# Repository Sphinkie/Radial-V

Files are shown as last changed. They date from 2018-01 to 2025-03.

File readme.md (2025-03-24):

# Radial-V

## Présentation

Remise en fonctionnement d'un poste de TSF, avec radio FM, player MP3, et afficheur LCD.

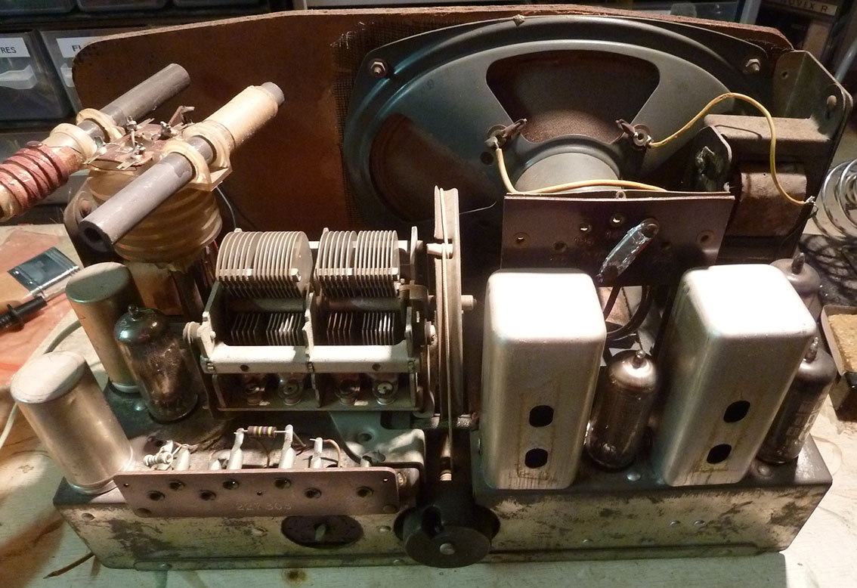
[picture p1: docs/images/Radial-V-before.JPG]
Radial-V-before


## Fabrication

Plusieurs éléments ont été réalisés: logiciel, circuits électroniques et supports en PLA.

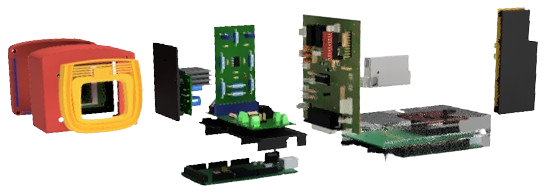
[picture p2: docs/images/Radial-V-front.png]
Radial-V-front


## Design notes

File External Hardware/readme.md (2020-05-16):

# RADIAL-V

## External Hardware

Ce dossier contient les cartes électroniques (shields) achetés pour construire le Radial-V:

* Amplificateur Audio
* Cartes Arduino Mega
* Radio FM
* Player MP3
* Ecran TFT

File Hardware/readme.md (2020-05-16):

# RADIAL-V
## Schematics

Ce repository contient l'ingénérie des différents circuits imprimés réalisés.

##Fabrication des PCB

Pour générer avec [kiCad](https://kicad-pcb.org/ "open source CAO software" ) les fichiers à envoyer à [JLB PCB](https://jlcpcb.com/	"PCB assembly from 2$"):

**kiCad → Pcbnew → File → Plot...**

* Plot format: Gerber
* Output directory: Gerber\
* Included layers: F.Cu B.Cu F.SilkS B.SilkS F.Mask B.Mask Edge.Cuts
* Plot footprint values
* Plot footprint references
* Exclude PDB edge layer from other layers
* Exclude pads from silkscreen

**Plot**
* Generate Drill Files...
* Generate Drill Files

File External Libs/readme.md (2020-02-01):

# Radial-V

## Utilisation des librairies:

### Possibilité 1:

Ajouter la librairie à l'environnement IDE Arduino.

Menu -> Include Library -> Add .zip library ...

`#include <NewLib.h>`

### Possibilité 2:

Ajouter manuellement la librairie à l'environnement IDE Arduino.

Dezipper la librarie dans `Documents\Arduino\libraries` et relancer l'IDE Arduino.

`#include <NewLib.h>`

### Possibilité 3:

Donner le chemin de la librairie (*à vérifier*):

`#include "..\lib\NewLib.h"`

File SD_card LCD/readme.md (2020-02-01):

# RADIAL-V

## SD Card LCD

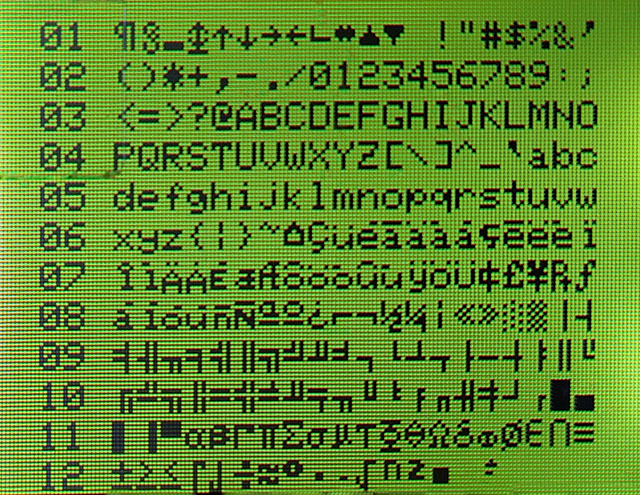
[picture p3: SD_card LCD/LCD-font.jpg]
Background sample


Ce dossier contient les éléments nécessaires pour la carte SD du shield "Ecran LCD":

* **/Preparation** - Différents elements utiles à la préparation de la carte SD (pictos, images de fond...)
* **/SD-card** - Contenu typique de la carte SD.

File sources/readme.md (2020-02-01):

# RADIAL-V

## Code source

* **/Radial-V** - Ce repository contient les sources du programme pour l'Arduino 1 (*master*). Il s'agit du programme principal.

* **/Radial-Screen** - Ce repository contient les sources du programme de l'Arduino 2 (*slave*). Ce programme est chargé de l'affichage des informations sur l'écran LCD.

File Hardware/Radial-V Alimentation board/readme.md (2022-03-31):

# RADIAL-V

## Alimentation Board

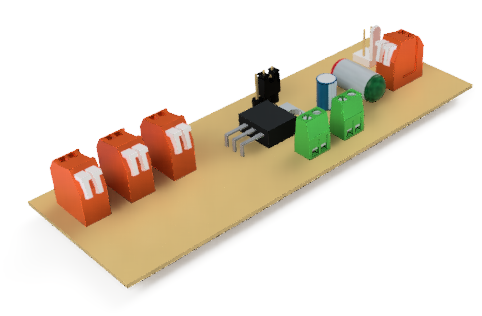
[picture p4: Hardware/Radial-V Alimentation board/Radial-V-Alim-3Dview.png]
Radial-V-Alim-3Dview


Cette carte distribue l'alimentation **5v** vers les autres cartes du système et le **12v** vers les amplicateurs audios.

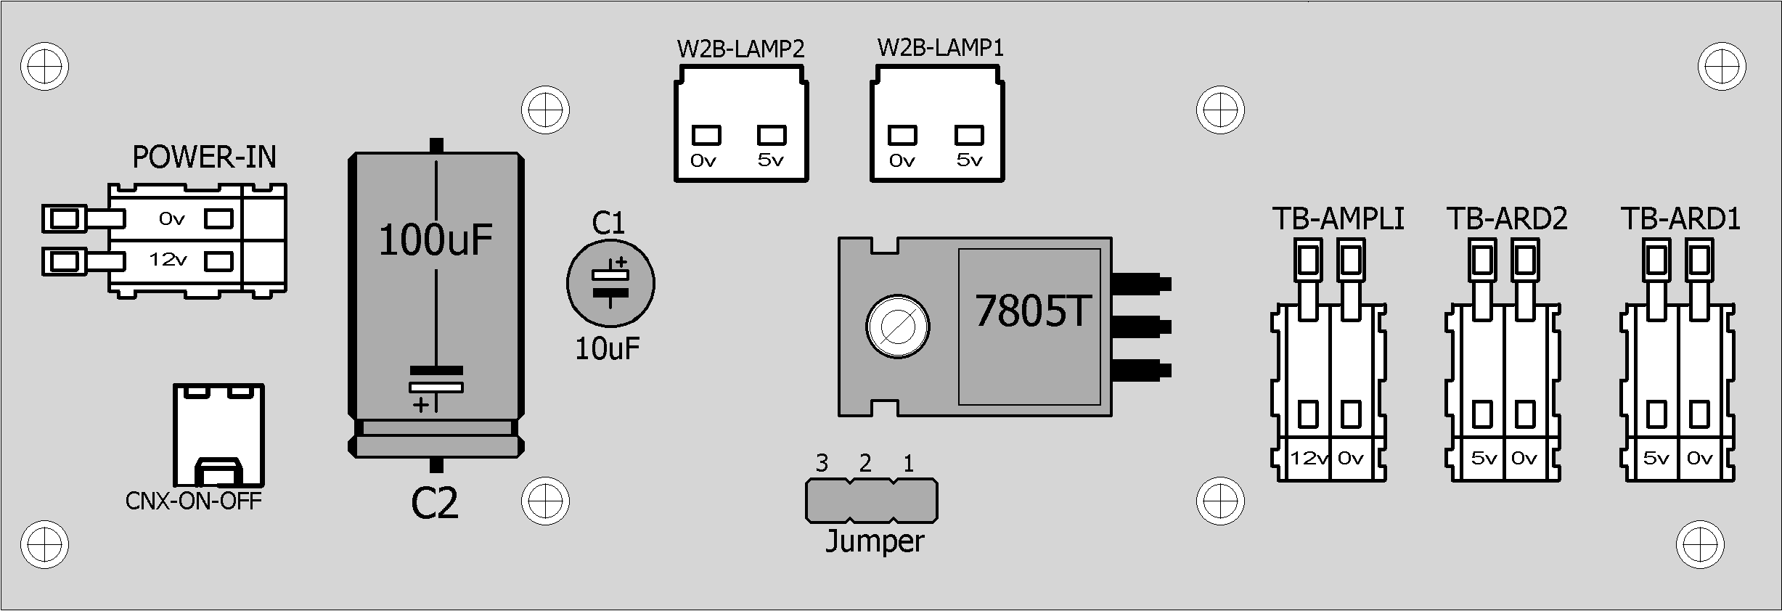
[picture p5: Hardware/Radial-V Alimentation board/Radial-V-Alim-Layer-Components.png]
Radial-V-Alim-Layer-Components


### Les Entrées:
* POWER-IN : Alimentation externe 12v (VCC)
* CNX_ON_OFF : Bouton ON/OFF externe
* Jumper: Permet d’alimenter les Arduino en VCC (12v) ou en +5v

## Schematic & PCB

Compatibles avec le logiciel **Eagle**.

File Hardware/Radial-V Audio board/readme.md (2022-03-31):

# Radial-V

## Carte "Audio-Board"

Cette carte fait passer la sortie audio (en provenance de la carte "Extension Bus") par un préamplificateur (optionnel), un potentiomètre de volume, et un Amplificateur mono. Le haut-parleur (4 ou 8 ohms) peut être branché directement sur "Audio OUT".

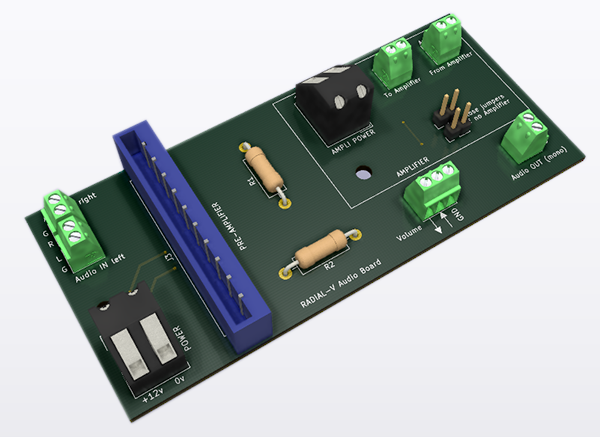
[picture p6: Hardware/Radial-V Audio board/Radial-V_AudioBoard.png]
Radial-V Audio Board


### Schéma d'implémentation

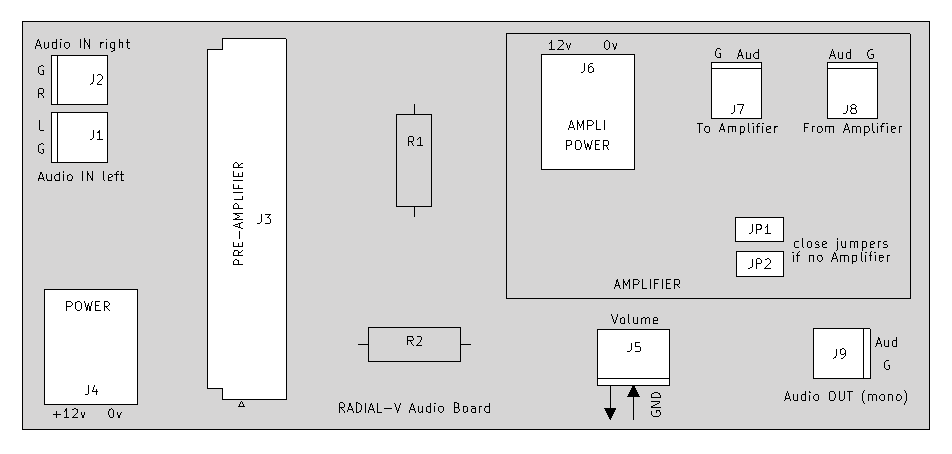
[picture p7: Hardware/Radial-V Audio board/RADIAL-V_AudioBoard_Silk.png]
RADIAL-V Audio Board Silk


Note: Le PréAmplificateur a été remplacé par une carte *Shunt*.

Schémas et PCB compatibles avec le logiciel **KiCad** (freeware).

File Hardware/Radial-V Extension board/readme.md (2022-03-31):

# RADIAL-V

## Extension Board

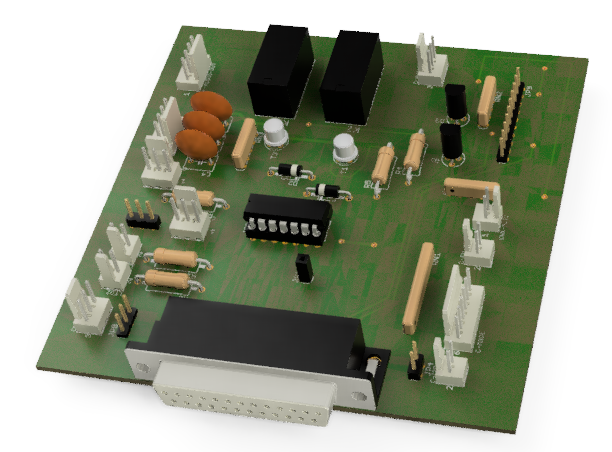
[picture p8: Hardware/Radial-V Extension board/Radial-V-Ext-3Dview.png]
Radial-V-Ext-3Dview


Cette carte regroupe tous les capteurs et actuateurs (boutons, LEDs, etc) du système et les envoie sur une nappe 25 fils vers l'Arduino.

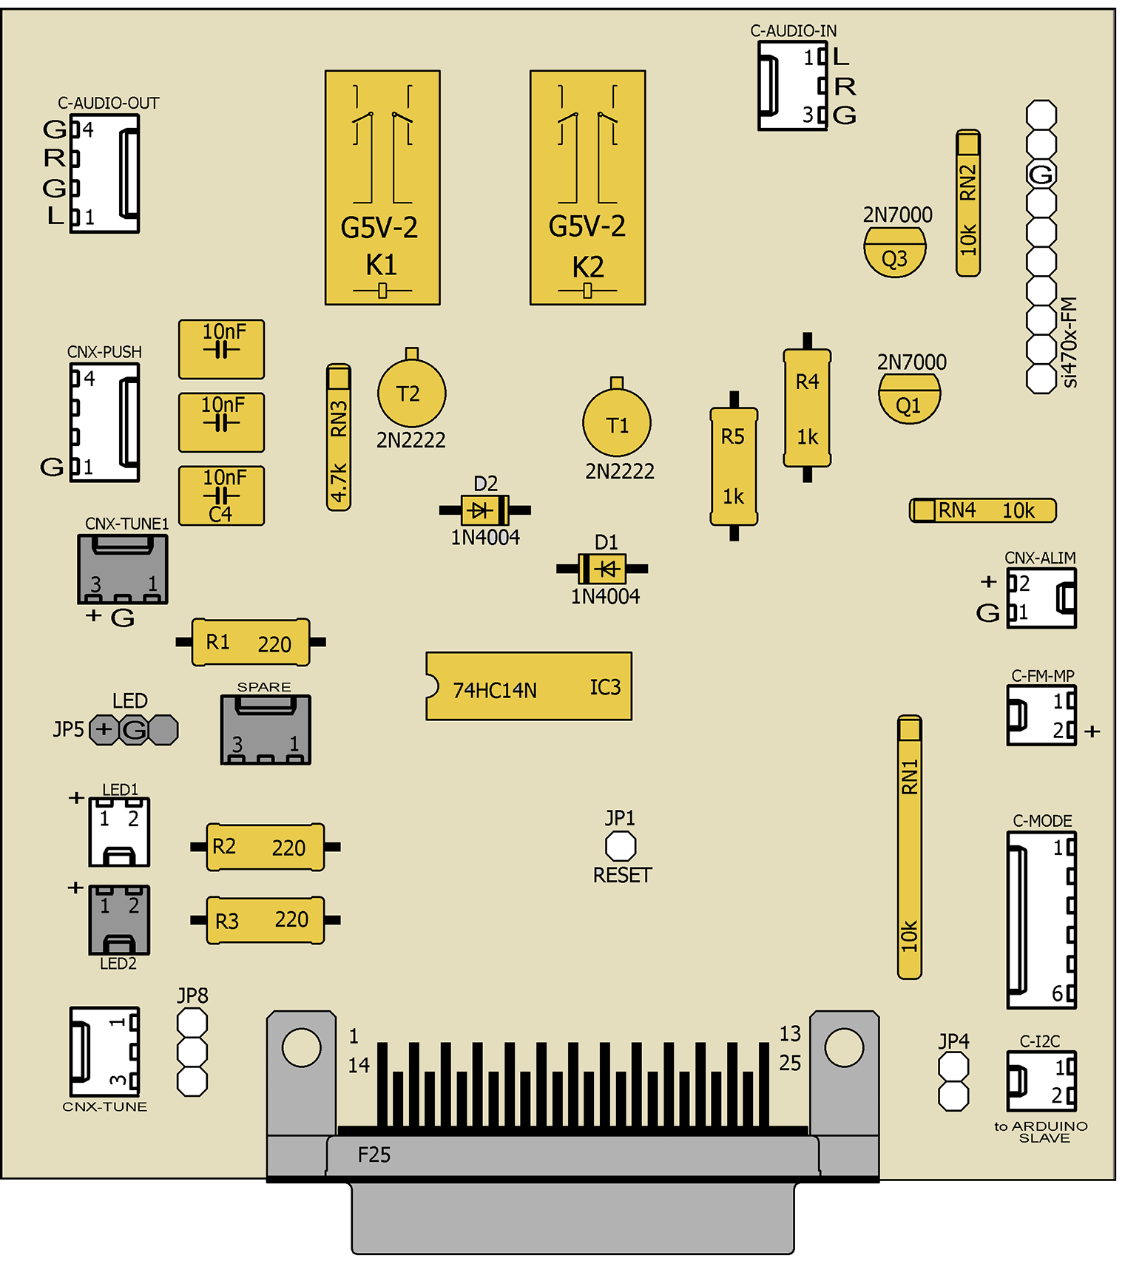
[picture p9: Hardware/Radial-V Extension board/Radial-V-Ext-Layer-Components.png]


Le circuit intégré 74HC14 est un *trigger de Schmitt inversé* qui, associé aux capacités, supprime les rebonds des boutons poussoirs, et transforme les impulsions en signaux carrés propres inversés (*active high*).  
Les *relais* servent à commuter le signal audio de sortie soit de la source "Carte MP3", soit de la source "Carte radio FM".  
Les composants *grisés* sont des spares non utilisés.

Schémas et PCB compatibles avec le logiciel **Eagle**.

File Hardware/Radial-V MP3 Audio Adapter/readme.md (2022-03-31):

# Radial-V

## Mini-Carte "Audio-Adapteur"

Cette minicarte réalise une adaptation du signal audio entre la carte MP3 et la carte audio d'amplification, telle que recommandée dans la documentation de la carte MP3.

*En particulier, le GNDbuf sortant de la carte MP3 ne doit pas être relié à la masse, ni utilisé.*

La carte a été fabriquée sur un Veroboard (pas de PCB).

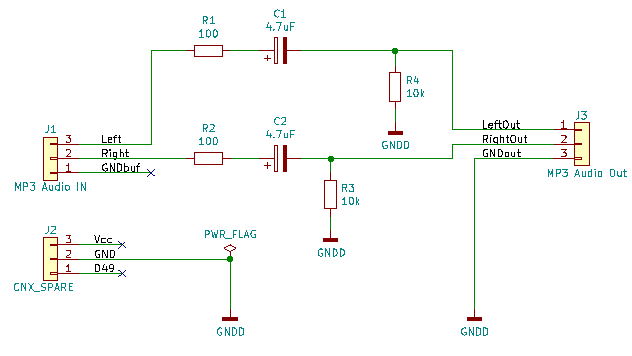
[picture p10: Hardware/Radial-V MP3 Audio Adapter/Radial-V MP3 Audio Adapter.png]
Radial-V MP3 Audio Adapter


Le branchement sur le connecteur *CNX_SPARE* permet de récupérer un signal GND.

Schémas et PCB compatibles avec le logiciel **KiCad** (freeware).

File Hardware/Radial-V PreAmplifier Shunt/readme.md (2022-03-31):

# Radial-V

## Mini-Carte "PreAmplifier Shunt"

Le préamplificateur initialement prévu s'est avéré inutile: le signal en sortie de l'ampli étant alors trop puissant. Le préamplificateur a donc été remplacé par cette mini-carte de *shunt*.

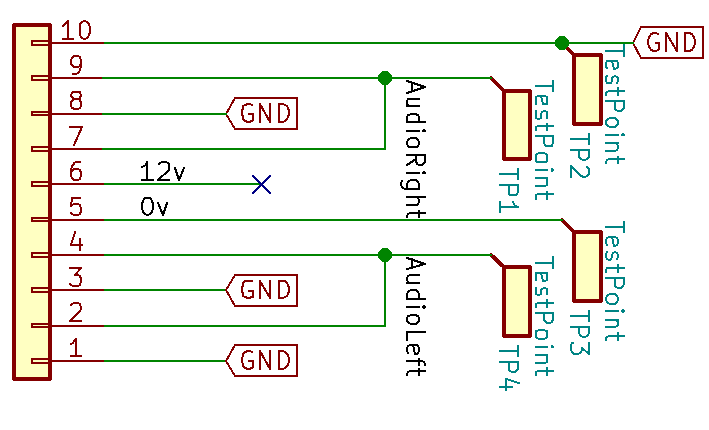
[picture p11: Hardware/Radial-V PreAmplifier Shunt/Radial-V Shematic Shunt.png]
Radial-V Shematic Shunt

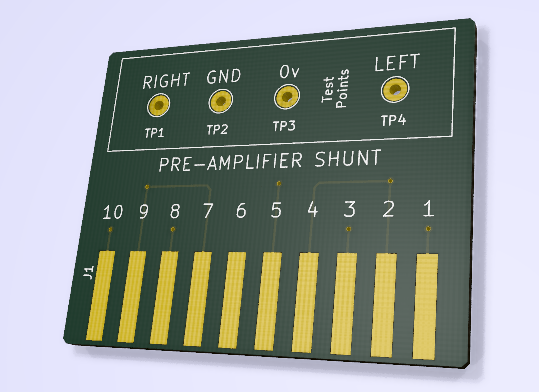
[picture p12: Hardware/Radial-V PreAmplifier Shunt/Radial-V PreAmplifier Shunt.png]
Radial-V PreAmplifier Shunt


Schémas et PCB compatibles avec le logiciel **KiCad** (freeware).

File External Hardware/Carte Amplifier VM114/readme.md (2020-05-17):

# RADIAL-V

## Amplifier Board

Module Amplificateur Audio MONO (7W avec HP 4ohms / 4W avec HP 8ohms).

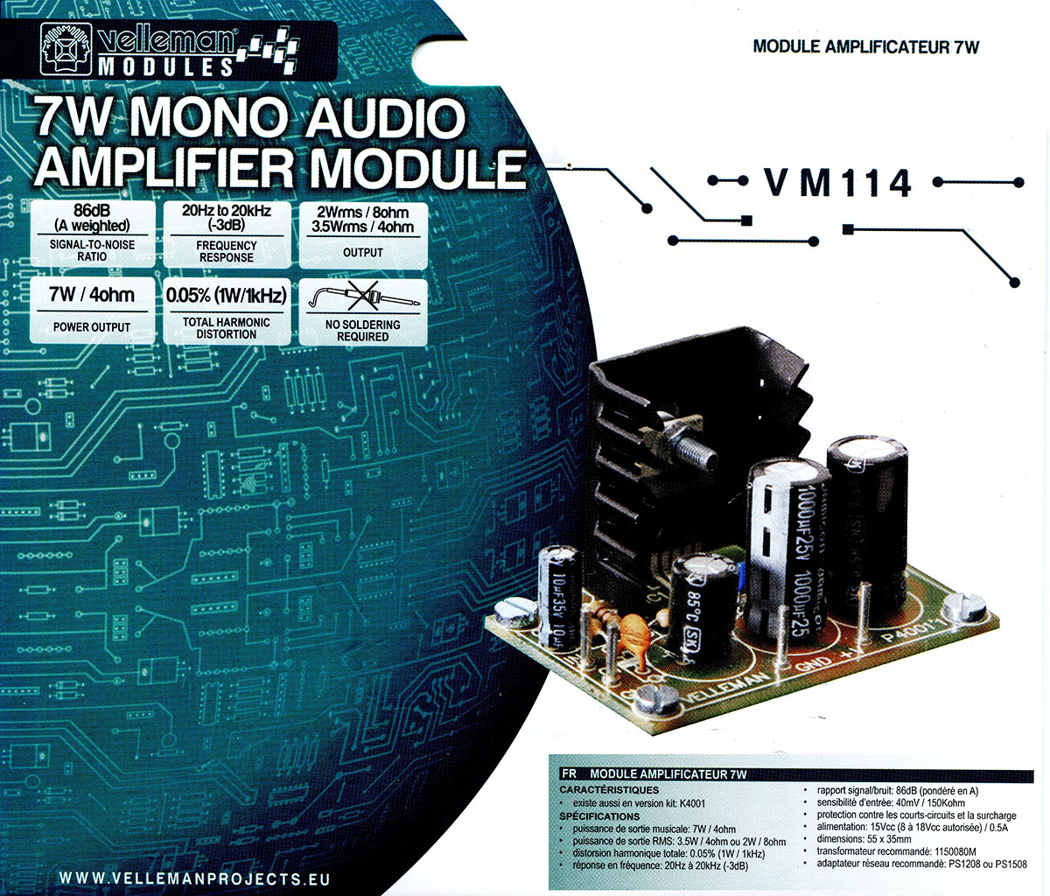
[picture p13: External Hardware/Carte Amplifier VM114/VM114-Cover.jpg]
Kit Velleman


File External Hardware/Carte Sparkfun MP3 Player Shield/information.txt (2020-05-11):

-- Introduction
-----------------
The Arduino SFEMP3Shield Library is a driver for VSLI's VS10xx, implemented as a Slave co-processor to audio decode streams of Ogg Vorbis/MP3/AAC/WMA/FLAC/WAVMIDI formats, across the SPI bus of the Arduino, along with mixing input signals. Principally this library is developed for the VS1053, where it may be compatible with other VS10xx's

Initial development was implemented on an Arduino 328 UNO/Duemilanove with a SparkFun MP3 Player Shield. Where additional support has been provided for Arduino base systems and Shields. Hardware and documentation is provided as to how to implement these. Where this driver is modular in concept to allow ready porting to other Arduino or Wiring platforms.

-- Contributors
-----------------
Nathan Seidle, www.sparkfun.com
Bill Porter, www.billporter.info
Michael Flaga, www.flaga.net
Wade Brainerd

-- Software Requirements
------------------------
- Arduino IDE
- The most current SFEMP3Shield Driver
- SdFat Driver, while included a newer version may retrieved from SdFatLib' repository.
Optionally, used if Hardware Interrupts are not supported:
- SimpleTimer.h . library can be downloaded from for library.
- TimerOne.h . library can be downloaded from for library.

-- Hardware Requirements
------------------------
- 5V Arduino 328 UNO/Duemilanove or better.
- Shield or breakout with appropiate pins wired up.
- Shield or breakout for SdCard
- SdCard FAT formatted with valid Audio files and filenames
See Hardware for alternative solutions.

Note
This library was originally developed on IDE 0.2x, later ported to 1.x and best support on IDE 1.5.0+ going forward. Compatibility was lost with use of the Serial.print(F("...")) and can be restored by replacing it with SdFat's PgmPrint function

-- Installation
------------------
Unzip and place './SFEMP3Shield' and './SdFat' folder into your 'C:/Users/{user name}/Documents/Arduino/libraries' folder or '{Arduino IDE path}/hardware/libraries" or {Arduino IDE path}/libraries" directory.
Along with SimpleTimer and or TimerOne if needed. 
Restart the Arduino IDE, and open up the example sketch.
Copy the contents of this projects the './plugins' folder onto the root of the SdCard to be used. Along with desired audio files named appropriately; track001.mp3 through track009.mp3.
The plugins and audio files are not needed to be placed into the Arduino directories as they are not directly a part of the compiled project.
Start IDE, load Example MP3Shield_Library_Demo.ino, select appropriate Board, Serial Port, Compile, load, run Serial Monitor at 115200 baud rate.
May need to Reset target Arduino and wait for Menu.
An example is provided in the SFEMP3Shield/examples folder. Which is developed to test SFEMP3Shield and illustrate its various common uses.

-- Hardware
---------------
As mentioned the initial and principal support of this library is with Arduino 328 UNO/Duemilanove with a SparkFun MP3 Player Shield. Although various other boards and shields may be implemented by customing the SFEMP3ShieldConfig.h file.

-- Arduino Bare Touch
----------------------
Support for Bare Conductive's Touch Board is provided and documented in SFEMP3ShieldConfig.h.

Note
Reference Arduino Leonardo Board's note about example files.

--Arduino Mega Board
-----------------------
Support for Arduino and Seeeduino Mega's are documented in SFEMP3ShieldConfig.h, which simply REQUIRES additional jumpers. As the SPI are not on the same pins as the UNO/Duemilanove.

-- Arduino Leonardo Board
-------------------------
Support for Arduino Leonardo's are afflicted by having the SPI and INT0 pins not routed to the same pins as the UNO/Duemilanove. This is similar to the Arduino Mega. Which simply REQUIRES additional jumpers, as documented in SFEMP3ShieldConfig.h to correct the SPI. The swapping of INT0/INT1 is automatically corrected based on the Leonardo's processor type of AVR_ATmega32U4 being detected.

Note
While the Leonardo has the same amount of physical program space as the UNO, it actually has less space available for use. As it uses approximately 4K, for core library USB features. Where there is adaquate space available for typical applications, the provided example files MP3Shield_Library_Demo.ino and FilePlayer.ino will compile a reduced set of examples based on the processor type of AVR_ATmega32U4 being detected. This is only for the demonstration, and other sketchs may call any of these functions, given its environment.
Arduino Pro 5V vs 3V

SFE Arduino Pro's while similar to UNO/Duemilanove's pin outs, they are available in either 5V or 3.3V. Where the SFE MP3 Player Shield requires 5V and locally generating the needed 3.3V and 1.8V for the VS10xx chip. Noting that 3.3V Pro's do not supply 5V, this causes a problem. It is possible to modify the shield as to use base Arduino supplied 3V's.

-- SparkFun MP3 Player Shield
-----------------------------
SparkFun MP3 Player Shield should just work out of the box (bag) with a Arduino 328 UNO/Duemilanove, with Interrupts.

-- Seeduino MP3 Player Shield
-----------------------------
Support for Seeduino MP3 Player Shield please see SEEEDUINO and may require additional libraries, as per Requirements

-- MP3-4NANO Shield
-------------------
Support for Gravitech MP3-4NANO shield please see GRAVITECH

-- Limitations.
---------------
The SPI Bus: The configuration of the VS10xx chip as a Slave on the SPI bus, along with the SdCard on that same bus master hosted by the Arduino. See Performance
Non-Blocking: The controlling sketch needs to enquire via SFEMP3Shield::isPlaying as to determine if the current audio stream is finished or still playing. This is actually good and a result of the library being non-blocking, allowing the calling sketch to simply initiate the play of a desired audio stream from SdCard by simply calling playTrack or playMP3, of the desired file, and move on with other RealTime issues.
Multi-Chip VS10xx support: Not at this time. There are too many issues with member functions of the SFEMP3Shield class requiring to be static.
Audio Input Most commericially available shields at this time do not support either Line Level or Microphone Input. With the exception of the Seeeduino MP3 Shield and other home made shields. Where as the below admx____.053 and SFEMP3Shield::ADMixerLoad and SFEMP3Shield::ADMixerVol are provided for such devices. Otherwise the example MP3Shield_Library_Demo.ino has these lines commented out in setup(). As to reduce complications. To re-enable simply uncomment.
Recording As most commericially available shields do not support audio input this feature has not been implemented.

-- Todo:
--------
- Support Audio Recording.

-- Performance
--------------
Understanding that every byte streamed to the VS10xx needs also to be read from the SdCard over the same shared SPI bus, resulting in the SPI bus being less than half as efficient. Along with overhead. Depending upon the Bitrate of the file being streamed to the VSdsp, there is only so much Real Time available. This may impact the performance of high bit-rate audio files being streamed. Additionally the Play Speed Multiplier feature can be exhausted quickly. Where on a typical UNO there is plenty of real-time to transfer good quality files, with CPU to spare for other tasks, assuming they do not consume too much time either.

The available CPU can be increased by either or both increasing the speed of the SPI and or the Arduino F_CPU. Where the Speed of the SPI is individually maintained by both this driver and SdFatLib. As not to or be interfered with each other and or other libraries using the same SPI bus. The SdCard can be increased from SPI_HALF_SPEED to SPI_FULL_SPEED argument in the SD.begin. Where this library will set the Read and Write speeds to the VSdsp correspondingly, based on F_CPU of the Arduino.

The actual consumed CPU utilization can be measured by defining the PERF_MON_PIN to a valid pin, which generates a low signal on configured pin while servicing the VSdsp. This is inclusive of the SdCard reads.

The below table show's typical average CPU utilizations of the same MP3 file that has been resampled to various bit rates and using different configurations. Where a significant difference is observed in performance.

BitRate	SdCard	Refilling	IDLE
128K	Half	12%	88%
128K	Full	10%	90%
96K	Full	7%	93%
56K	Full	4%	96%
Note
Only F_CPU of 8MgHz and 16Hz are supported. Others will default to SPI_CLOCK_DIV2, assuming 4MgHz.

-- Plug-Ins and Patches
------------------------
The VS10xx chips are DSP's that run firmware out of ROM, that is internal to the VS10xx chip itself. Where the VSdsp's RAM can additionally be loaded with externally provided firmware and executed, also known as patches or plug-ins, over the SPI port and executed. This allows the VSdsp to have a method for both fixing problems that may exist in the factory ROM's firmware and or add new features provided by VLSI's website. It is even possible to write your own custom VSdsp code, using there Integrated Development Tools (VSIDE).

vs_plg_to_bin.pl is a perl script, that is provided in this library to run on your PC, to read and digest the .plg files converting them to raw binary as to be read by SFEMP3Shield::VSLoadUserCode() from the SdCard. Allowing updates to the VSDsp into its volatile memory after each reset. These updates may be custom features or accumulated patches.

By storing them on the SdCard these plug-ins do not consume the Arduino's limited Flash spaces

Below are pre-compiled binary's of corresponding provided VSLI patches/plugins. The filenames are kept short as SdCard only support 8.3.

.\pcm.053       .\vs1053-pcm110\vs1053pcm.plg
.\admxleft.053  .\vs1053b-admix130\admix-left.plg
.\admxmono.053  .\vs1053b-admix130\admix-mono.plg
.\admxrght.053  .\vs1053b-admix130\admix-right.plg
.\admxster.053  .\vs1053b-admix130\admix-stereo.plg
.\admxswap.053  .\vs1053b-admix130\admix-swap.plg
.\patchesf.053  .\vs1053b-patches195\vs1053b-patches-flac.plg
.\patches.053   .\vs1053b-patches195\vs1053b-patches.plg
.\rtmidi.053    .\vs1053b-rtmidistart\rtmidistart.plg
.\eq5.053       .\vs1053b-eq5-090\vs1053b-eq5.plg

-- Note
-------
All plugins should be placed in the root of the SdCard.
patches.053 is a cumulative update correcting many known troublesome issues. Hence patches.053 is attempted in SFEMP3Shield::vs_init.
VSLI may post periodic updates on there software website
Perl is natively provided on Linux systems, and may be downloaded from Active Perl for windows systems.
See Also
about Analog to Digital Mixer (e.g. admx____.053) please note Limitations.

-- Troubleshooting
------------------
The below is a list of basic questions to ask when attempting to determine the problem.

- Did it initially PRINT the available RAM and Full Help Menu?
The MP3Shield_Library_Demo.ino example should initially provide a opening print indicating the amount of available SRAM and full menu help. If you don't see this the problem is between your Target and IDE. And likely not this library
Is Serial Monitor set to the correct tty or com port and 115200 baud rate? Did you change the baud rate?
Reset the Arduino after Serial Monitor is open or send any key. It may have printed these prior to the Serial Monitor being started.

- WHAT is the Error reported?
  Is the Error Code is indicating a file problem.

- Are the filenames 8.3 format? 
  See below warning. See also Error Codes.

- Did the SdCard LOAD?
  Try reseating your SdCard.

- Is MP3player.begin() locking up, in setup()?
  Are you trying to update from a version prior to 1.01.00?

- Why does my Serial Monitor display: "...do not have a sd.begin in the main sketch, See Trouble Shooting Guide."
- Why do I have a Compiler Error: "...undefined reference to `sd'"
- Why is the last thing printed to the Serial Monitor: "Free RAM = 1097 Should be a base line of 1095, on ATmega328 when using INTx" then nothing...
  Versions after 1.01.00 require the SdFat::begin() to be initialized in the main sketch.ino, as shown in the below example. This provides more immediate access to the SdCard's files by the main sketch. However, if not done there is no immediate compiler error and the sketch will lock up after as it attempts SFEMP3Shield::begin.
  ...
  SdFat sd; // newly required in 1.01.00 and higher
  void setup() 
  {
     if(!sd.begin(SD_SEL, SPI_HALF_SPEED)) sd.initErrorHalt(); // newly required in 1.01.00 and higher
     if(MP3player.begin() != 0) {Serial.print(F("ERROR"));
     ...
	 
- Is it FAT (FAT16 or FAT32)?
  If the Error Code is indicating problems with the INIT, VOLUME or Track not being successful. It is recommend to use SdFat Example Library's QuickStart.ino as to see if it can access the card. Additionaly, SdInfo.ino may indicate if it can mount the card. Which may then need to formatted in FAT16 or FAT32. Where SdFormatter.ino can do this for you.
  
- Are the needed files on the root?
  Remember to put patch and audio track files on the SdCard after formatting.

- "Error code: 1 when \b trying to play track"
  See the above Limitations. about Non-Blocking.
  Remember to check your audio cables and volume.
  
- "Warning: patch file not found, skipping."
  See the Plug Ins and Patches
  
- Why do I only hear 1 second of music, or less?
  This symptom is typical of the interrupt not triggering the SFEMP3Shield::refill(). 
  I bet repeatidly sending a track number will advance the play about one second at a time, then stop.
  
- What board is it? 
  Check Hardware Limitations. about Interrupts.
  
- Are you trying the SFE provided test files ? Or some homemade mp3 files? 
  The SFE test files are nice as they are Immediately LOUD.
  Interrupt problems may cause mp3 files that have a quiet lead in (or ramp up of volume) to be falsely diagnosed as not playing at all. Where the first 1 second may not be loud enough to be heard.

- Free RAM = 1090 Should be a base line of 1094
  As a courtesy and good practice the provided example MP3Shield_Library_Demo.ino prints out the available remaining RAM, not statically allocated. And the actual available amount may depend on specific processor, IDE version, libraries and or other factors. A Uno built with IDE version 1.0.2 should have approximately 1094 bytes available from the example as is. And a Mega using a 2560 may show 6713, as it has more RAM.

-- Note
--------
This library makes extensive use of SdFat Library as to retrieve the stream of audio data from the SdCard. Notably this is where most failures occur. Where some SdCard types and manufacturers are not supported by SdFat. Though SdFat Lib is at this time, supporting most known cards.

-- Warning
-----------
SdFatLib only supports 8.3 filenames. Long file names will not work. Use the 'd' menu command to display directory contents of the SdCard. "longfilename.mp3" will be converted to "longfi~1\.mp3" . Where one can not predict the value of the 1. The DOS command of "dir \c /x" will list a cross reference, so that you know exactly, what is what.

-- Error Codes
--------------
Error Codes typically are returned from this Library's object's in place of Serial.print messages. As to both save Flash space and Serial devices may not always be present. Where it becomes the responsibility of the calling sketch of the library's object to appropiately react or display corresponding messages.

- begin function:

The following error codes return from the SFEMP3Shield::begin() member function.

0 OK
1 *Failure of SdFat to initialize physical contact with the SdCard
2 *Failure of SdFat to start the SdCard's volume
3 *Failure of SdFat to mount the root directory on the volume of the SdCard
4 Other than default values were found in the SCI_MODE register.
5 SCI_CLOCKF did not read back and verify the configured value.
6 Patch was not loaded successfully. This may result in playTrack errors

- Deprecated:
Error codes 1,2,3 due to use of sd.begin() as global, starting version 1.1.0

- Playing functions:

The following error codes return from the SFEMP3Shield::playTrack() or SFEMP3Shield::playMP3() member functions.

0 OK
1 Already playing track
2 File not found
3 indicates that the VSdsp is in reset.
Skip function:

The following error codes return from the SFEMP3Shield::skipTo()member function.

0 OK
1 Not Playing track
2 Failed to skip to new file location

-- Support:
-----------
The code has been written with plenty of appropiate comments, describing key components, features and reasonings in Doxygen markdown style as to autogenerate this html suppoting document. Which is loaded into the repositories' gh-page branch to be displayed on the projects's GitHub Page.

Additional support may be reached from any of the following: Please read through this document and refering linked resources.

Bills WordPress forum
Flaga's github Issues forum
Bill's github Issues forum

-- Note
--------
Problems with SdCard initializing is outside the scope of this library. 
SdFatLib' repository was selected being the best choice.

-- References
--------------
See Also:

- VS1053 Datasheet.
- VLSI's DSP support Forum.
- VLSI's software download of Apps, Patches, Plugins and tools.
- VS10XX AppNote: Connecting analog outputs.
Sparkfun Electonics:
- MP3 Player Shield DEV-10628.
- MP3 Player Shield Landing Page / Tutorials.
- SFE's Schematic.
Adafruit Industries:
- The Arduino site.
- The ATmega328 datasheet.

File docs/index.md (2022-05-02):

# Vintage MP3 player

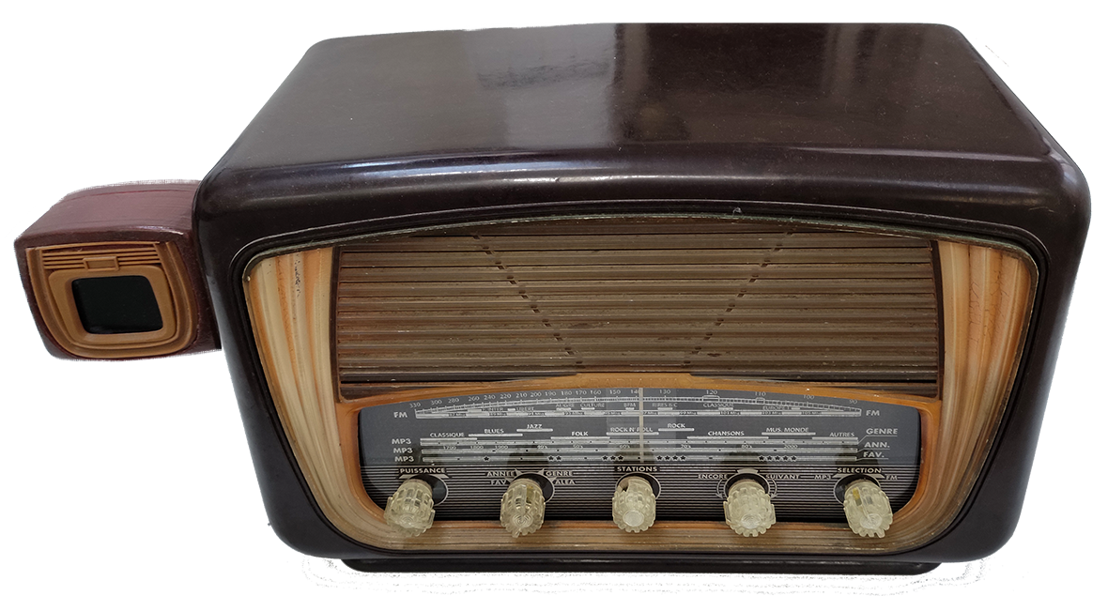
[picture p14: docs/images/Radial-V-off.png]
Radial-V-off


The Radial-V MP3 player is a vintage broken radio found on a flea market, and restored as a MP3 player and FM Tuner.
I also add a color LCD screen , to display info on the playing clips.

[Find more pictures here](webpages/pictures)...

## Technical data

[Radial-V 3D Model](webpages\Radial-V.html) 

[List of Materials](webpages/bill_of_material)

## Installation

Upload the sketch into an Arduino Mega board.   

## Credits

Many thanks to the authors of the external libraries used for this project:  
* **Arduino** at [arduino.cc](https://www.arduino.cc)

# About me

Find my other softwares at [GitHub](https://sphinkie.github.io).

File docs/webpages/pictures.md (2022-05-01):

# Radial-V

Modelisation of all elements built for this project, positioned at their final place.

Some are 3D-models for the PLA printed supports, electronic boards  and homemade PCBs.

Front view:Radial-V-front

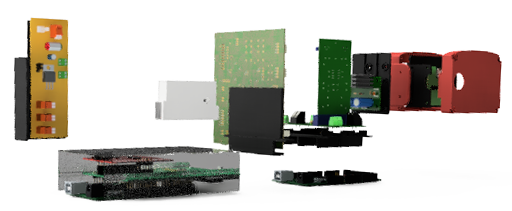
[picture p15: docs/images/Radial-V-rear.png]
Radial-V-rear
Rear view:

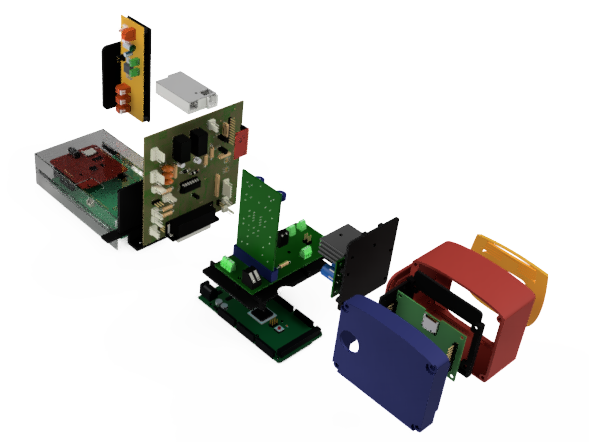
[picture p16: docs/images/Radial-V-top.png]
Radial-V-top
Perspective:

**[Back to home page](../index)**

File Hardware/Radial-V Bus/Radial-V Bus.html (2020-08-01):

# Bill Of Material

Generated by: Kicad Eeschema (5.1.5)-3

Shematic: D:\Mes Machines\Radial-V\Hardware\Radial-V Bus\Radial-V Bus.sch

Date: 08/06/2020 11:39:21

Component Count:13

Ref | Qty | Value | Library:Component name | Description | Library:Footprint name | Datasheet
ARD-C1 | 1 | POWER | Connector_Generic:Conn_01x08 | Generic connector, single row, 01x08 | Connector_PinHeader_2.54mm:PinHeader_1x08_P2.54mm_Vertical | ~
ARD-C2 | 1 | A7-A0 | Connector_Generic:Conn_01x08 | Generic connector, single row, 01x08 | Connector_PinHeader_2.54mm:PinHeader_1x08_P2.54mm_Vertical | ~
ARD-C3 | 1 | A15-A8 | Connector_Generic:Conn_01x08 | Generic connector, single row, 01x08 | Connector_PinHeader_2.54mm:PinHeader_1x08_P2.54mm_Vertical | ~
ARD-C4 | 1 | D22-D53 | Connector_Generic:Conn_02x18_Odd_Even | Generic connector, double row, 02x18, odd/even pin numbering scheme (row 1 odd numbers, row 2 even numbers) | Connector_PinHeader_2.54mm:PinHeader_2x18_P2.54mm_Vertical | ~
ARD-C5 | 1 | D21-D14 | Connector_Generic:Conn_01x08 | Generic connector, single row, 01x08 | Connector_PinHeader_2.54mm:PinHeader_1x08_P2.54mm_Vertical | ~
ARD-C6 | 1 | D0-D7 | Connector_Generic:Conn_01x08 | Generic connector, single row, 01x08 | Connector_PinHeader_2.54mm:PinHeader_1x08_P2.54mm_Vertical | ~
ARD-C7 | 1 | D8-D13 | Connector_Generic:Conn_01x08 | Generic connector, single row, 01x08 | Connector_PinHeader_2.54mm:PinHeader_1x08_P2.54mm_Vertical | ~
J1 | 1 | Conn_Alim | Connector_Generic:Conn_01x02 | Generic connector, single row, 01x02 | MesModules:Molex_KK-254_AE-6410-02A_1x02_P2.54mm_Horizontal | ~
J2 | 1 | Conn_Reset | Connector_Generic:Conn_01x02 | Generic connector, single row, 01x02 | Connector_JST:JST_EH_B2B-EH-A_1x02_P2.50mm_Vertical | ~
MP3-C1 | 1 | POWER | Connector_Generic:Conn_01x08 | Generic connector, single row, 01x08 | Connector_PinSocket_2.54mm:PinSocket_1x08_P2.54mm_Vertical | ~
MP3-C3 | 1 | I/O | Connector_Generic:Conn_01x08 | Generic connector, single row, 01x08 | Connector_PinSocket_2.54mm:PinSocket_1x08_P2.54mm_Vertical | ~
MP3-C4 | 1 | COMMS | Connector_Generic:Conn_01x08 | Generic connector, single row, 01x08 | Connector_PinSocket_2.54mm:PinSocket_1x08_P2.54mm_Vertical | ~
PL1 | 1 | Nappe | Radial-V_Bus-eagle-import:26H | Custom connector, double row, 02x13, David | MesModules:HE10-26P

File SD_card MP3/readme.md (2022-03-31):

# RADIAL-V

## SD Card MP3

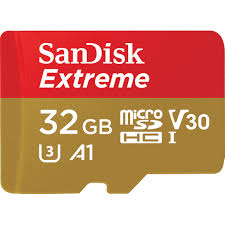
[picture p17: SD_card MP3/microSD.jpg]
carte microSD


La carte doit avoir un *file system* FAT16 ou FAT32, et des noms de fichier au format 8.3.

* **/Preparation** - Ce repository contient les éléments nécessaires pour la carte SD du shield **MP3 Player**:
  
  * Fichier audio utilisé par le programme (`NOISE.MP3`)
* Scripts et utilitaires pour générer le fichier `Catalog.ndx` utilisé par le programme.
  
* **/SD_Card** - Contenu typique de la carte SD: le fichier `Catalog.ndx` , un répertoire `Music`contenant tous les fichiers MP3 au format 8.3 et les patches VLSI pour le chipset audio.

## PlugIns pour la carte MP3 Player Shield

Les fichiers `*.053` sont des patchs correctifs du chipset audio, fournis par Sparkfun.

**Pour que les plugIns soient pris en compte à chaque reset du chipset, il faut les placer dans la racine de la carte SD**, sinon un message d'erreur `code 6: Patch was not loaded successfully` apparait au démarrage.

Dans la classe du player MP3 **SFEMP3Shield**, les plugins (surtout `patches.053`) sont chargés automatiquement par la méthode `VSLoadUserCode()` appelée par `begin()`.

Voir aussi la [documentation de référence de la carte MP3 player shield](http://mpflaga.github.io/Sparkfun-MP3-Player-Shield-Arduino-Library/index.html#Plug_Ins).

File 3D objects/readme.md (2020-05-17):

# RADIAL-V

## 3D models

Ce dossier contient les modèles imprimés en 3D pour la réalisation de la radio Radial-V (généralement: les supports).

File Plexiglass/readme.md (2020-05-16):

# RADIAL-V

## Façade Plexiglass

La face-avant de la radio est refaite, en gardant le design de la face-avant originale, mais en affichant des graduations adaptées aux nouvelles fonctionnalités du Radial-V.

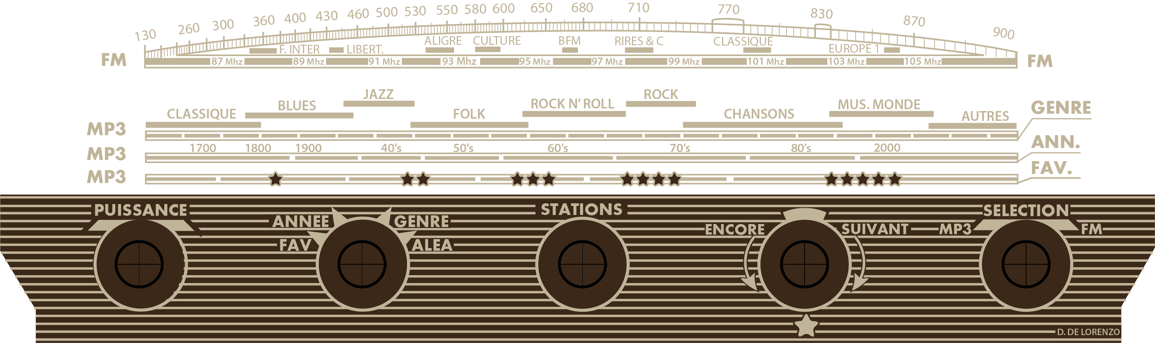
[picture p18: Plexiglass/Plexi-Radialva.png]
Model_Photo_1
 

## Fabrication

### Génération du .psd à partir du .ai

- Dans Illutratrator, exporter un fichier **.psd** avec les layers et sans lissage.
  (Dessin sans les hachures, et sans tracé du contour de découpe). 
- Ouvrir le fichier dans Photoshop: Dans le calque "fond brun", effacer le hachurage vert.
- Exporter en PNG avec couche Alpha.
  (**blanc = transparent**)
- Enregistrer

Dimensions : 303 x 93 mm

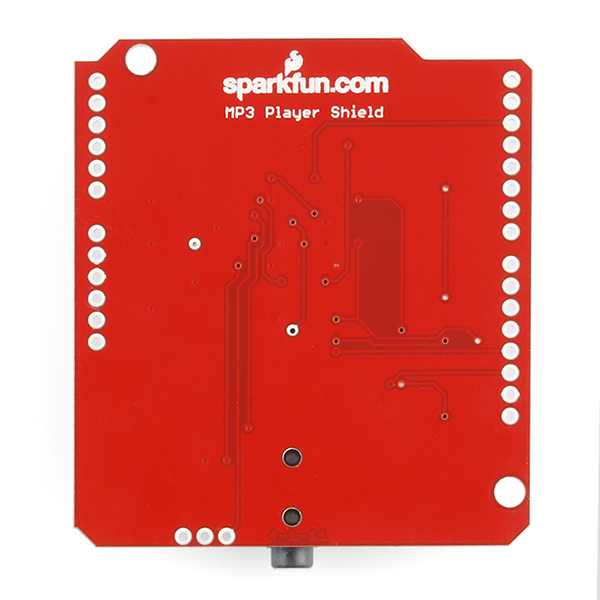
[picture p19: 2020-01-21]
External Hardware/Carte Sparkfun MP3 Player Shield/Pictures/10628-03-Workinga.jpg

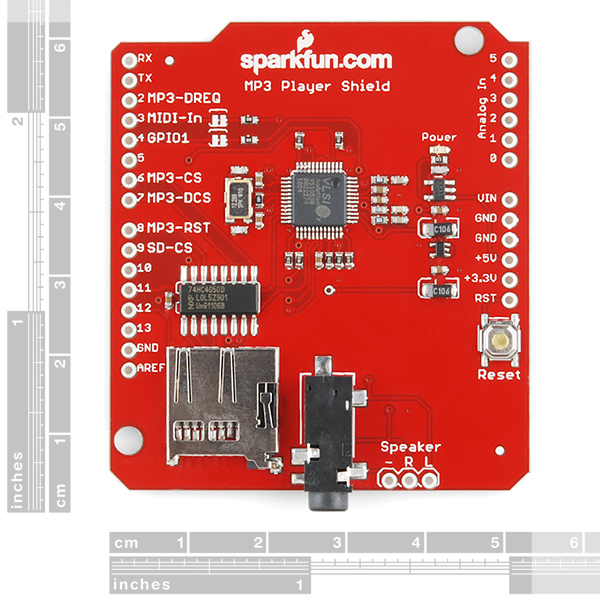
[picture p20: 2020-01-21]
External Hardware/Carte Sparkfun MP3 Player Shield/Pictures/10628-02-Workinga.jpg

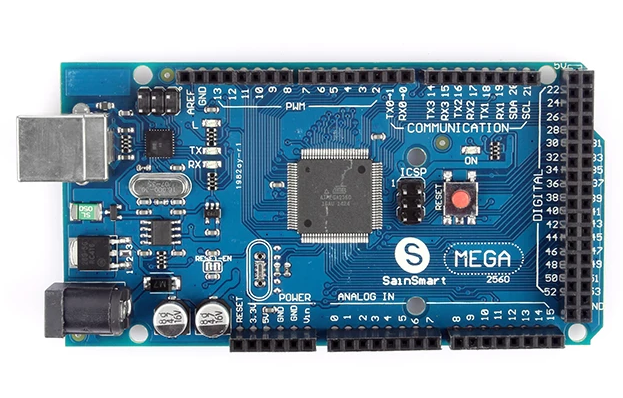
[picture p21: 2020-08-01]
External Hardware/Carte Arduino Mega/SainSmart_Arduino_Mega2560.png

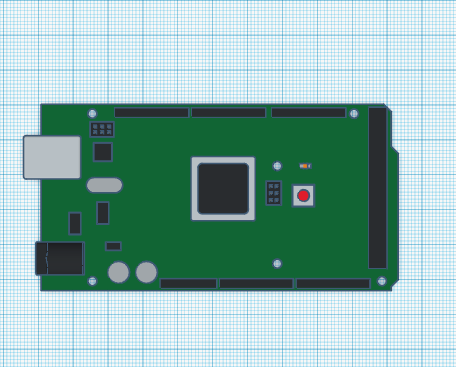
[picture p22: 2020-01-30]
External Hardware/Carte Arduino Mega/3D Model/ArduinoMega_2560.png

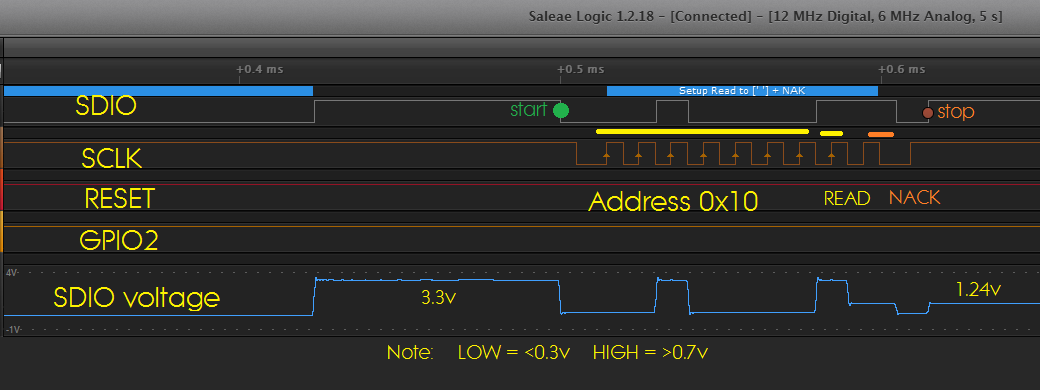
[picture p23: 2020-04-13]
External Hardware/Carte Sparkfun FM/Analyse I2C/Mesure RadialV-1.png

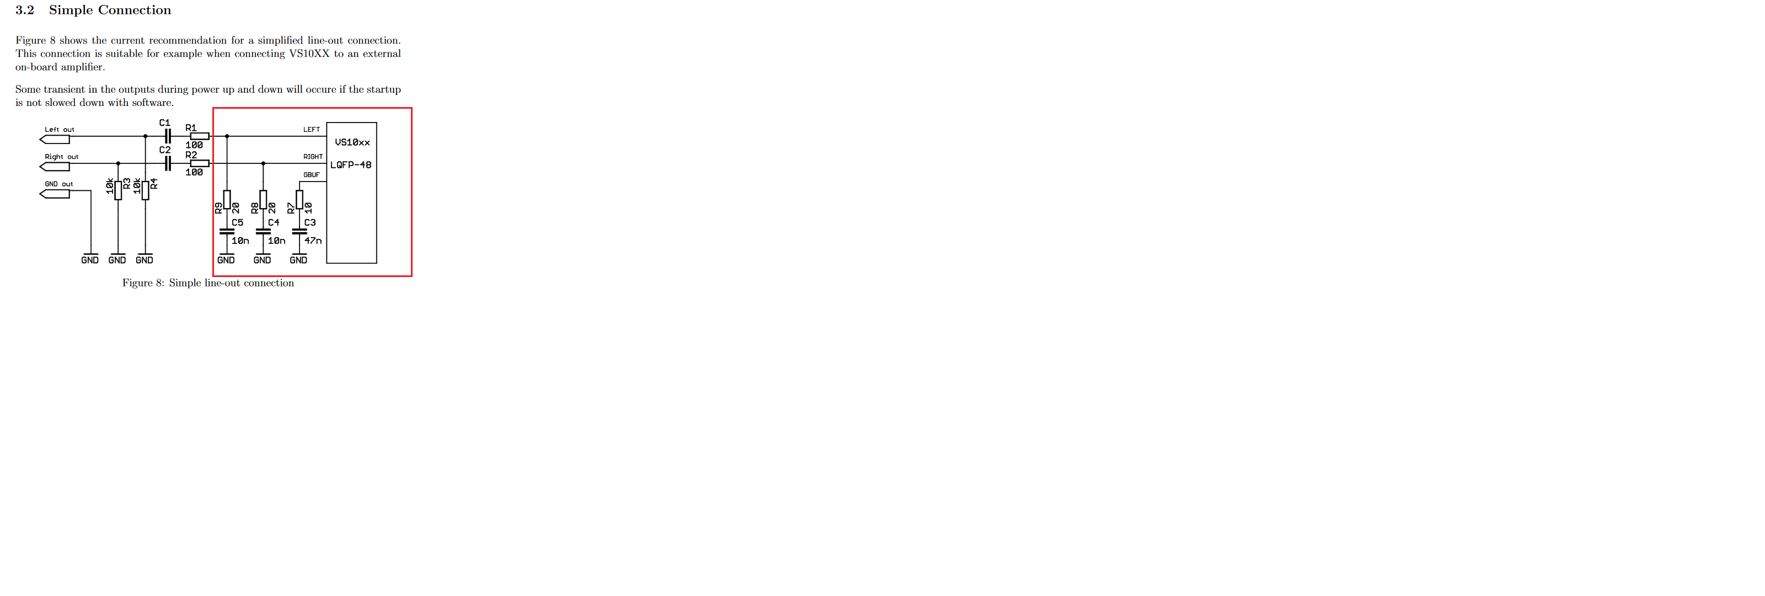
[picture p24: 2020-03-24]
External Hardware/Carte Sparkfun MP3 Player Shield/Documentation/line output connexion.png

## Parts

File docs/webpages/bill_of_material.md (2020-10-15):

# Bill Of Material

## Boards

* Arduino Mega x2
* Audio Amplifier (Kit Velleman VM114)
* TFT Screen 160x128
* MP3 player shield (sparkfun)
* FM Receiver  (sparkfun)

----

## Components for homemade PCBs

* Potentiometer
* Loud-Speaker
* LEDs
* Static Relays

**[Back to home page](../index)**

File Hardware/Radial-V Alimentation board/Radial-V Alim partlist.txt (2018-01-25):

Partlist

Exported from Radial-V Alim.sch at 27/12/2015 20:17

EAGLE Version 7.4.0 Copyright (c) 1988-2015 CadSoft

Assembly variant: 

Part       Value           Device          Package  Library       Sheet

A8-A15     ARDUINO         MA08-1          MA08-1   con-lstb      1
ALIM       22-27-2021-02   22-27-2021-02   6410-02  con-molex     1
C1         10uF            CPOL-EUB45181C  B45181C  rcl           1
C2         100uF           CPOL-EUB45181C  B45181C  rcl           1
CNX-ON-OFF 22-27-2021-02   22-27-2021-02   6410-02  con-molex     1
D14-D21    ARDUINO         MA08-1          MA08-1   con-lstb      1
D22-D53    ARDUINO         MA18-2          MA18-2   con-lstb      1
IC1        7805TV          7805TV          TO220V   linear        1
JK1        POWER-IN        DCJ0303         DCJ0303  con-jack      1
JP1        Jumper          JP2E            JP2      jumper        1
PIN-3V3    ARDUINO         PINHD-1X1       1X01     pinhead       1
PIN-D3     ARDUINO         PINHD-1X1       1X01     pinhead       1
PL1                        26H             26H      con-harting-h 1
RST        ARDUINO         PINHD-1X1       1X01     pinhead       1
W2B-AMPLI  C-GRID-02-70543 C-GRID-02-70543 70543-02 con-molex     1
W2B-ARD1   C-GRID-02-70543 C-GRID-02-70543 70543-02 con-molex     1
W2B-ARD2   C-GRID-02-70543 C-GRID-02-70543 70543-02 con-molex     1
W2B-LAMP1  C-GRID-02-70543 C-GRID-02-70543 70543-02 con-molex     1
W2B-LAMP2  C-GRID-02-70543 C-GRID-02-70543 70543-02 con-molex     1

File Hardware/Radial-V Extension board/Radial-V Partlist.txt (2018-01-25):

Partlist

Exported from Radial-V Ext.sch at 27/12/2015 20:11

EAGLE Version 7.4.0 Copyright (c) 1988-2015 CadSoft

Assembly variant: 

Part        Value          Device          Package      Library      Sheet

C-AUDIO-IN  22-27-2031-03  22-27-2031-03   6410-03      con-molex    1
C-AUDIO-OUT 22-27-2041-04  22-27-2041-04   6410-04      con-molex    1
C-FM-MP     22-27-2021-02  22-27-2021-02   6410-02      con-molex    1
C-I2C       22-27-2021-02  22-27-2021-02   6410-02      con-molex    1
C-MODE      22-27-2061-06  22-27-2061-06   6410-06      con-molex    1
C3          10nF           C-EU050-050X075 C050-050X075 rcl          1
C4          10nF           C-EU050-050X075 C050-050X075 rcl          1
C5          10nF           C-EU050-050X075 C050-050X075 rcl          1
CNX-ALIM    22-27-2021-02  22-27-2021-02   6410-02      con-molex    1
CNX-PUSH    22-27-2041-04  22-27-2041-04   6410-04      con-molex    1
CNX-SPARE   22-27-2031-03  22-27-2031-03   6410-03      con-molex    1
CNX-SPI     22-27-2031-03  22-27-2031-03   6410-03      con-molex    1
CNX-TUNE    22-27-2031-03  22-27-2031-03   6410-03      con-molex    1
D1          1N4004         1N4004          DO41-10      diode        1
D2          1N4004         1N4004          DO41-10      diode        1
IC3         74HC14N        74HC14N         DIL14        74xx-eu      1
JP4         I2C            PINHD-1X2       1X02         pinhead      1
JP5         LED            PINHD-1X3       1X03         pinhead      1
JP8         SPI            PINHD-1X3       1X03         pinhead      1
JP9         si470x-FM      PINHD-1X10      1X10         pinhead      1
K1          G5V-2          G5V-2           G5V-2        relay        1
K2          G5V-2          G5V-2           G5V-2        relay        1
LED1        22-27-2021-02  22-27-2021-02   6410-02      con-molex    1
LED2        22-27-2021-02  22-27-2021-02   6410-02      con-molex    1
Q1          2N7000         2N7000_TO92     TO-92        transistors  1
Q3          2N7000         2N7000_TO92     TO-92        transistors  1
R1          220            R-US_0411/15    0411/15      rcl          1
R2          220            R-US_0411/15    0411/15      rcl          1
R3          220            R-US_0411/15    0411/15      rcl          1
R4          1k             R-US_0411/15    0411/15      rcl          1
R5          1k             R-US_0411/15    0411/15      rcl          1
RN1         10k            G08R            SIL9         resistor-sil 1
RN2         10k            G04R            SIL5         resistor-sil 1
RN3         4.7k           G04R            SIL5         resistor-sil 1
RN4         10k            G04R            SIL5         resistor-sil 1
T1          2N2222         2N2222          TO18         transistor   1
T2          2N2222         2N2222          TO18         transistor   1
X1          ARDUINO        F25HPS          F25HP        con-subd     1

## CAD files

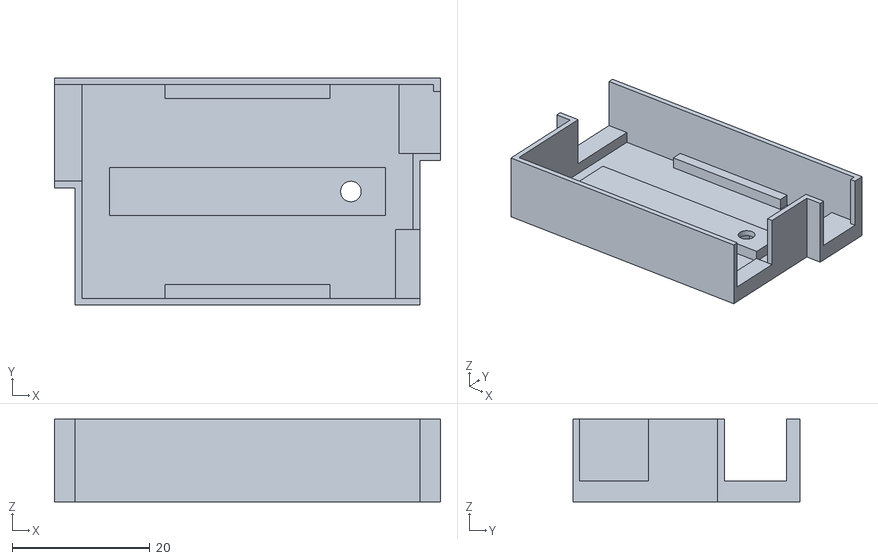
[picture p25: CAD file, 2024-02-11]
3D objects/Boitiers/Boitier_Adaptateur_Audio.stl
56.0 x 33.0 x 12.0

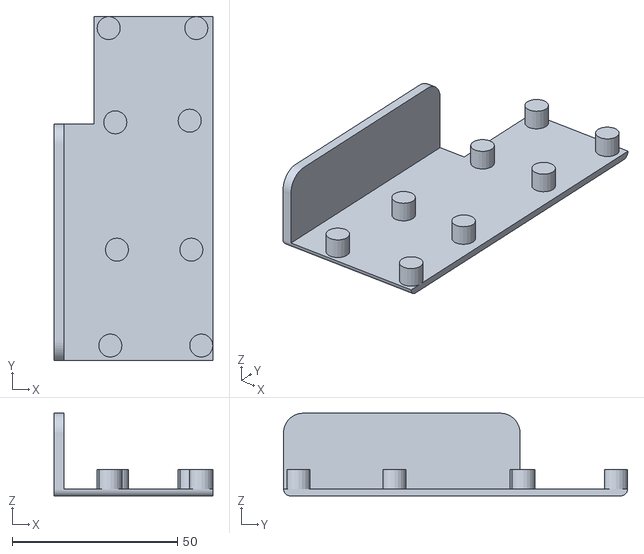
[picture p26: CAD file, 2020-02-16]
3D objects/Support for Alim Board/Radial-V-ALIM.BOARD-Support.stl
48.0 x 104.0 x 25.0

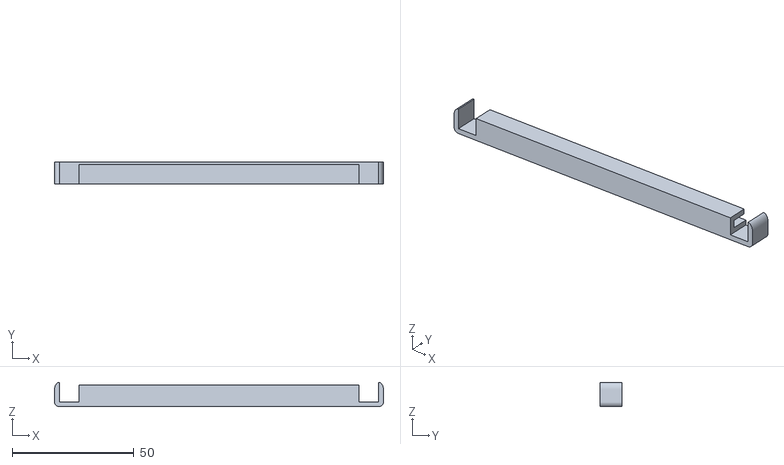
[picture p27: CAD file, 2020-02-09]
3D objects/Support for Arduino Boards/files/Radial-V Angle Long ARD2.stl
135.0 x 9.00 x 10.0

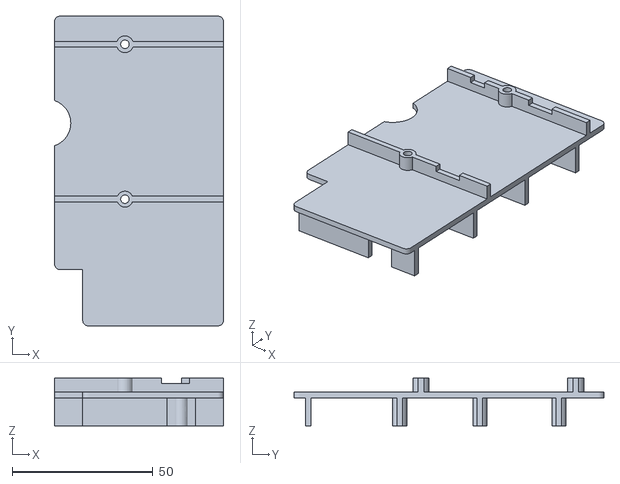
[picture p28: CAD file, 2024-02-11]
3D objects/Support for Audio Board/Support_Audio_Board.stl
60.0 x 110.0 x 17.0

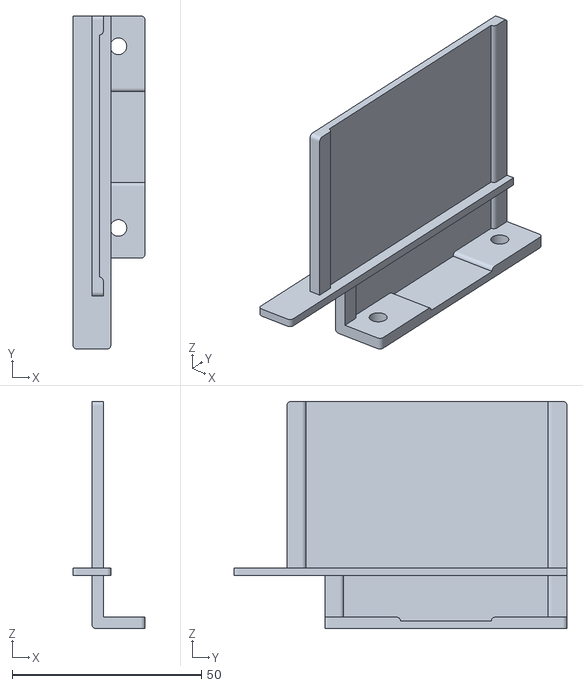
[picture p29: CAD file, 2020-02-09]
3D objects/Support for Extension Board/Support_pour_Extension_Board.stl
19.0 x 88.0 x 60.0

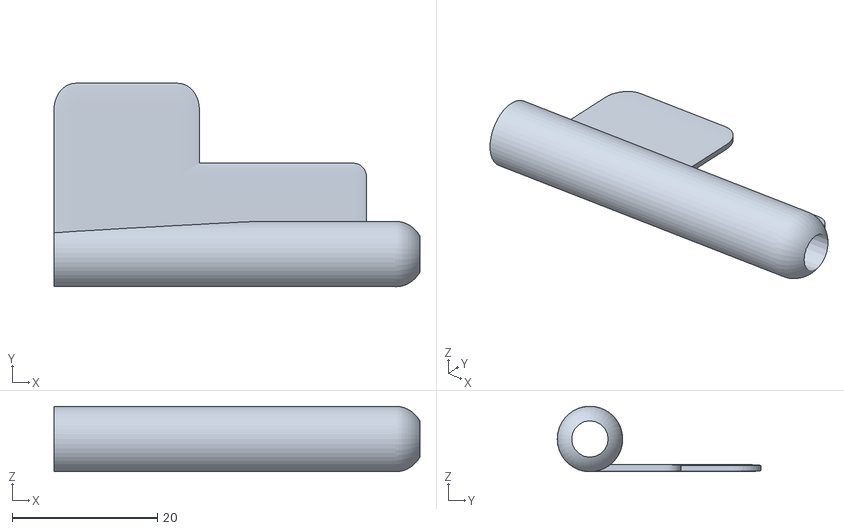
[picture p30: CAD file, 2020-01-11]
3D objects/Support for LED/Radial-V-Fixation-LED.stl
50.3 x 28.0 x 9.00

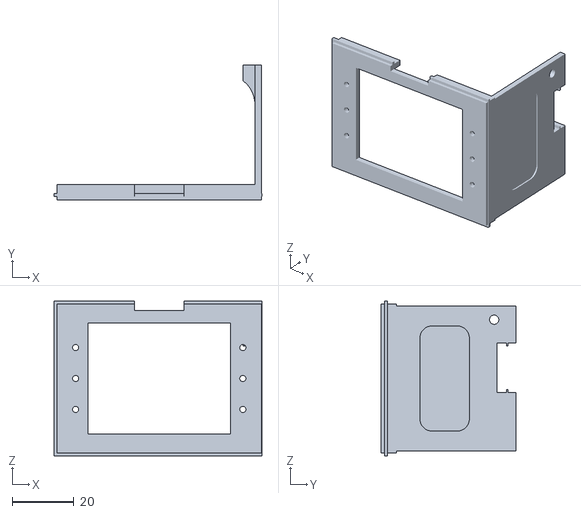
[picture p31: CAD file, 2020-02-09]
3D objects/Support for TFT Screen Board/Support for LCD.stl
67.2 x 43.5 x 50.0

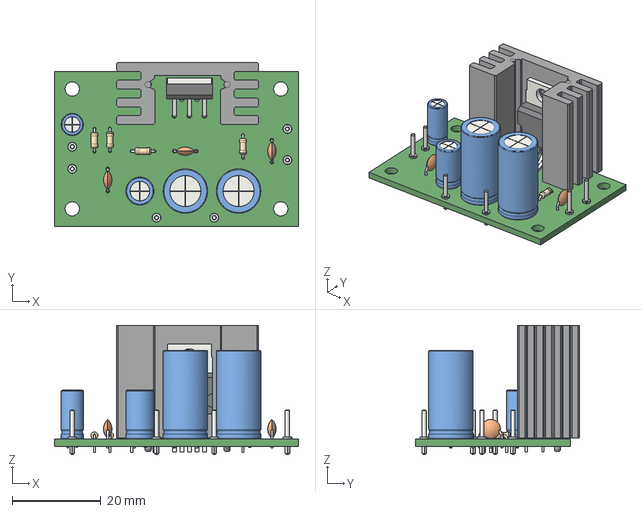
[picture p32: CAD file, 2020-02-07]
External Hardware/Carte Amplifier VM114/3D Model/Velleman_Amplifier_VM114.step
55.0 x 37.0 x 29.1 mm

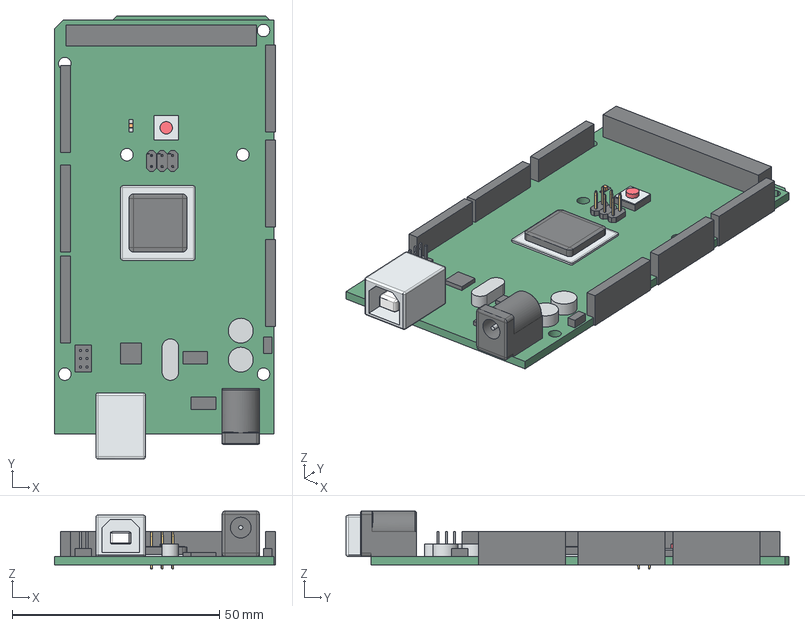
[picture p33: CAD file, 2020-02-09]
External Hardware/Carte Arduino Mega/3D Model/ArduinoMega2560.step
53.4 x 107.0 x 14.0 mm

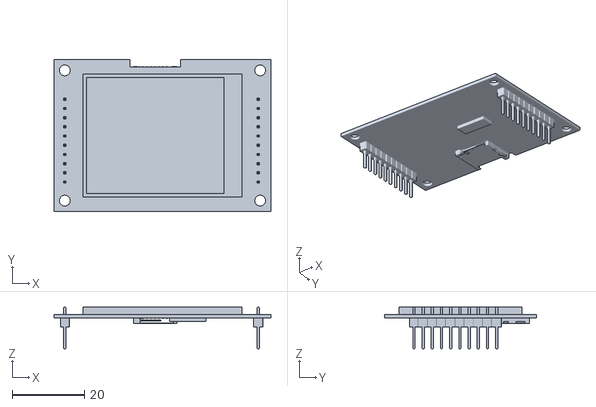
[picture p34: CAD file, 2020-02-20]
External Hardware/Carte ecran TFT/3D Model/Arduino_LCD_Board.stl
60.0 x 42.0 x 11.5

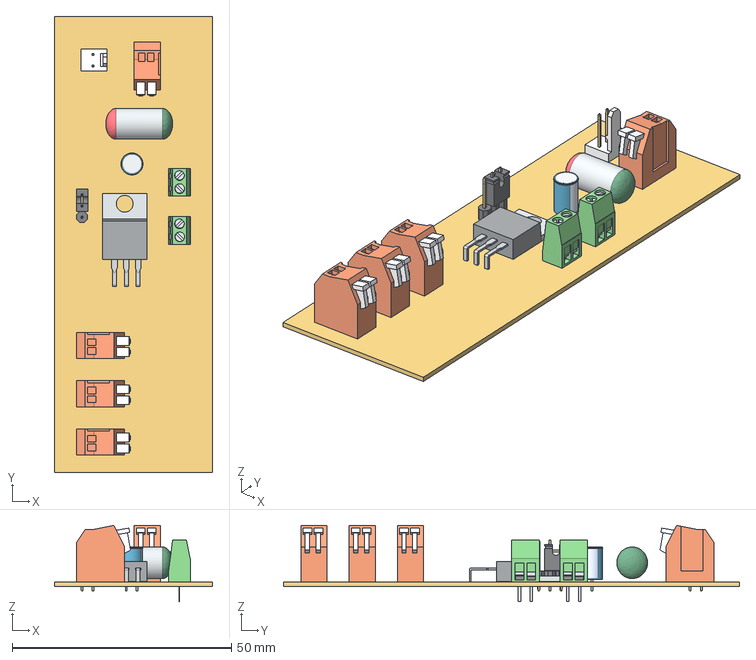
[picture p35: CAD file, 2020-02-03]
Hardware/Radial-V Alimentation board/3D Model/Radial-V-AlimBoard.step
36.0 x 104.0 x 17.4 mm

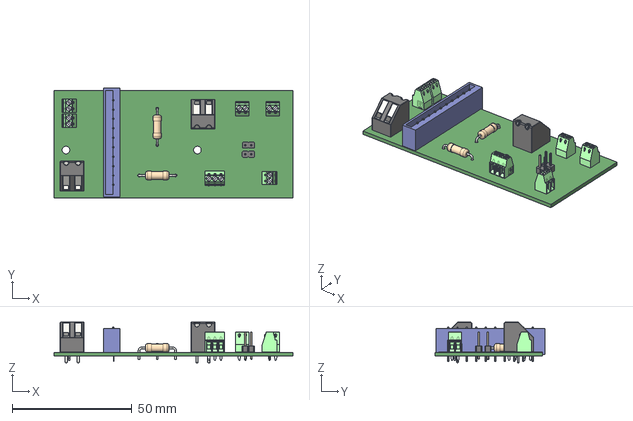
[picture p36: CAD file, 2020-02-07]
Hardware/Radial-V Audio board/3D Model/Radial-V-Audio-Board.step
100.0 x 45.9 x 17.1 mm

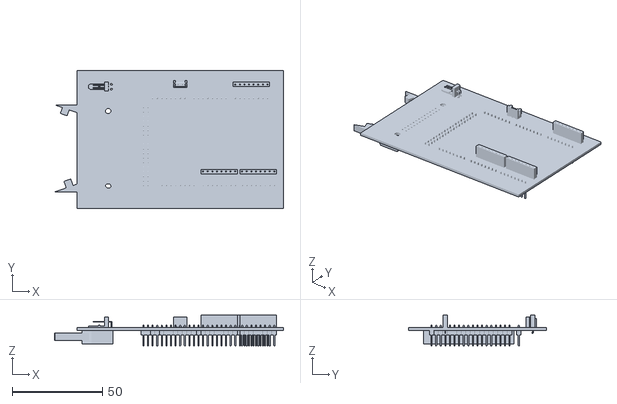
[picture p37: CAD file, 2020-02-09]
Hardware/Radial-V Bus/3D Model Bus Board v2/Radial-V-Bus-Board-v2.stl
126.7 x 76.2 x 17.1

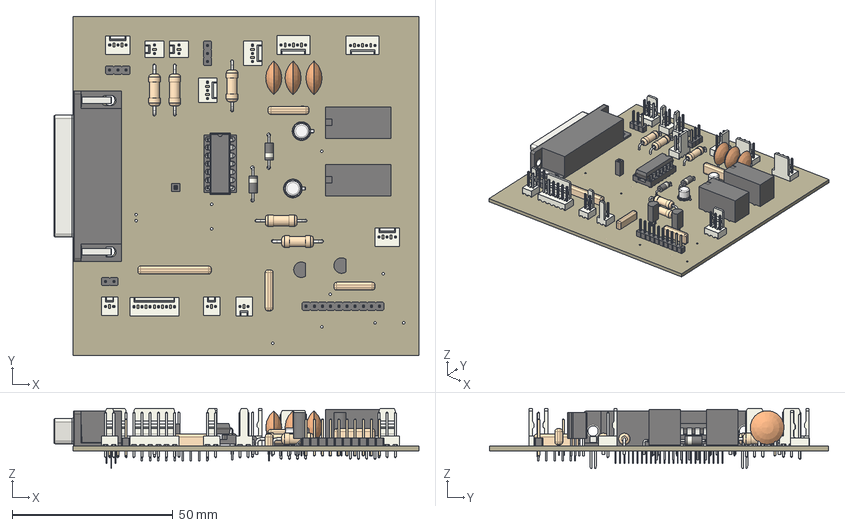
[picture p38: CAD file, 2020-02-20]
Hardware/Radial-V Extension board/3D Model/Radial-V Extension Board.step
113.4 x 105.4 x 18.7 mm
Board
PinHeader_1x03_P2.54mm_Vertical v1
PinHeader_1x10_P2.54mm_Vertical v1
R_Array_SIP9 v1
R_Array_SIP5 v1
R_Array_SIP5 v1 (1)
R_Array_SIP5 v1 (2)
PinHeader_1x03_P2.54mm_Vertical v1 (1)
PinHeader_1x02_P2.54mm_Vertical v1
Molex_KK-254_AE-6410-04A_1x04_P2.54mm_Vertical v1 x 2
Molex_KK-254_AE-6410-03A_1x03_P2.54mm_Vertical v1
TO-18, short leads 3mm v1 x 2
TO-92L v1 x 2
Molex_KK-254_AE-6410-03A_1x03_P2.54mm_Vertical v1 (1)
Molex_KK-254_AE-6410-03A_1x03_P2.54mm_Vertical v1 (2) x 2
Molex_KK-254_AE-6410-02A_1x02_P2.54mm_Vertical v1 x 3
Molex_KK-254_AE-6410-02A_1x02_P2.54mm_Vertical v1 (1) x 2
Relay_DPDT_Omron_G5V-2 v1 x 2
Molex_KK-254_AE-6410-06A_1x06_P2.54mm_Vertical v1
DIP-14_W7.62mm_Socket v1
DIP-14_W7.62mm v1
PinSocket_1x01_P2.54mm_Vertical v1
R_Axial_DIN0411_L9.9mm_D3.6mm_P15.24mm_Horizontal v1 x 5
D_A-405_P10.16mm_Horizontal v1 x 2
C_Disc_D10.5mm_W5.0mm_P5.00mm v1 x 3
DSUB-25_Female_Horizontal_P2.77x2.84mm_EdgePinOffset9.90mm_Housed_Mou ntingHolesOffset11.32mm v1

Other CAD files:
Hardware/Radial-V PreAmplifier Shunt/3D model/Radial-V PreAmplifier Shunt.step
3D objects/Boitiers/Boitier Adapter Capa.stl
3D objects/Support for Arduino Boards/files/Radial-V Angles (barre ARD1).stl
3D objects/Boitiers/Support for Amplifier.stl
3D objects/Boitiers/Couvercle Adaptateur Audio.stl
3D objects/Boitiers/Couvercle_pour_Bus_Board.stl
3D objects/Support for Arduino Boards/files/Radial-V Angles (D).stl
3D objects/Support for Arduino Boards/files/Radial-V Angles (G).stl
External Hardware/Carte Amplifier VM114/3D Model/Velleman_Amplifier_VM114.stl
Hardware/Radial-V Alimentation board/3D Model/Radial-V-AlimBoard.stl
Hardware/Radial-V Audio board/3D Model/Radial-V-Audio-Board.stl
Hardware/Radial-V Bus/3D Model Bus Board v1/Radial-V-Bus-Board-v1.stl

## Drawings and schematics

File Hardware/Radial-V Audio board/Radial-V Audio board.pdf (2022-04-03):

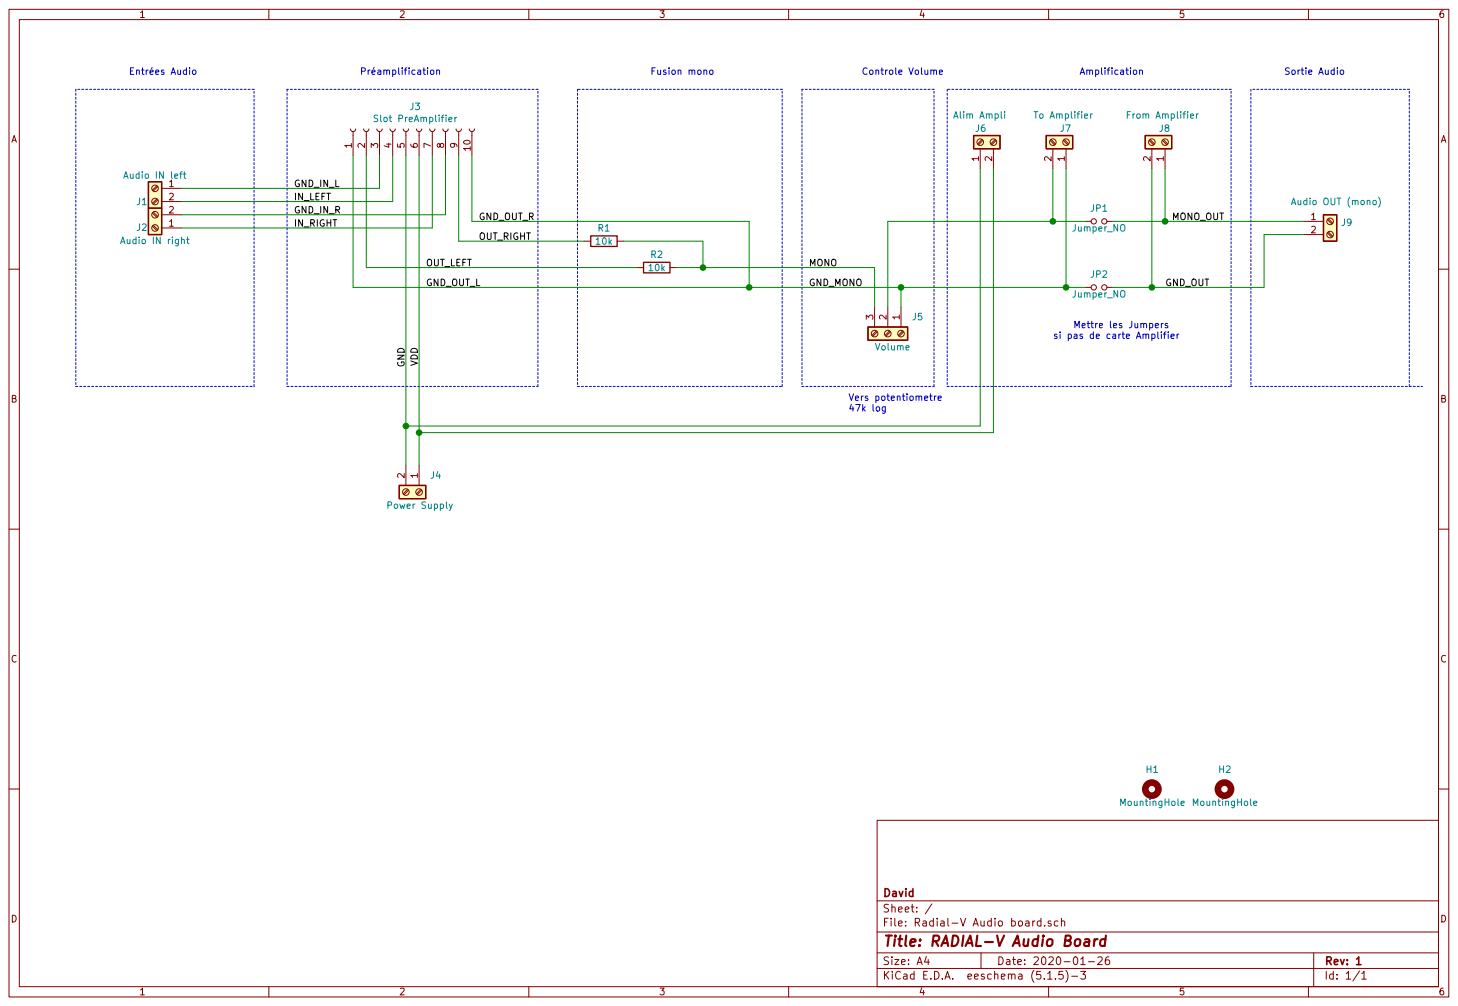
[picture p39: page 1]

si pas de carte Amplifier Entrées Audio

File: Radial-V Audio board.sch Sheet: / David

Id: 1/1 Title: RADIAL-V Audio Board

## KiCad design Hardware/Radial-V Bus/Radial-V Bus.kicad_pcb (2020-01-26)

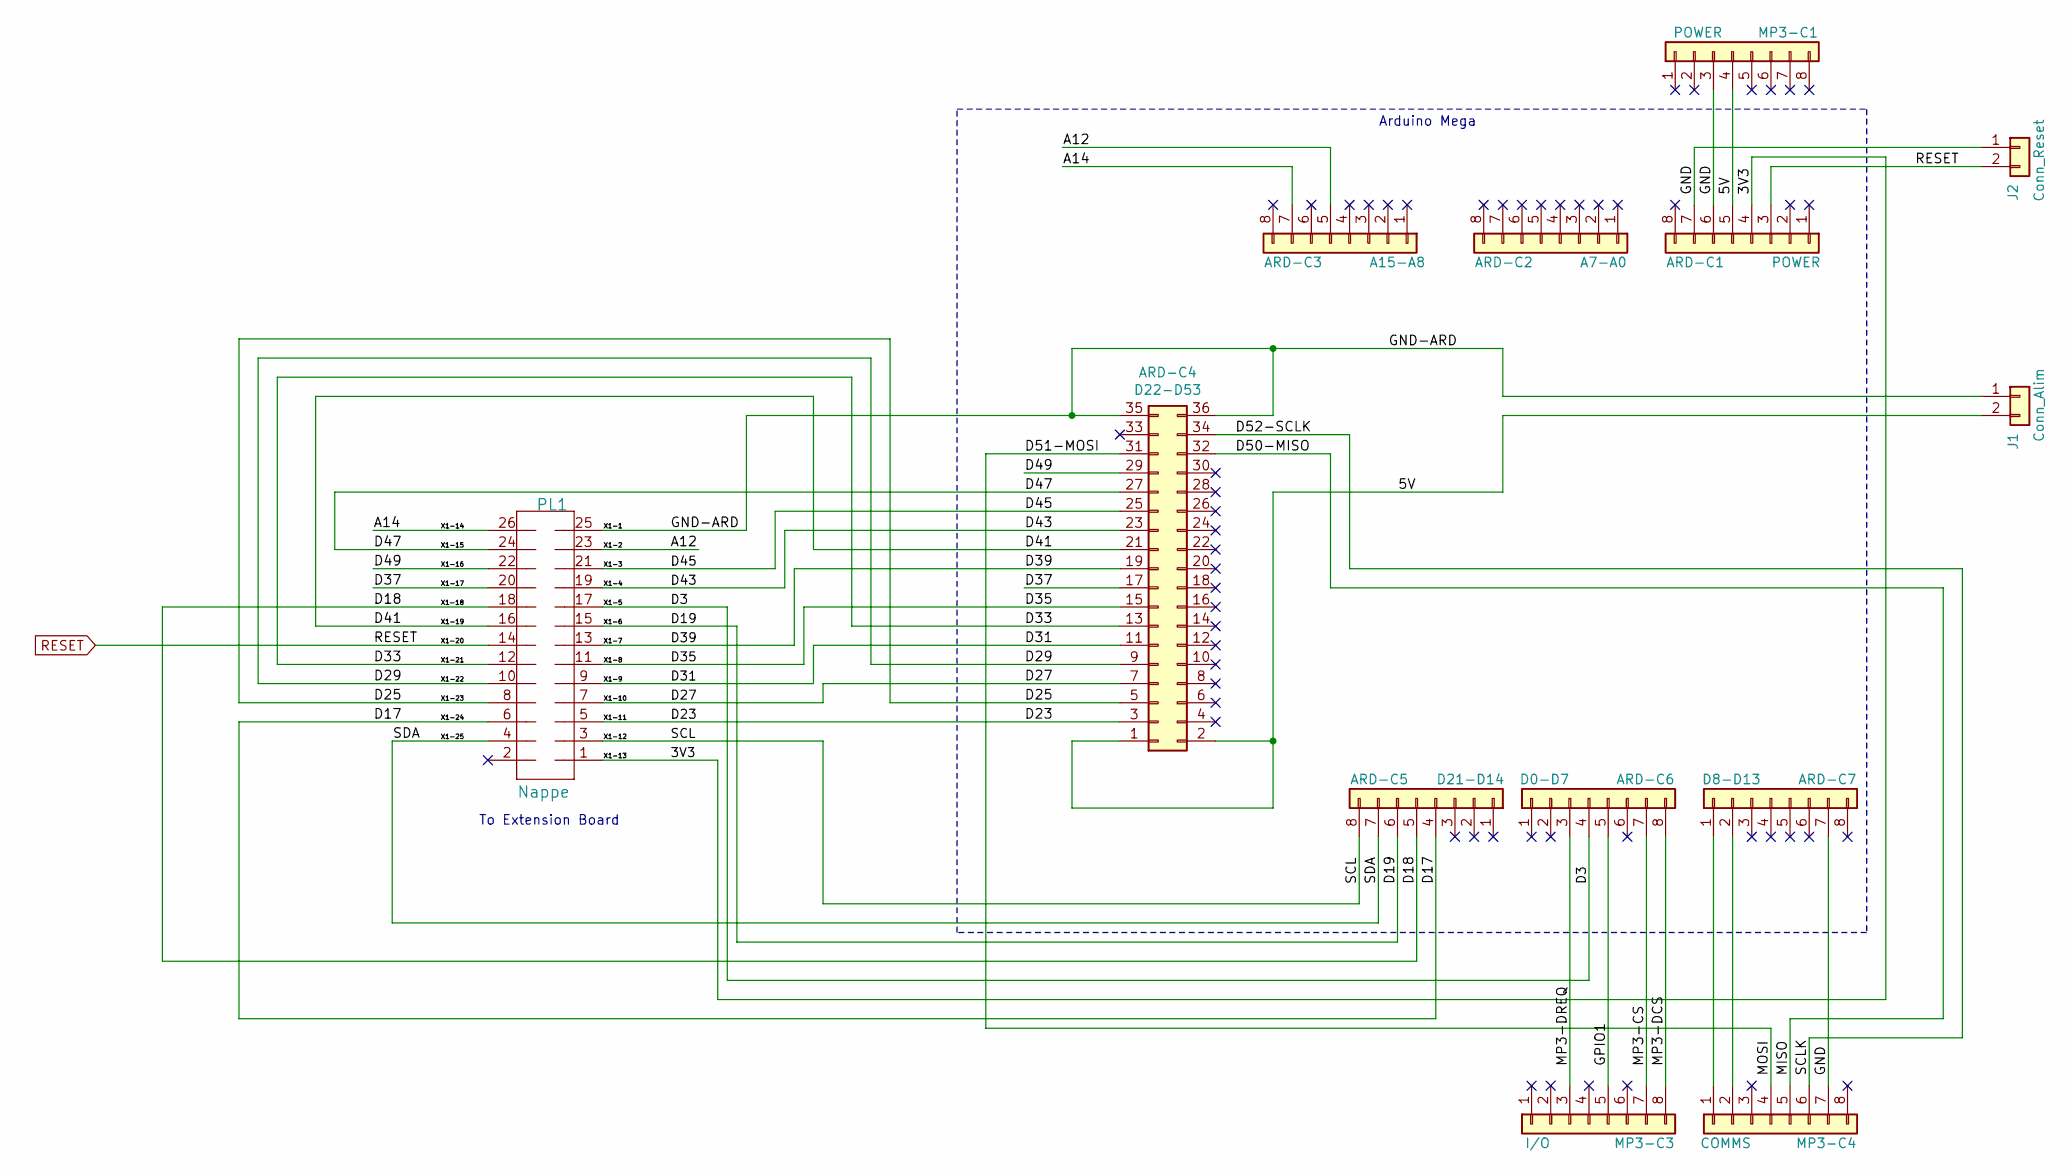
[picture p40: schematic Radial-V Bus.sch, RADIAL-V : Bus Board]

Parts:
ARD-C1: POWER; PinHeader_1x08_P2.54mm_Vertical
ARD-C2: A7-A0; PinHeader_1x08_P2.54mm_Vertical
ARD-C3: A15-A8; PinHeader_1x08_P2.54mm_Vertical
ARD-C4: D22-D53; PinHeader_2x18_P2.54mm_Vertical
ARD-C5: D21-D14; PinHeader_1x08_P2.54mm_Vertical
ARD-C6: D0-D7; PinHeader_1x08_P2.54mm_Vertical
ARD-C7: D8-D13; PinHeader_1x08_P2.54mm_Vertical
J1: Conn_Alim; Molex_KK-254_AE-6410-02A_1x02_P2.54mm_Horizontal
J2: Conn_Reset; JST_EH_B2B-EH-A_1x02_P2.50mm_Vertical
MP3-C1: POWER; PinSocket_1x08_P2.54mm_Vertical
MP3-C3: I/O; PinSocket_1x08_P2.54mm_Vertical
MP3-C4: COMMS; PinSocket_1x08_P2.54mm_Vertical
PL1: Nappe; HE10-26P

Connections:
/3V3: ARD-C1.4, PL1.1
/5V: ARD-C1.5, ARD-C4.1, ARD-C4.2, J1.2, MP3-C1.4
/A12: ARD-C3.5, PL1.23
/A14: ARD-C3.7, PL1.26
/D3: ARD-C6.4, PL1.17
/D17: ARD-C5.4, PL1.6
/D18: ARD-C5.5, PL1.18
/D19: ARD-C5.6, PL1.15
/D23: ARD-C4.3, PL1.5
/D25: ARD-C4.5, PL1.8
/D27: ARD-C4.7, PL1.7
/D29: ARD-C4.9, PL1.10
/D31: ARD-C4.11, PL1.9
/D33: ARD-C4.13, PL1.12
/D35: ARD-C4.15, PL1.11
/D37: ARD-C4.17, PL1.20
/D39: ARD-C4.19, PL1.13
/D41: ARD-C4.21, PL1.16
/D43: ARD-C4.23, PL1.19
/D45: ARD-C4.25, PL1.21
/D47: ARD-C4.27, PL1.24
/D49: ARD-C4.29, PL1.22
/D50-MISO: ARD-C4.32, MP3-C4.5
/D51-MOSI: ARD-C4.31, MP3-C4.4
/D52-SCLK: ARD-C4.34, MP3-C4.6
/GND: ARD-C1.6, ARD-C1.7, ARD-C7.7, J2.1, MP3-C1.3, MP3-C4.7
/GND-ARD: ARD-C4.35, ARD-C4.36, J1.1, PL1.25
/GPIO1: ARD-C6.5, MP3-C3.5
/MP3-CS: ARD-C6.7, MP3-C3.7
/MP3-DCS: ARD-C6.8, MP3-C3.8
/MP3-DREQ: ARD-C6.3, MP3-C3.3
/SCL: ARD-C5.8, PL1.3
/SDA: ARD-C5.7, PL1.4
unnamed: ARD-C7.1, MP3-C4.1
unnamed: ARD-C7.2, MP3-C4.2
RESET: ARD-C1.3, J2.2, PL1.14

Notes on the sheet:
To Extension Board
Arduino Mega

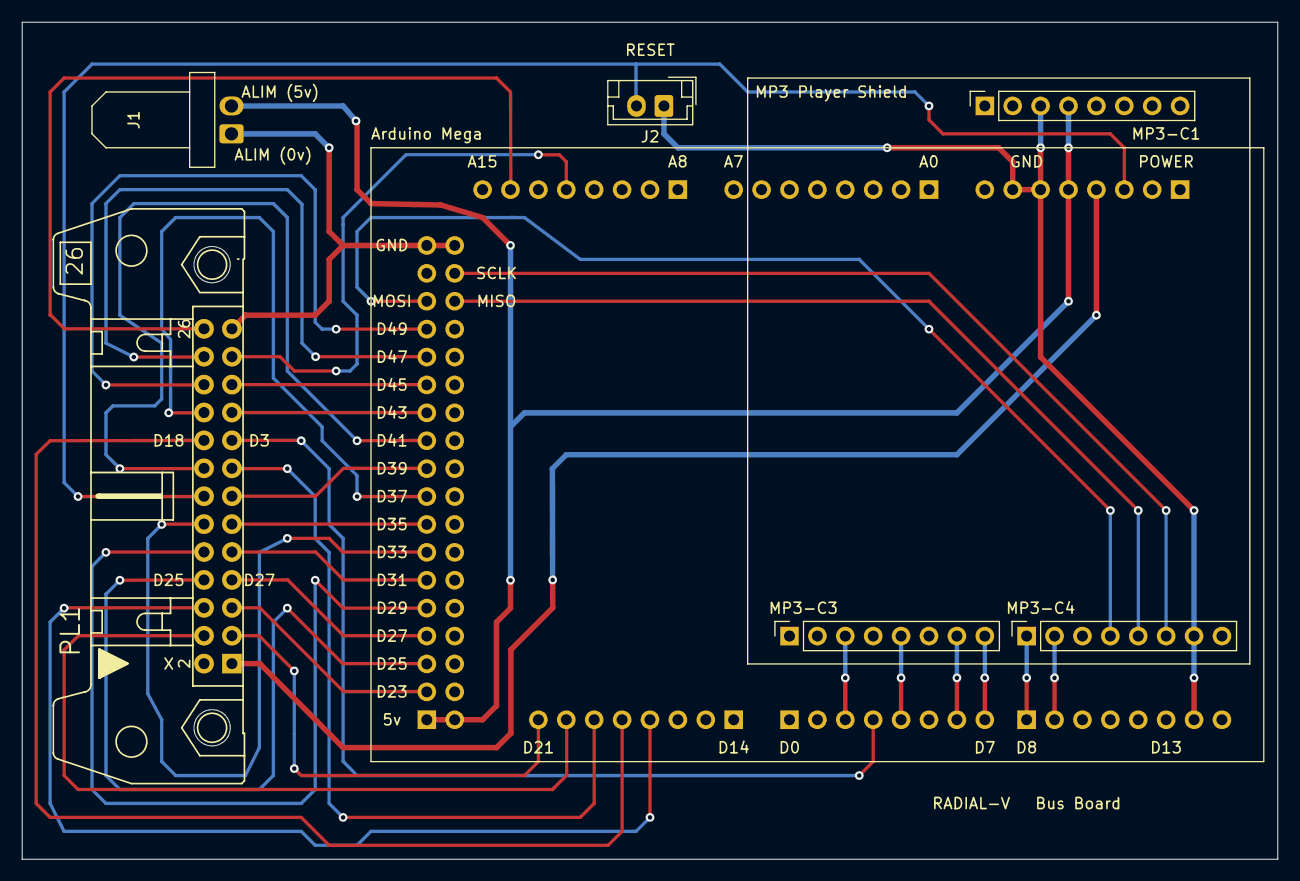
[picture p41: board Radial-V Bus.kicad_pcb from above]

Board: 2 copper layers, 114.3 x 76.2 mm, 13 parts (0 on the bottom side), 36 nets.

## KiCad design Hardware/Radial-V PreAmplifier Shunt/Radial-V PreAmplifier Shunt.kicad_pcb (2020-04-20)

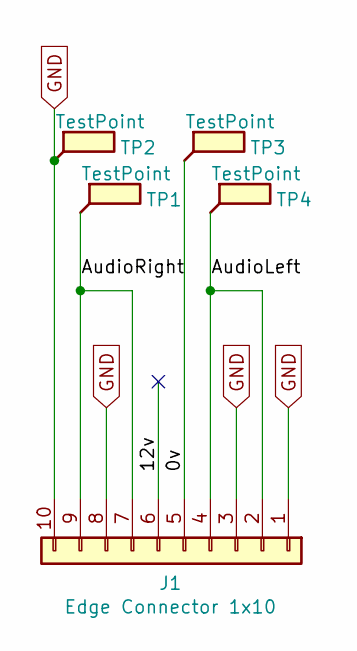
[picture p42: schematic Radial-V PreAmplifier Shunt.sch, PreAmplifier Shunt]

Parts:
J1: Edge Connector 1x10; PCB_Edge_1x10
TP1, TP2, TP3, TP4: TestPoint; TestPoint_THTPad_D2.5mm_Drill1.2mm

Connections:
/0v: J1.5, TP3.1
/12v: J1.6
/AudioLeft: J1.2, J1.4, TP4.1
/AudioRight: J1.7, J1.9, TP1.1
GND: J1.1, J1.3, J1.8, J1.10, TP2.1

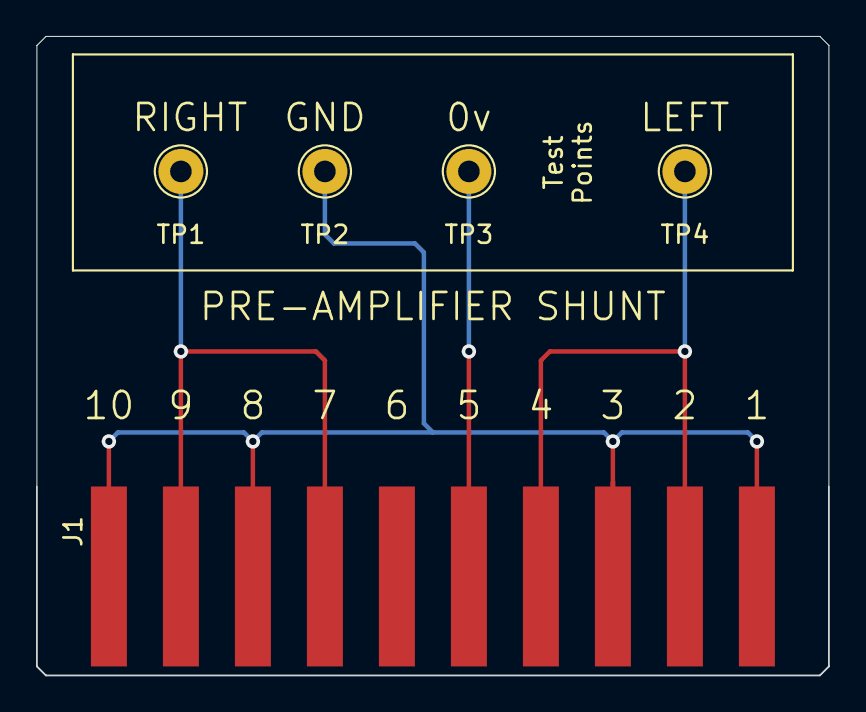
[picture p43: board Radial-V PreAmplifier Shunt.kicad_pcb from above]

Board: 2 copper layers, 44.0 x 35.5 mm, 5 parts (0 on the bottom side), 4 nets.

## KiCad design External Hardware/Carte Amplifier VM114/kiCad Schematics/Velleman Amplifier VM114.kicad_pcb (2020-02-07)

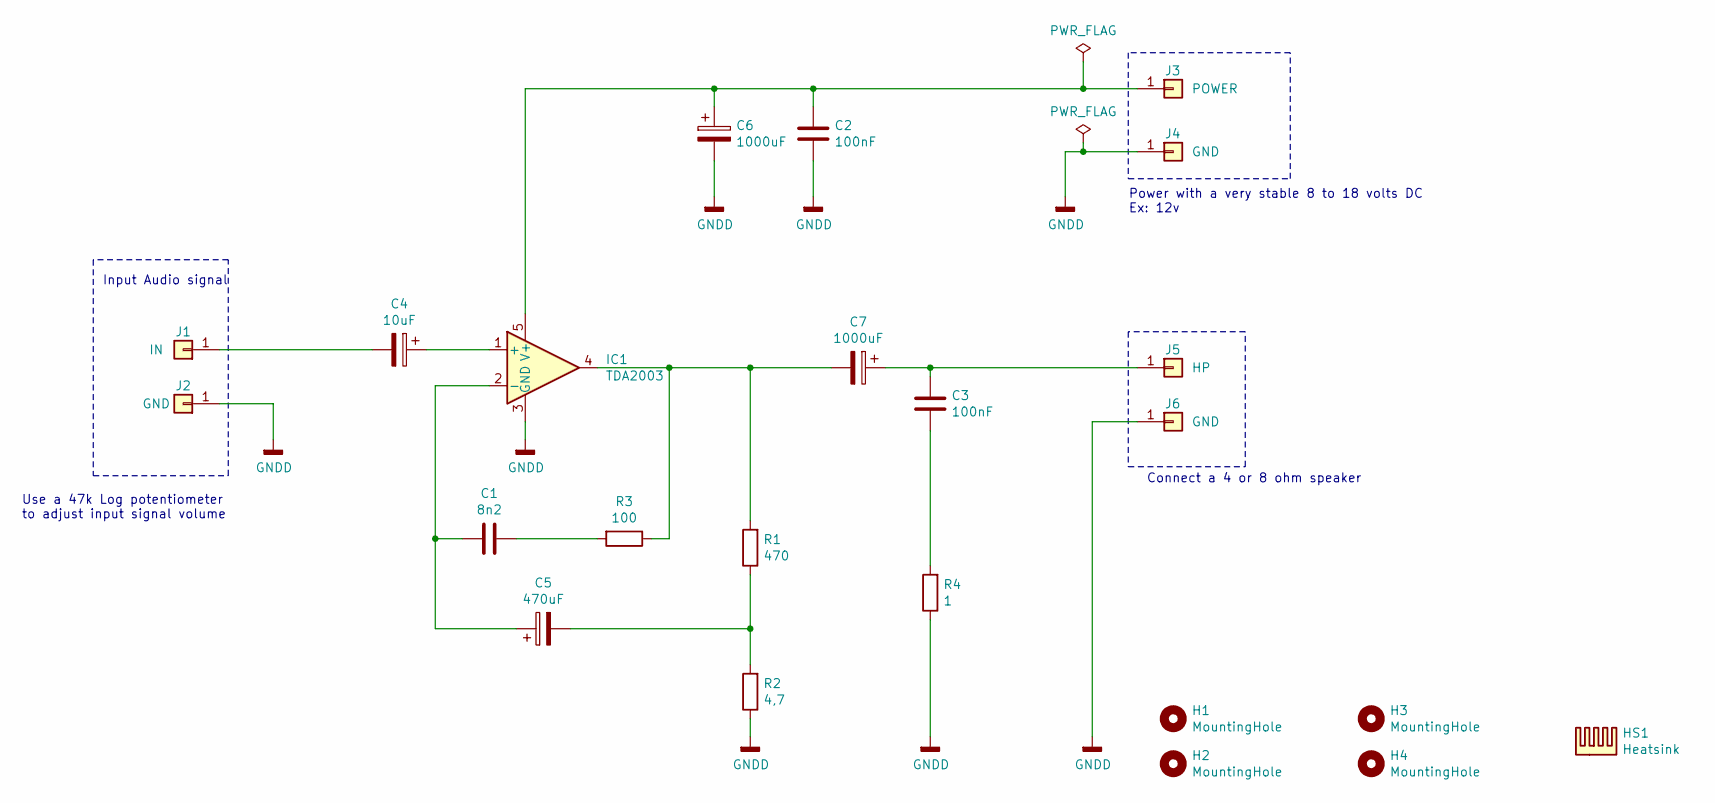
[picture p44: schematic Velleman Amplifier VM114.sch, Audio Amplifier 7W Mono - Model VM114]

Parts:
C1: 8n2; C_Disc_D4.3mm_W1.9mm_P5.00mm
C2, C3: 100nF; C_Disc_D4.3mm_W1.9mm_P5.00mm
C4: 10uF; C_Radial_D5.0mm_H11.0mm_P2.00mm
C5: 470uF; C_Radial_D6.3mm_H11.0mm_P2.50mm
C6, C7: 1000uF; C_Radial_D10.0mm_H20.0mm_P5.00mm
H1, H2, H3, H4: MountingHole; MountingHole_3.2mm_M3_DIN965_Pad
HS1: Heatsink; Heatsink_Stonecold_HS-132_32x14mm_2xFixation1.5mm
IC1: TDA2003; TO-220-5_P3.4x3.7mm_StaggerOdd_Lead3.8mm_Vertical
J1: IN; Pin_D1.0mm_L10.0mm
J2, J4, J6: GND; Pin_D1.0mm_L10.0mm
J3: POWER; Pin_D1.0mm_L10.0mm
J5: HP; Pin_D1.0mm_L10.0mm
R1: 470; R_Axial_DIN0204_L3.6mm_D1.6mm_P5.08mm_Horizontal
R2: 4,7; R_Axial_DIN0204_L3.6mm_D1.6mm_P5.08mm_Horizontal
R3: 100; R_Axial_DIN0204_L3.6mm_D1.6mm_P5.08mm_Horizontal
R4: 1; R_Axial_DIN0204_L3.6mm_D1.6mm_P5.08mm_Horizontal

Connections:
GNDD: C2.2, C6.2, IC1.3 (GND), J2.1, J4.1, J6.1, R2.1, R4.1
unnamed: C1.1, R3.2
unnamed: C1.2, C5.1, IC1.2 (-)
unnamed: C2.1, C6.1, IC1.5 (V+), J3.1
unnamed: C3.1, R4.2
unnamed: C3.2, C7.1, J5.1
unnamed: C4.1, IC1.1 (+)
unnamed: C4.2, J1.1
unnamed: C5.2, R1.1, R2.2
unnamed: C7.2, IC1.4, R1.2, R3.1

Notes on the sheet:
Input Audio signal
Connect a 4 or 8 ohm speaker
Power with a very stable 8 to 18 volts DC Ex: 12v
Use a 47k Log potentiometer to adjust input signal volume

Board: 2 copper layers, 23 parts (0 on the bottom side), 10 nets, no tracks yet.

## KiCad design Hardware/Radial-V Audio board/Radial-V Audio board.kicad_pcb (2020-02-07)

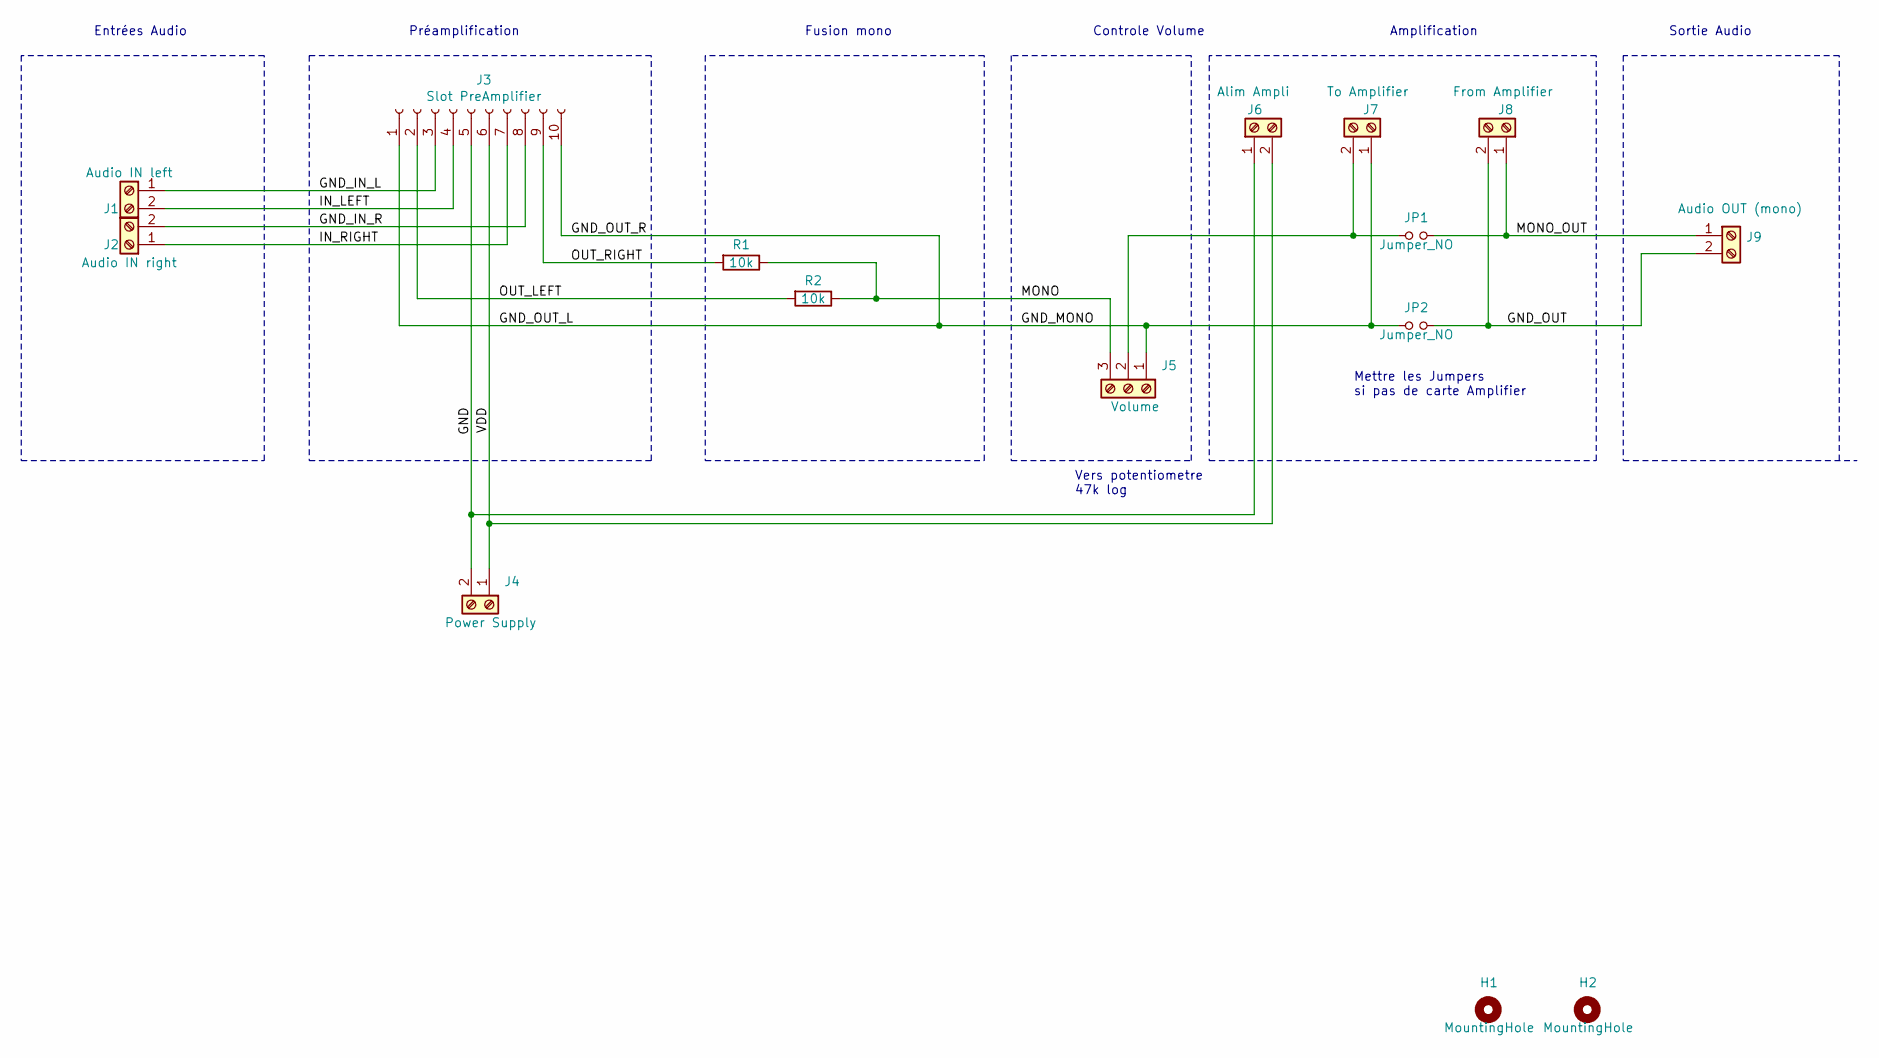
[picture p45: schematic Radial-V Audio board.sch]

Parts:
H1, H2: MountingHole; MountingHole_3.2mm_M3
J1: Audio IN left; Bloc_de_jonction_CI-MPT_2.54mm_01x02
J2: Audio IN right; Bloc_de_jonction_CI-MPT_2.54mm_01x02
J3: Slot PreAmplifier; Edge_Connector_10P_1x10_P3.96mm_Vertical
J4: Power Supply; Altech_AK300_1x02_P5.00mm_45-Degree
J5: Volume; Bloc_de_jonction_CI-MPT_2.54mm_01x03
J6: Alim Ampli; Altech_AK300_1x02_P5.00mm_45-Degree
J7: To Amplifier; Bloc_de_jonction_CI-MPT_2.54mm_01x02
J8: From Amplifier; Bloc_de_jonction_CI-MPT_2.54mm_01x02
J9: Audio OUT (mono); Bloc_de_jonction_CI-MPT_2.54mm_01x02
JP1, JP2: Jumper_NO; PinHeader_1x02_P2.54mm_Vertical
R1, R2: 10k; R_Axial_DIN0411_L9.9mm_D3.6mm_P15.24mm_Horizontal

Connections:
/GND: J3.5, J4.2, J6.1
/GND_IN_L: J1.1, J3.3
/GND_IN_R: J2.2, J3.8
/GND_MONO: J3.1, J3.10, J5.1, J7.1, JP2.1
/GND_OUT: J8.2, J9.2, JP2.2
/IN_LEFT: J1.2, J3.4
/IN_RIGHT: J2.1, J3.7
/MONO: J5.3, R1.1, R2.1
/MONO_OUT: J8.1, J9.1, JP1.2
/OUT_LEFT: J3.2, R2.2
/OUT_RIGHT: J3.9, R1.2
/VDD: J3.6, J4.1, J6.2
unnamed: J5.2, J7.2, JP1.1

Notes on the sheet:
Entrées Audio
Préamplification
Fusion mono
Controle Volume
Amplification
Sortie Audio
Vers potentiometre 47k log
Mettre les Jumpers si pas de carte Amplifier

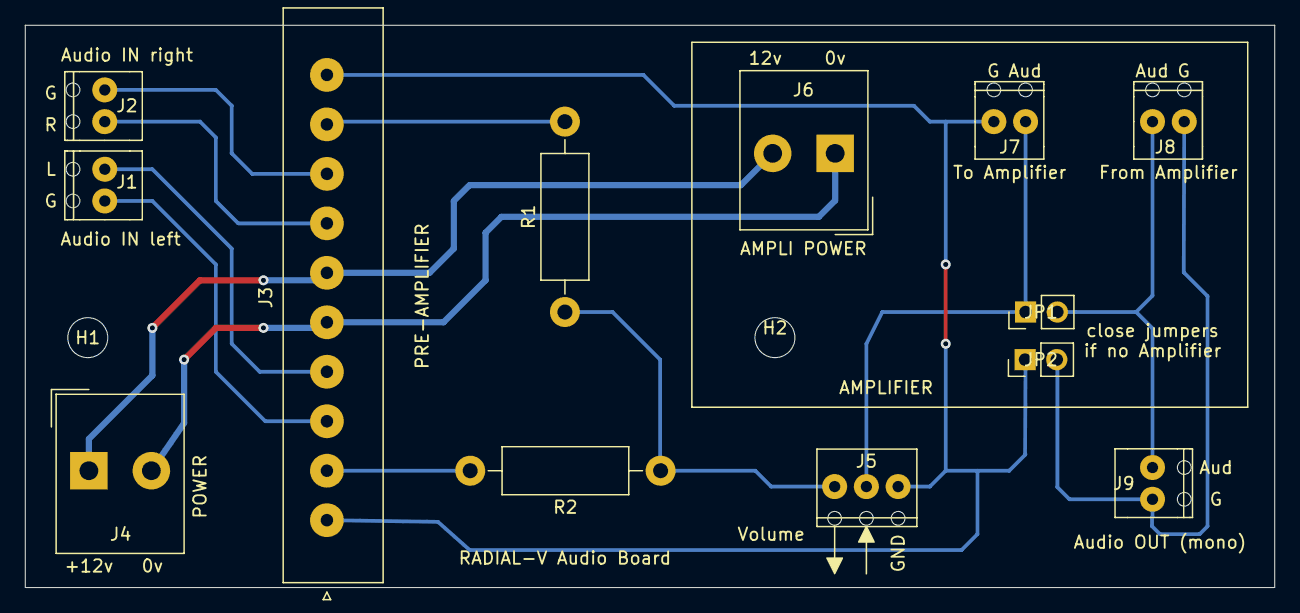
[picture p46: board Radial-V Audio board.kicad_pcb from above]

Board: 2 copper layers, 100.0 x 45.0 mm, 15 parts (0 on the bottom side), 13 nets.

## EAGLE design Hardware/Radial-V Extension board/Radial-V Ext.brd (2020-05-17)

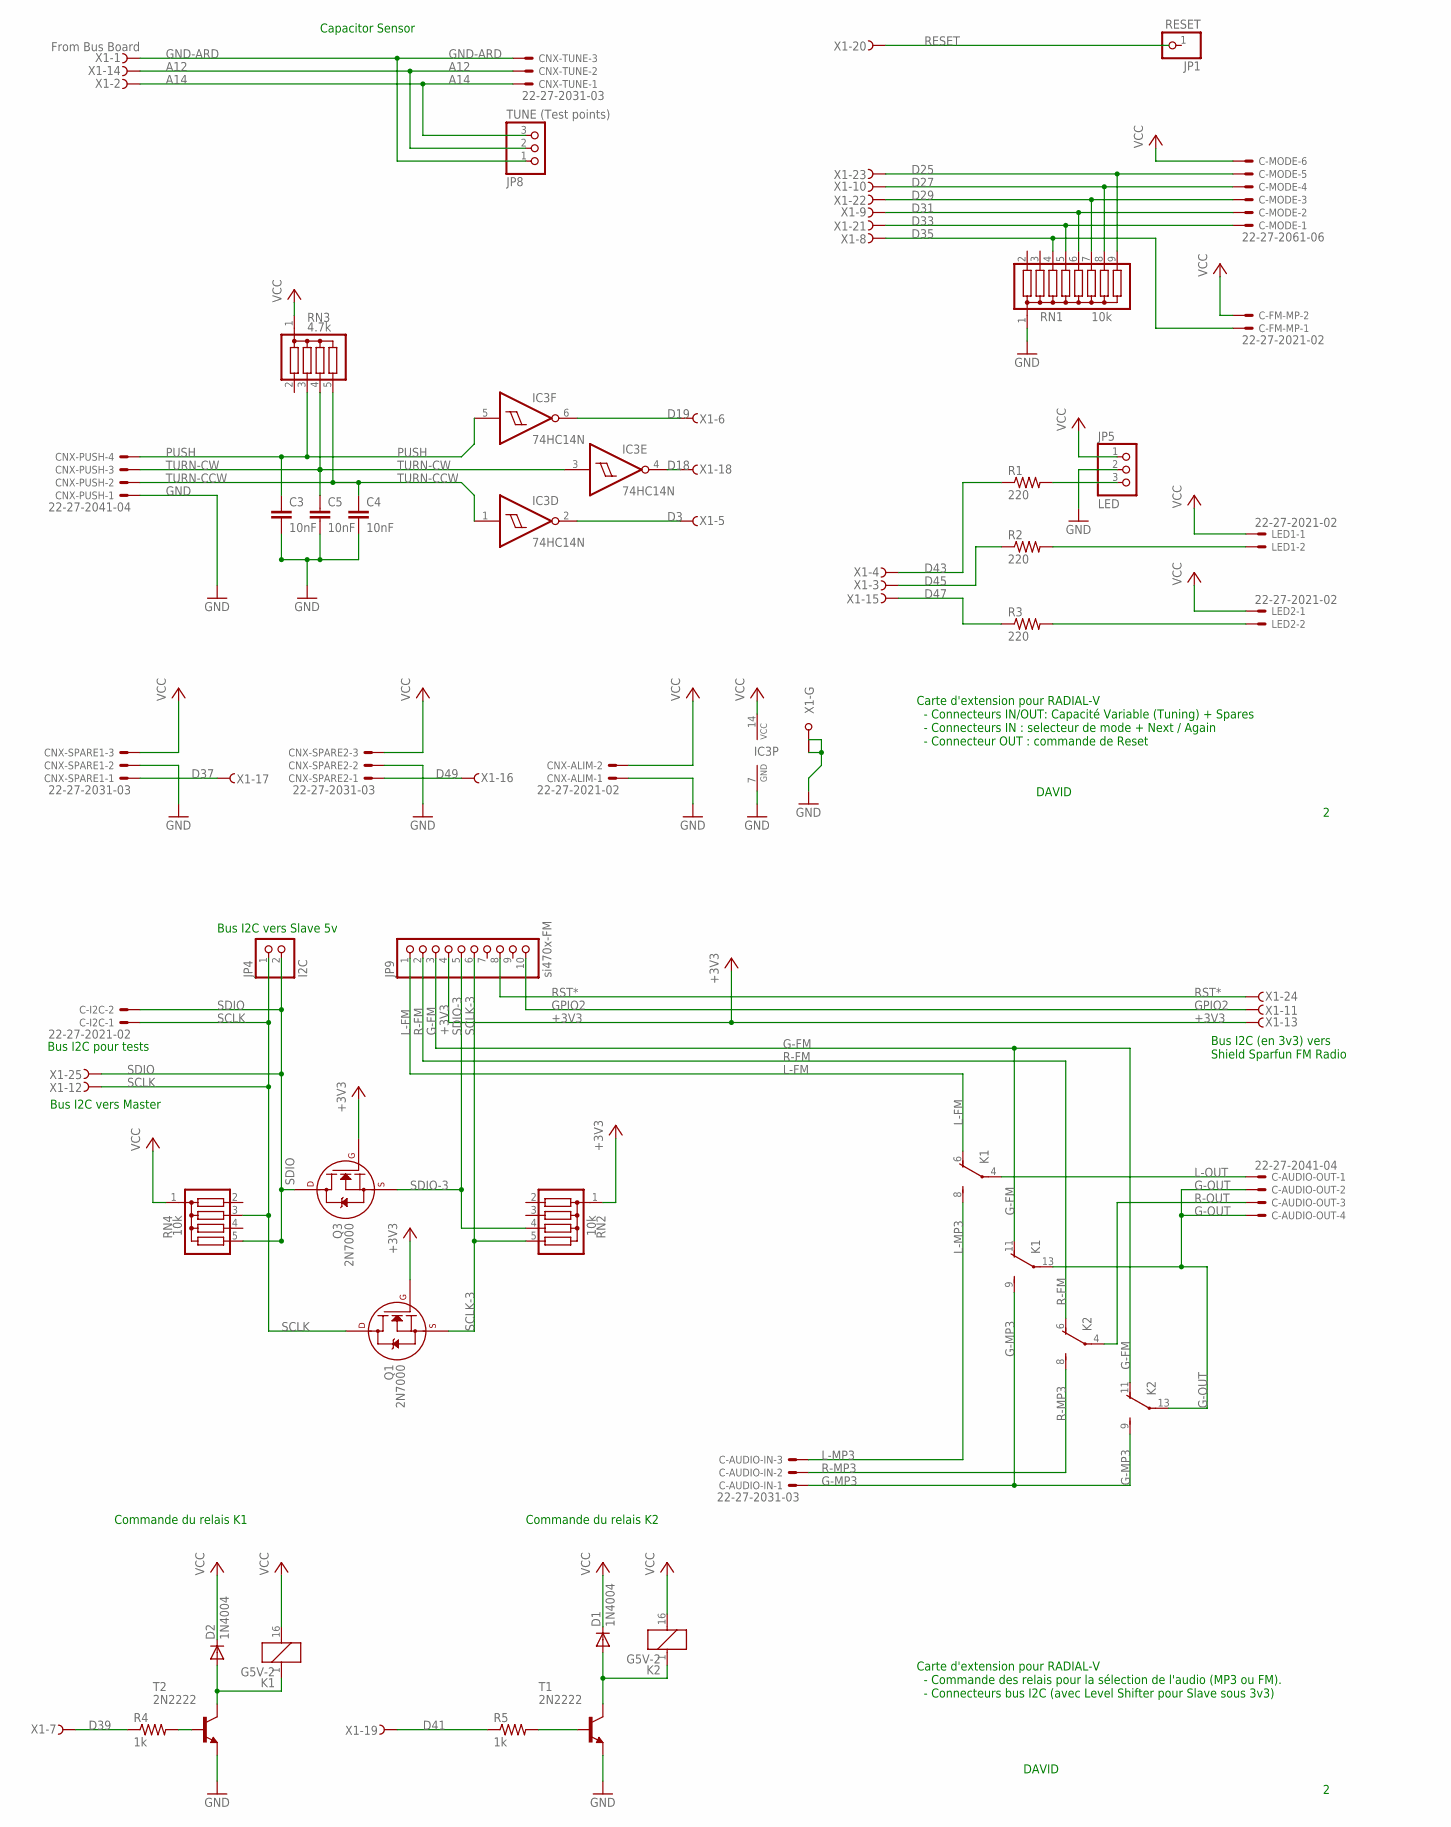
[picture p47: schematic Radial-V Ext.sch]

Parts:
C3, C4, C5: 10nF; C050-050X075
C-AUDIO-IN: 22-27-2031-03; 6410-03
C-AUDIO-OUT: 22-27-2041-04; 6410-04
C-FM-MP: 22-27-2021-02; 6410-02
C-I2C: 22-27-2021-02; 6410-02
C-MODE: 22-27-2061-06; 6410-06
CNX-ALIM: 22-27-2021-02; 6410-02
CNX-PUSH: 22-27-2041-04; 6410-04
CNX-SPARE1, CNX-SPARE2: 22-27-2031-03; 6410-03
CNX-TUNE: 22-27-2031-03; 6410-03
D1, D2: 1N4004; DO41-10
IC3: 74HC14N; DIL14
JP1: RESET; 1X01
JP4: I2C; 1X02
JP5: LED; 1X03
JP8: TUNE (Test points); 1X03
JP9: si470x-FM; 1X10
K1, K2: G5V-2
LED1, LED2: 22-27-2021-02; 6410-02
Q1, Q3: 2N7000; TO-92
R1, R2, R3: 220; 0411/15
R4, R5: 1k; 0411/15
RN1: 10k; SIL9
RN2, RN4: 10k; SIL5
RN3: 4.7k; SIL5
T1, T2: 2N2222; TO18
X1: From Bus Board; F25HP

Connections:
+3V3: JP9.4, Q1.2 (G), Q3.2 (G), RN2.1, X1.13 (F)
A12: CNX-TUNE.2, JP8.2, X1.14 (F)
A14: CNX-TUNE.1, JP8.3, X1.2 (F)
D3: IC3.2 (O), X1.5 (F)
D18: IC3.4 (O), X1.18 (F)
D19: IC3.6 (O), X1.6 (F)
D25: C-MODE.5, RN1.9, X1.23 (F)
D27: C-MODE.4, RN1.8, X1.10 (F)
D29: C-MODE.3, RN1.7, X1.22 (F)
D31: C-MODE.2, RN1.6, X1.9 (F)
D33: C-MODE.1, RN1.5, X1.21 (F)
D35: C-FM-MP.1, RN1.4, X1.8 (F)
D37: CNX-SPARE1.1, X1.17 (F)
D39: R4.1, X1.7 (F)
D41: R5.1, X1.19 (F)
D43: R1.1, X1.4 (F)
D45: R2.1, X1.3 (F)
D47: R3.1, X1.15 (F)
D49: CNX-SPARE2.1, X1.16 (F)
G-FM: JP9.3, K1.11 (O), K2.11 (O)
G-MP3: C-AUDIO-IN.1, K1.9 (S), K2.9 (S)
G-OUT: C-AUDIO-OUT.2, C-AUDIO-OUT.4, K1.13, K2.13
GND: C3.2, C4.2, C5.2, CNX-ALIM.1, CNX-PUSH.1, CNX-SPARE1.2, CNX-SPARE2.2, IC3.7 (GND), JP5.2, RN1.1, T1.1 (E), T2.1 (E), X1.G1, X1.G2
GND-ARD: CNX-TUNE.3, JP8.1, X1.1 (F)
GPIO2: JP9.10, X1.11 (F)
L-FM: JP9.1, K1.6 (O)
L-MP3: C-AUDIO-IN.3, K1.8 (S)
L-OUT: C-AUDIO-OUT.1, K1.4
unnamed: D2.A, K1.1, T2.3 (C)
unnamed: LED1.2, R2.2
unnamed: D1.A, K2.1, T1.3 (C)
unnamed: JP5.3, R1.2
unnamed: LED2.2, R3.2
unnamed: R4.2, T2.2 (B)
unnamed: R5.2, T1.2 (B)
PUSH: C3.1, CNX-PUSH.4, IC3.5 (I), RN3.3
R-FM: JP9.2, K2.6 (O)
R-MP3: C-AUDIO-IN.2, K2.8 (S)
R-OUT: C-AUDIO-OUT.3, K2.4
RESET: X1.20 (F)
RST*: JP9.8, X1.24 (F)
SCLK: C-I2C.1, JP4.1, Q1.3 (D), RN4.3, X1.12 (F)
SCLK-3: JP9.6, Q1.1 (S), RN2.5
SDIO: C-I2C.2, JP4.2, Q3.3 (D), RN4.5, X1.25 (F)
SDIO-3: JP9.5, Q3.1 (S), RN2.4
TURN-CCW: C4.1, CNX-PUSH.2, IC3.1 (I), RN3.5
TURN-CW: C5.1, CNX-PUSH.3, IC3.3 (I), RN3.4
VCC: C-FM-MP.2, C-MODE.6, CNX-ALIM.2, CNX-SPARE1.3, CNX-SPARE2.3, D1.C, D2.C, IC3.14 (VCC), JP5.1, K1.16 (2), K2.16 (2), LED1.1, LED2.1, RN3.1, RN4.1

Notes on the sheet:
Capacitor Sensor
DAVID
Carte d'extension pour RADIAL-V - Connecteurs IN/OUT: Capacité Variable (Tuning) + Spares - Connecteurs IN : selecteur de mode + Next / Again - Connecteur OUT : commande de Reset
Commande du relais K1
Commande du relais K2
Bus I2C vers Slave 5v
Bus I2C (en 3v3) vers Shield Sparfun FM Radio
Bus I2C vers Master
Bus I2C pour tests
Carte d'extension pour RADIAL-V - Commande des relais pour la sélection de l'audio (MP3 ou FM). - Connecteurs bus I2C (avec Level Shifter pour Slave sous 3v3)

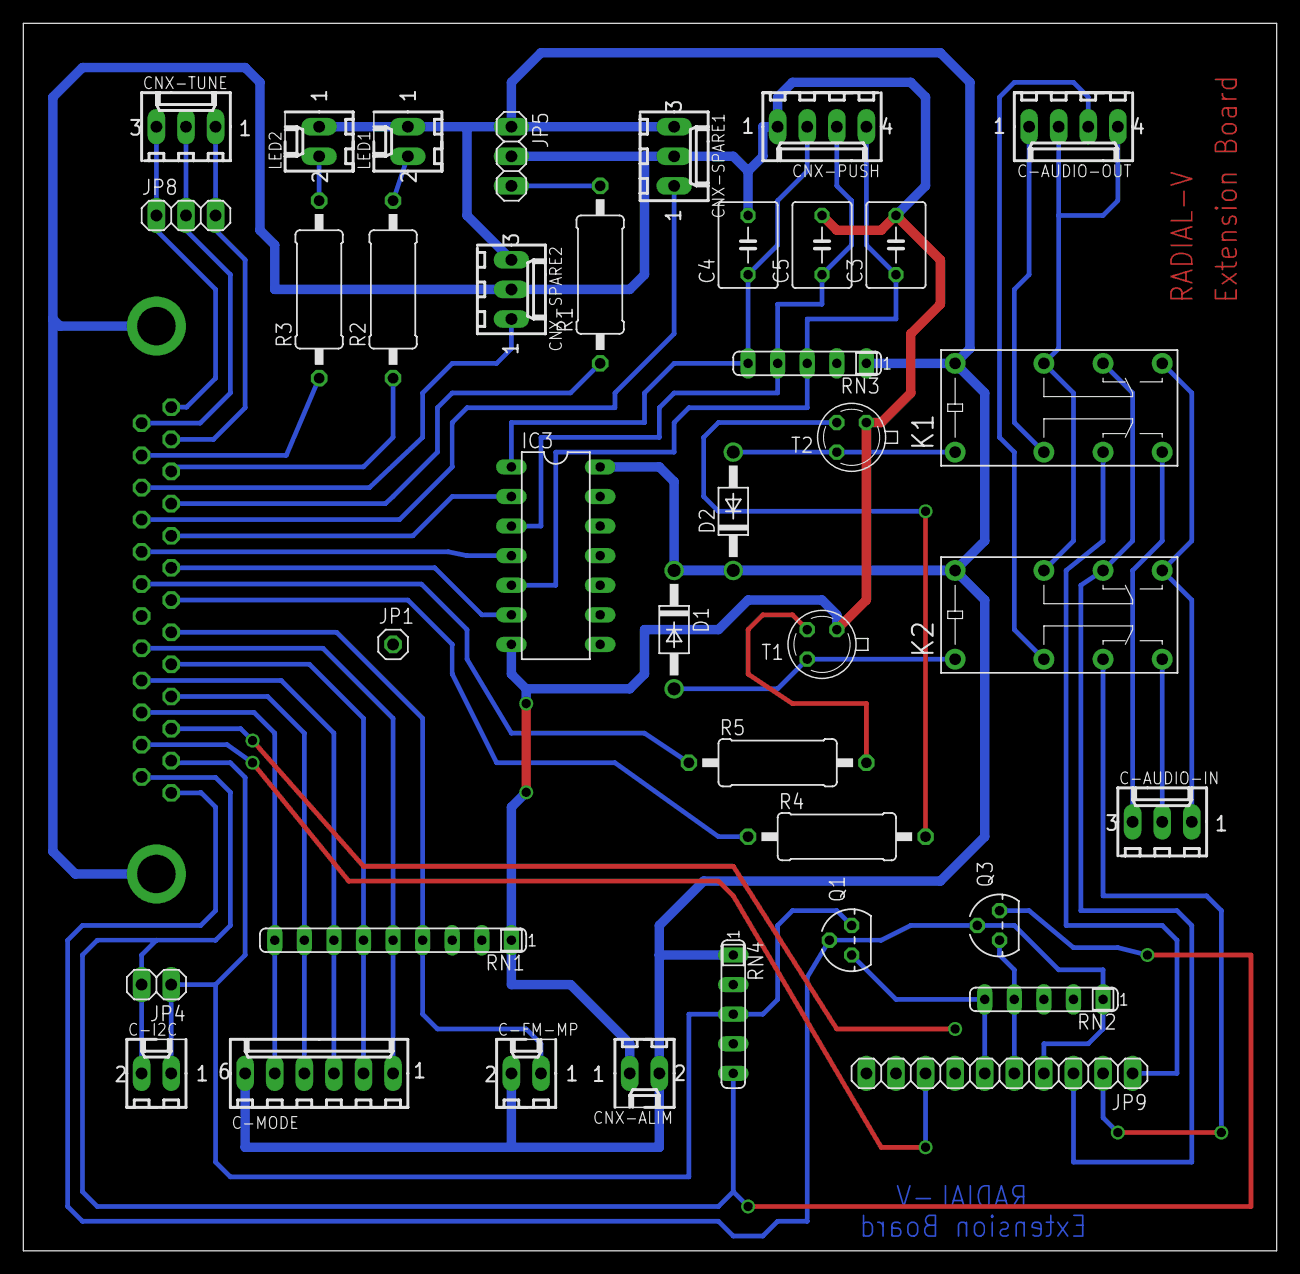
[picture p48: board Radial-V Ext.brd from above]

Board: 2 copper layers, 107.6 x 105.4 mm, 39 parts (1 on the bottom side), 47 nets.

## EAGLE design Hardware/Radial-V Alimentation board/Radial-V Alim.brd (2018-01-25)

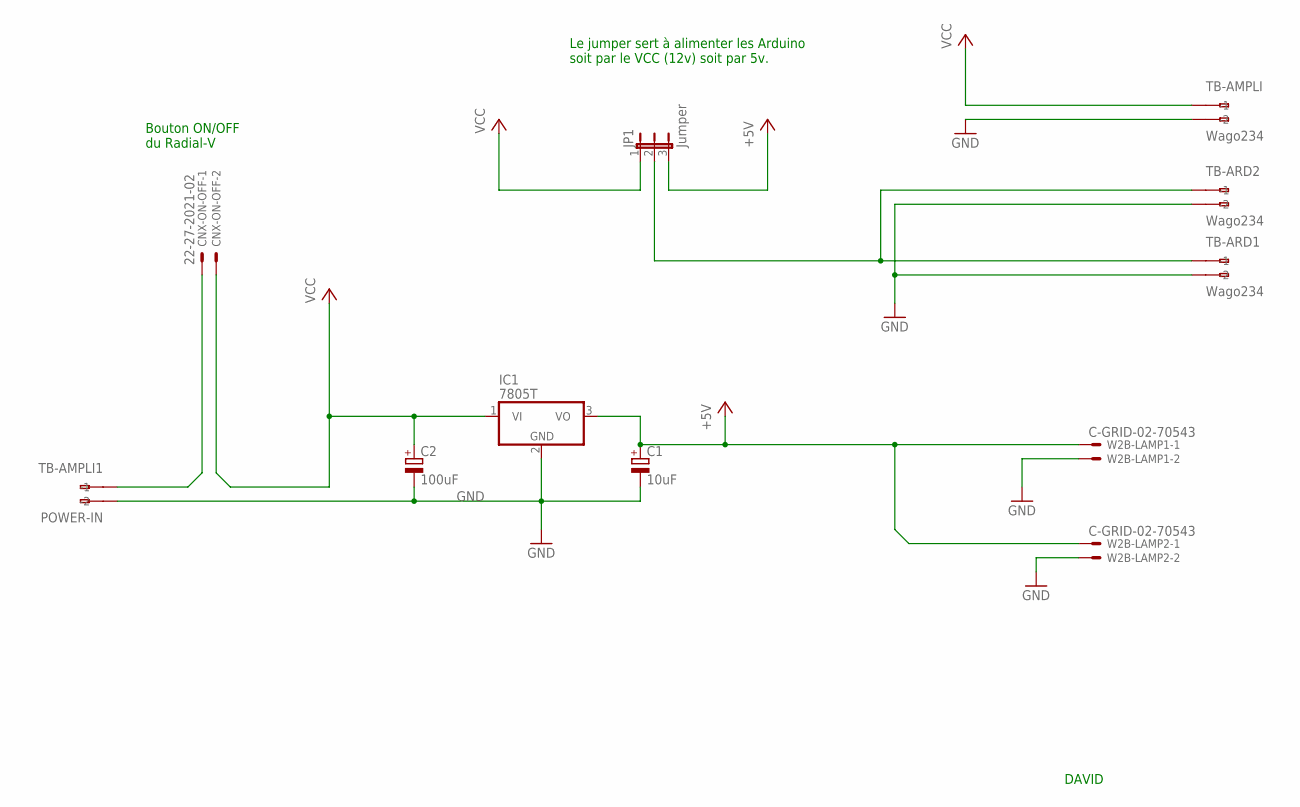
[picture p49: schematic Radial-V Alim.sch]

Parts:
C1: 10uF; E5-5
C2: 100uF; E22-10
CNX-ON-OFF: 22-27-2021-02; 6410-02
IC1: 7805T; TO220H
JP1: Jumper; JP2
TB-AMPLI: Wago234; 234-202
TB-AMPLI1: POWER-IN; 234-202
TB-ARD1, TB-ARD2: Wago234; 234-202
W2B-LAMP1, W2B-LAMP2: C-GRID-02-70543; 70543-02

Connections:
+5V: C1.+, IC1.3 (VO), JP1.3, W2B-LAMP1.1, W2B-LAMP2.1
GND: C1.-, C2.-, IC1.2 (GND), TB-AMPLI.A2 (-2), TB-AMPLI1.A2 (-2), TB-ARD1.A2 (-2), TB-ARD2.A2 (-2), W2B-LAMP1.2, W2B-LAMP2.2
unnamed: JP1.2, TB-ARD1.A1 (-1), TB-ARD2.A1 (-1)
unnamed: CNX-ON-OFF.1, TB-AMPLI1.A1 (-1)
VCC: C2.+, CNX-ON-OFF.2, IC1.1 (VI), JP1.1, TB-AMPLI.A1 (-1)

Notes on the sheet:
Le jumper sert à alimenter les Arduino soit par le VCC (12v) soit par 5v.
Bouton ON/OFF du Radial-V
DAVID

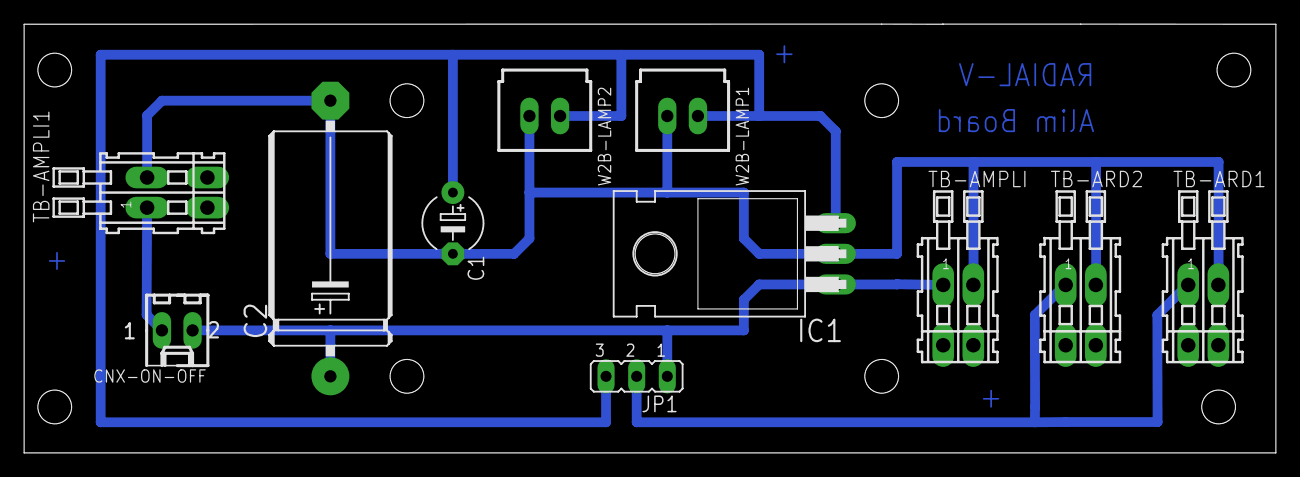
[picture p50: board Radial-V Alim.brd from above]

Board: 2 copper layers, 103.8 x 35.6 mm, 11 parts (0 on the bottom side), 5 nets.

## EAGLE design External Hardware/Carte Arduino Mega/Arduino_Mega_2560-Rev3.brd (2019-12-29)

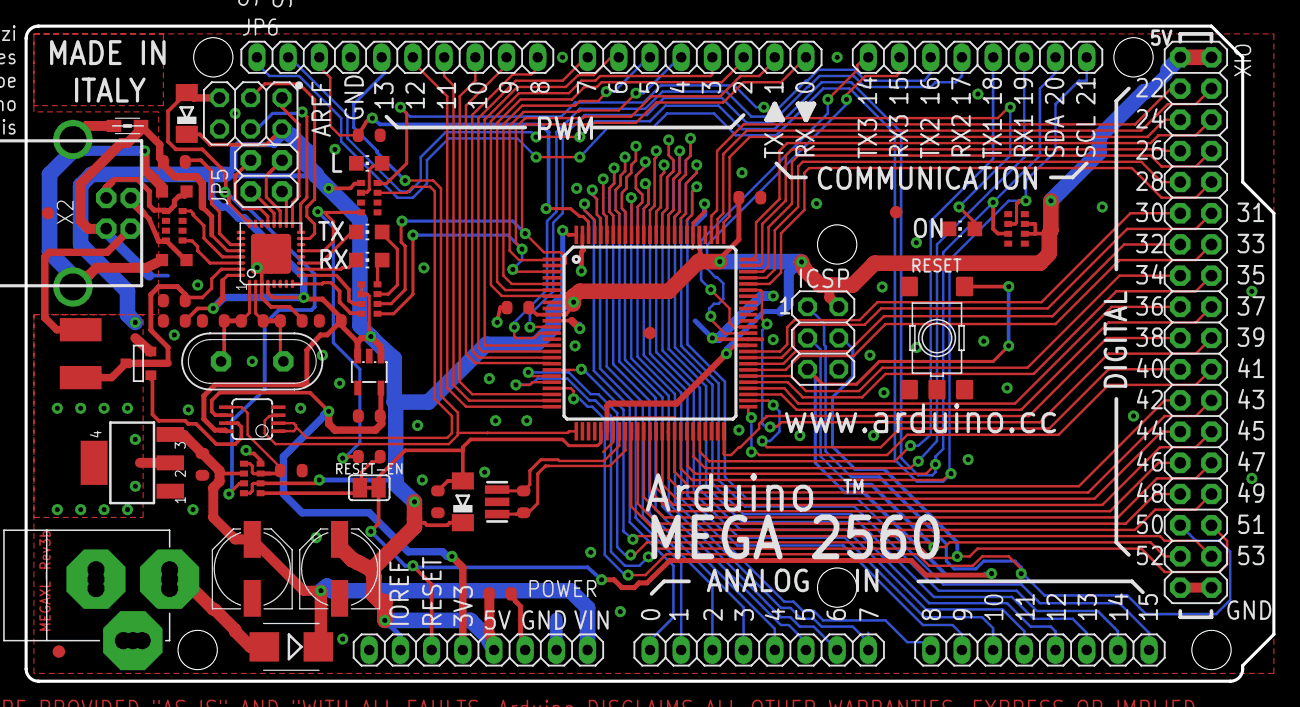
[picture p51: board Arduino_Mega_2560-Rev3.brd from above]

Board: 2 copper layers, 101.6 x 53.3 mm, 63 parts (1 on the bottom side), 110 nets.

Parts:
ADCH: 8x1F-H8.5; 1X08
ADCL: 8x1F-H8.5; 1X08
C1, C14, C15: 22p; C0603-ROUND
C2, C3, C4, C5, C6, C7, C8, C9, C11, C12: 100n; C0603-ROUND
C10, C13: 1u; C0603-ROUND
COMMUNICATION: 8x1F-H8.5; 1X08
D1: M7; SMB
D2, D3: CD1206-S01575; MINIMELF
F1: MF-MSMF050-2 500mA; L1812
FD1, FD2, FD3, FD4: FIDUCIALMOUNT; FIDUCIA-MOUNT
GROUND: SJ
IC1: NCP1117ST50T3G; SOT223
IC3: ATMEGA2560-16AU; TQFP100
IC4: ATMEGA16U2-MU; MLF32
IC6: LP2985-33DBVR; SOT23-DBV
IC7: LMV358IDGKR; MSOP08
ICSP, ICSP1: 3x2M; 2X03
JP5: 2x2M - NM; 2X02
JP6: 10x1F-H8.5; 1X10
L: YELLOW; CHIP-LED0805
L1: BLM21; 0805
ON: GREEN; CHIP-LED0805
PC1, PC2: 47u; PANASONIC_D
POWER: 8x1F-H8.5; 1X08
PWML: 8x1F-H8.5; 1X08
R1, R2: 1M; R0603-ROUND
RESET: TS42031-160R-TR-7260; TS42
RESET-EN: SJ
RN1, RN5: 10K; CAT16
RN2: 22R; CAY16
RN3, RN4: 1k; CAY16
RX: YELLOW; CHIP-LED0805
T1: FDN340P; SOT-23
TX: YELLOW; CHIP-LED0805
U$1: DISCLAIMER
X1: POWERSUPPLY_DC21MMX; POWERSUPPLY_DC-21MM
X2: USB-B_TH; PN61729
XIO: 18x2F-H8.5; 2X18
Y1: CSTCE16M0V53-R0 16MHZ; RESONATOR
Y2: 16MHz; QS
Z1, Z2: CG0603MLC-05E; CT/CN0603

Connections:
8PB4: IC4.18, JP5.1
8PB5: IC4.19, JP5.3
8PB6: IC4.20, JP5.2
8PB7: IC4.21, JP5.4
+3V3: C13.2, IC6.5, IC7.6, POWER.4
+5V: C4.1, C5.1, C6.1, C9.1, C11.2, D2.C, D3.C, IC1.2, IC1.4, IC3.10, IC3.31, IC3.61, IC3.80, IC3.100, IC4.4, IC4.32, IC6.1, IC6.3, IC7.8, ICSP.2, ICSP1.2, PC2.+, POWER.2, POWER.5, RN1.6, RN1.7, RN3.1, RN4.5, RN4.6, RN5.2, RN5.8, T1.2, XIO.1, XIO.2
ADC0: ADCL.1, IC3.97
ADC1: ADCL.2, IC3.96
ADC2: ADCL.3, IC3.95
ADC3: ADCL.4, IC3.94
ADC4: ADCL.5, IC3.93
ADC5: ADCL.6, IC3.92
ADC6: ADCL.7, IC3.91
ADC7: ADCL.8, IC3.90
ADC8: ADCH.1, IC3.89
ADC9: ADCH.2, IC3.88
ADC10: ADCH.3, IC3.87
ADC11: ADCH.4, IC3.86
ADC12: ADCH.5, IC3.85
ADC13: ADCH.6, IC3.84
ADC14: ADCH.7, IC3.83
ADC15: ADCH.8, IC3.82
AREF: C3.1, IC3.98, JP6.3
CMP: C12.2, IC7.5, RN5.3, RN5.5
D+: RN2.5, X2.3, Z2.2
D-: RN2.8, X2.2, Z1.2
DTR: C7.1, IC4.13, RN3.4
GATE_CMD: IC7.7, T1.3
GND: C1.2, C2.2, C3.2, C4.2, C5.2, C6.2, C8.2, C9.2, C11.1, C12.1, C13.1, C14.2, C15.2, GROUND.2, IC1.1, IC3.11, IC3.32, IC3.62, IC3.81, IC3.99, IC4.3, IC4.33, IC6.2, IC7.4, ICSP.6, ICSP1.6, JP6.4, L.C, ON.C, PC1.-, PC2.-, POWER.6, POWER.7, RESET.1, RESET.2, RN3.5, RN5.4, X1.1, X1.3, XIO.35, XIO.36, Y1.2
L13: IC7.1, IC7.2, RN3.7
M8RXD: IC4.9, RN4.7
M8TXD: IC4.8, RN4.8
MISO2: IC4.17, ICSP1.1
MOSI2: IC4.16, ICSP1.4
unnamed: L.A, RN3.2
unnamed: ON.A, RN3.8
unnamed: RN4.4, RX.A
unnamed: RN4.3, TX.A
PA0: IC3.78, XIO.3
PA1: IC3.77, XIO.4
PA2: IC3.76, XIO.5
PA3: IC3.75, XIO.6
PA4: IC3.74, XIO.7
PA5: IC3.73, XIO.8
PA6: IC3.72, XIO.9
PA7: IC3.71, XIO.10
PB0: IC3.19, XIO.34
PB1: IC3.20, ICSP.3, XIO.33
PB2: IC3.21, ICSP.4, XIO.32
PB3: IC3.22, ICSP.1, XIO.31
PB4: IC3.23, JP6.8
PB5: IC3.24, JP6.7
PB6: IC3.25, JP6.6
PB7: IC3.26, IC7.3, JP6.5
PC0: IC3.53, XIO.18
PC1: IC3.54, XIO.17
PC2: IC3.55, XIO.16
PC3: IC3.56, XIO.15
PC4: IC3.57, XIO.14
PC5: IC3.58, XIO.13
PC6: IC3.59, XIO.12
PC7: IC3.60, XIO.11
PD7: IC3.50, XIO.19
PE0: IC3.2, PWML.1, RN4.2
PE1: IC3.3, PWML.2, RN4.1
PE3: IC3.5, PWML.6
PE4: IC3.6, PWML.3
PE5: IC3.7, PWML.4
PG0: IC3.51, XIO.22
PG1: IC3.52, XIO.21
PG2: IC3.70, XIO.20
PG5: IC3.1, PWML.5
PH3: IC3.15, PWML.7
PH4: IC3.16, PWML.8
PH5: IC3.17, JP6.10
PH6: IC3.18, JP6.9
PL0: IC3.35, XIO.30
PL1: IC3.36, XIO.29
PL2: IC3.37, XIO.28
PL3: IC3.38, XIO.27
PL4: IC3.39, XIO.26
PL5: IC3.40, XIO.25
PL6: IC3.41, XIO.24
PL7: IC3.42, XIO.23
PWRIN: D1.A, X1.2
RD+: IC4.29, RN2.4
RD-: IC4.30, RN2.1
RESET: C1.1, C7.2, D3.A, IC3.30, ICSP.5, POWER.3, RESET.3, RESET.4, RESET-EN.1, RESET-EN.2, RN5.1
RESET2: D2.A, IC4.24, ICSP1.5, RN5.7
RXD1: COMMUNICATION.3, IC3.45
RXD2: COMMUNICATION.5, IC3.12
RXD3: COMMUNICATION.7, IC3.63
RXL: IC4.10, RX.C
SCK2: IC4.15, ICSP1.3
SCL: COMMUNICATION.1, IC3.43, JP6.1, RN1.2
SDA: COMMUNICATION.2, IC3.44, JP6.2, RN1.3
TXD1: COMMUNICATION.4, IC3.46
TXD2: COMMUNICATION.6, IC3.13
TXD3: COMMUNICATION.8, IC3.64
TXL: IC4.11, TX.C
UGND: C10.2, GROUND.1, IC4.28, L1.1, X2.4
USBVCC: C8.1, F1.1, IC4.31, T1.1
USHIELD: L1.2, X2.P$1, X2.P$2, Z1.1, Z2.1
VIN: C2.1, D1.C, IC1.3, PC1.+, POWER.8, RN5.6
VUCAP: C10.1, IC4.27
XT1: C14.1, IC4.1, R2.1, Y2.2
XT2: C15.1, IC4.2, R2.2, Y2.1
XTAL1: IC3.34, R1.1, Y1.3
XTAL2: IC3.33, R1.2, Y1.1
XVCC: F1.2, X2.1

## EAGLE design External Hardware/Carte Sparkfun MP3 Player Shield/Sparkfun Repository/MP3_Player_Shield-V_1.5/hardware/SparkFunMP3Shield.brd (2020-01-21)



Board: 2 copper layers, 53.3 x 59.7 mm, 62 parts (3 on the bottom side), 47 nets.

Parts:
C1, C6, C17, C18: 10uF; EIA3216
C2, C5, C7, C13, C14, C15, C16: 0.1uF; 0603-CAP
C3, C8: 22pF; 0603-CAP
C4: 470pF; 0603-CAP
C9: 1.0uF; 0603-CAP
C10, C11: 10nF; 0603-CAP
C12: 47nF; 0603-CAP
FRAME1: FRAME-LEDGER; CREATIVE_COMMONS
J1: ISP/SPI; 2X3
JP1: AUDIO-JACK-3.5MM-SMD
JP3: Optional; 1X03
LED1: Power; LED-0603
LOGO1: OSHW-LOGOS; OSHW-LOGO-S
LOGO2: SFE_LOGO_NAME_FLAME.1_INCH; SFE_LOGO_NAME_FLAME_.1
Q1: 12.288MHz; CRYSTAL-SMD-5X3
R1: 1M; 0603-RES
R2, R3, R4, R5, R10, R11, R12: 100k; 0603-RES
R6, R7: 20; 0603-RES
R8: 330; 0603-RES
R9: 10; 0603-RES
R13, R14: 1K; 0603-RES
R15, R16: 10K; 0603-RES
R21, R22: 470; 0603-RES
S2: Reset; TACTILE_SWITCH_SMD
SJ1, SJ2: NC; SJ_2S-TRACE
SJ3: AC Coupling L; PAD-JUMPER-3-2OF3_NC_BY_PASTE_YES_SILK_FULL_BOX
SJ4: AC Coupling R; PAD-JUMPER-3-2OF3_NC_BY_PASTE_YES_SILK_FULL_BOX
SJ5: AC Coupling Gnd; PAD-JUMPER-3-2OF3_NC_BY_PASTE_YES_SILK_FULL_BOX
TP1, TP2: PAD.03X.05
U1: 3.3V; SOT23-5
U2: ARDUINO_R3_SHIELD; UNO_R3_SHIELD
U3: VS1053; LQFP-48
U4: 1.8V; SC70
U6: USD-SOCKET; MICRO-SD-SOCKET-PP
U7: 74HC4050 LVL CONVERTER; SO016
U$1: REVISION
U$4, U$5: FIDUCIAL1X2; FIDUCIAL-1X2
U$8: LOGO-SFENEW; SFE-NEW-WEBLOGO

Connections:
1.8V: C1.A, C2.1, C16.1, TP2.P$1, U3.5, U3.7, U3.24, U3.31, U4.5
3.3V: C5.1, C6.A, C7.1, C13.1, C14.1, C15.1, R2.2, R8.2, TP1.P$1, U1.5, U3.6, U3.14, U3.19, U3.32, U3.38, U3.43, U3.45, U4.1, U4.3, U6.4, U7.1
5V-GPIO1: SJ1.2, U2.D4
5V-MIDI-RX: SJ2.1, U2.D3
5V-MOSI: J1.4, U2.D11, U7.3
5V-MP3-CS: U2.D6, U7.9
5V-MP3-DCS: U2.D7, U7.11
5V-MP3-RST: U2.D8, U7.14
5V-SCK: J1.3, U2.D13, U7.7
5V-SD-CS: U2.D9, U7.5
ARST: S2.3, U2.RES
G1: R3.2, U3.9, U3.10, U3.11, U3.12
G2: R4.2, U3.25
GBUF: R9.2, SJ5.3, U3.42
GND: C1.C, C2.2, C3.1, C4.2, C5.2, C6.C, C7.2, C8.1, C9.1, C10.2, C11.2, C12.2, C13.2, C14.2, C15.2, C16.2, J1.6, LED1.C, R3.1, R4.1, R5.1, R10.1, R11.1, R12.1, R15.2, R16.2, S2.1, SJ5.1, U1.2, U2.GND@0, U2.GND@1, U2.GND@2, U3.4, U3.16, U3.20, U3.21, U3.22, U3.35, U3.37, U3.40, U3.41, U3.47, U4.2, U6.6, U6.CD1, U6.CD2, U6.GND1, U6.GND3, U7.8
GPIO0: R11.2, U3.33
GPIO1: R10.2, R14.1, U3.34
GPIO4: R12.2, U3.36
LEFT: R7.2, R21.2, SJ3.3, U3.46
MIDI-RX: R2.1, R13.2, U3.26
MISO: J1.1, U2.D12, U3.30, U6.7
MOSI: U3.29, U6.3, U7.2
MP3-CS: U3.23, U7.10
MP3-DCS: U3.13, U7.12
MP3-DREQ: U2.D2, U3.8
MP3-RST: R5.2, U3.3, U7.15
unnamed: C12.1, R9.1
unnamed: C10.1, R6.1
unnamed: R14.2, SJ1.1
unnamed: C11.1, R7.1
unnamed: LED1.A, R8.1
unnamed: R13.1, SJ2.2
unnamed: C3.2, Q1.3, R1.2, U3.18
unnamed: C8.2, Q1.1, R1.1, U3.17
unnamed: JP1.SLEEVE, JP3.1, SJ5.2
unnamed: JP1.RING, JP3.2, SJ4.2
unnamed: JP1.TIP, JP3.3, SJ3.2
unnamed: C18.A, R22.1
unnamed: C17.A, R21.1
unnamed: C4.1, U1.4
RCAP: C9.2, U3.44
RIGHT: R6.2, R22.2, SJ4.3, U3.39
SCK: U3.28, U6.5, U7.6
SD-CS: U6.2, U7.4
SPKR-L: C17.C, R15.1, SJ3.1
SPKR-R: C18.C, R16.1, SJ4.1
VCC: J1.2, U1.1, U1.3, U2.5V

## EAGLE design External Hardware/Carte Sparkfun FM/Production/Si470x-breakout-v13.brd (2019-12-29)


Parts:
C1: 0.1uF; 0402-CAP
C2: 22nF; 0402-CAP
C3, C4: 22pF; 0402-CAP
C5: 4.7pF; 0402-CAP
C6, C7: 1uF; 0402-CAP
JP1: M10"; 1X10
JP2: LOGO-SFENW2; SFE-NEW-WEB
JP3: LOGO-SFESK; SFE-LOGO-FLAME
JP4, JP6: FIDUCIALUFIDUCIAL; MICRO-FIDUCIAL
JP5: M01PTH; 1X01
L1: ferrite; C0402
R1, R2: 10k; 0402-RES
R3, R8: 4.7k; 0402-RES
R9, R10, R11, R12: 330; 0402-RES
U1: SI4703; SPARKFUN_SI470X
U$1: CREATIVE_COMMONS
U$3: OSHW-LOGOS; OSHW-LOGO-S
Y1: 32.768kHz; CRYSTAL-32KHZ-SMD

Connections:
3.3V: C1.1, C2.1, JP1.7, R2.2, R3.2, R8.2, U1.10 (VIO), U1.11 (VD), U1.16 (VA)
!RST: JP1.3, R12.2
!RST-L: R1.1, R12.1, U1.5 (!RST)
!SEN: JP1.4, R11.2
!SEN-L: R2.1, R11.1, U1.6 (!SEN)
ANT: JP5.1, L1.1
GND: C1.2, C2.2, C3.1, C4.1, C5.2, JP1.8, R1.2, U1.3 (RFGND), U1.4 (LPI), U1.12 (GND), U1.15 (DOUT), U1.21 (GND)
GPIO1: JP1.2, U1.19 (GPIO1)
GPIO2: JP1.1, U1.18 (GPIO2)
LOUT: C6.2, JP1.10
unnamed: C4.2, U1.9 (RCLK), Y1.X2 (2)
unnamed: C3.2, U1.17 (GPIO3), Y1.X1 (1)
unnamed: C5.1, L1.2, U1.2 (FMIP)
unnamed: C6.1, U1.14 (LOUT)
unnamed: C7.1, U1.13 (ROUT)
ROUT: C7.2, JP1.9
SCLK: JP1.5, R10.2
SCLK-L: R3.1, R10.1, U1.7 (SCLK)
SDIO: JP1.6, R9.2
SDIO-L: R8.1, R9.1, U1.8 (SDIO)

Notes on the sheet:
SEN is pulled high enabling I2C
RST is pulled low enabling the IC
A. Weiss
2.7 < VCC < 3.3V
NOTES:
*you can solder a single
piece of wire here for
the antenna, up to
1.5 meters.
*also see Si app note AN231



Board: 2 copper layers, 25.4 x 14.0 mm, 26 parts (2 on the bottom side), 20 nets.

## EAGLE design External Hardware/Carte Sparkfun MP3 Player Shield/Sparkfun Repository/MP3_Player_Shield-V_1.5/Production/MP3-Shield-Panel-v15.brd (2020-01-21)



Board: 2 copper layers, 120.9 x 140.2 mm, 243 parts (12 on the bottom side), 188 nets.

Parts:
C1, C6, C17, C18, C20, C21, C35, C36, C38, C39, C53, C54, C56, C57, C71, C72: 10uF; EIA3216
C2, C5, C7, C13, C14, C15, C16, C19, C22, C30, C31, C32, C33, C34, C37, C40, C48, C49, C50, C51, C52, C55, C58, C66, C67, C68, C69, C70: 0.1uF; 0603-CAP
C3, C8, C23, C24, C41, C42, C59, C60: 22pF; 0603-CAP
C4, C29, C47, C65: 470pF; 0603-CAP
C9, C25, C43, C61: 1.0uF; 0603-CAP
C10, C11, C26, C27, C44, C45, C62, C63: 10nF; 0603-CAP
C12, C28, C46, C64: 47nF; 0603-CAP
E$1: FIDUCIAL-1.5X3
E$4, E$5: FIDUCIAL-1X2
J1, J2, J3, J4: ISP/SPI; 2X3
JP1, JP2, JP5, JP7: AUDIO-JACK-3.5MM-SMD
JP3, JP4, JP6, JP8: Optional; 1X03
LED1, LED2, LED3, LED4: Power; LED-0603
LOGO1, LOGO3, LOGO5, LOGO7: OSHW-LOGOS; OSHW-LOGO-S
LOGO2, LOGO4, LOGO6, LOGO8: SFE_LOGO_NAME_FLAME.1_INCH; SFE_LOGO_NAME_FLAME_.1
Q1, Q2, Q3, Q4: 12.288MHz; CRYSTAL-SMD-5X3
R1, R18, R38, R56: 1M; 0603-RES
R2, R3, R4, R5, R10, R11, R12, R19, R20, R23, R27, R28, R29, R30, R39, R40, R41, R45, R46, R47, R48, R57, R58, R59, R63, R64, R65, R66: 100k; 0603-RES
R6, R7, R24, R25, R42, R43, R60, R61: 20; 0603-RES
R8, R17, R37, R55: 330; 0603-RES
R9, R26, R44, R62: 10; 0603-RES
R13, R14, R31, R32, R49, R50, R67, R68: 1K; 0603-RES
R15, R16, R33, R34, R51, R52, R69, R70: 10K; 0603-RES
R21, R22, R35, R36, R53, R54, R71, R72: 470; 0603-RES
S1, S2, S3, S4: Reset; TACTILE_SWITCH_SMD
SJ1, SJ2, SJ6, SJ7, SJ11, SJ12, SJ16, SJ17: NC; SJ_2S-TRACE
SJ3, SJ8, SJ13, SJ18: AC Coupling L; PAD-JUMPER-3-2OF3_NC_BY_PASTE_YES_SILK_FULL_BOX
SJ4, SJ9, SJ14, SJ19: AC Coupling R; PAD-JUMPER-3-2OF3_NC_BY_PASTE_YES_SILK_FULL_BOX
SJ5, SJ10, SJ15, SJ20: AC Coupling Gnd; PAD-JUMPER-3-2OF3_NC_BY_PASTE_YES_SILK_FULL_BOX
TP1, TP2, TP3, TP4, TP5, TP6, TP7, TP8: PAD.03X.05
U1, U5, U13, U19: 3.3V; SOT23-5
U2, U12, U18, U24: ARDUINO_R3_SHIELD; UNO_R3_SHIELD
U3, U8, U14, U20: VS1053; LQFP-48
U4, U9, U15, U21: 1.8V; SC70
U6, U10, U16, U22: USD-SOCKET; MICRO-SD-SOCKET-PP
U7, U11, U17, U23: 74HC4050 LVL CONVERTER; SO016
U$1, U$2, U$4, U$5, U$6, U$7, U$10, U$11: FIDUCIAL1X2; FIDUCIAL-1X2
U$3, U$8, U$9, U$12: LOGO-SFENEW; SFE-NEW-WEBLOGO

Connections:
1.8V: C1.A, C2.1, C16.1, TP2.P$1, U3.5, U3.7, U3.24, U3.31, U4.5
1.8V1: C21.A, C22.1, C33.1, TP4.P$1, U8.5, U8.7, U8.24, U8.31, U9.5
1.8V2: C39.A, C40.1, C51.1, TP6.P$1, U14.5, U14.7, U14.24, U14.31, U15.5
1.8V3: C57.A, C58.1, C69.1, TP8.P$1, U20.5, U20.7, U20.24, U20.31, U21.5
3.3V: C5.1, C6.A, C7.1, C13.1, C14.1, C15.1, R2.2, R8.2, TP1.P$1, U1.5, U3.6, U3.14, U3.19, U3.32, U3.38, U3.43, U3.45, U4.1, U4.3, U6.4, U7.1
3.3V1: C19.1, C20.A, C30.1, C31.1, C32.1, C34.1, R17.2, R19.2, TP3.P$1, U5.5, U8.6, U8.14, U8.19, U8.32, U8.38, U8.43, U8.45, U9.1, U9.3, U10.4, U11.1
3.3V2: C37.1, C38.A, C48.1, C49.1, C50.1, C52.1, R37.2, R39.2, TP5.P$1, U13.5, U14.6, U14.14, U14.19, U14.32, U14.38, U14.43, U14.45, U15.1, U15.3, U16.4, U17.1
3.3V3: C55.1, C56.A, C66.1, C67.1, C68.1, C70.1, R55.2, R57.2, TP7.P$1, U19.5, U20.6, U20.14, U20.19, U20.32, U20.38, U20.43, U20.45, U21.1, U21.3, U22.4, U23.1
5V-GPIO1: SJ1.2, U2.D4
5V-GPIO2: SJ7.2, U12.D4
5V-GPIO3: SJ12.2, U18.D4
5V-GPIO4: SJ17.2, U24.D4
5V-MIDI-RX: SJ2.1, U2.D3
5V-MIDI-RX1: SJ6.1, U12.D3
5V-MIDI-RX2: SJ11.1, U18.D3
5V-MIDI-RX3: SJ16.1, U24.D3
5V-MOSI: J1.4, U2.D11, U7.3
5V-MOSI1: J2.4, U11.3, U12.D11
5V-MOSI2: J3.4, U17.3, U18.D11
5V-MOSI3: J4.4, U23.3, U24.D11
5V-MP3-CS: U2.D6, U7.9
5V-MP3-CS1: U11.9, U12.D6
5V-MP3-CS2: U17.9, U18.D6
5V-MP3-CS3: U23.9, U24.D6
5V-MP3-DCS: U2.D7, U7.11
5V-MP3-DCS1: U11.11, U12.D7
5V-MP3-DCS2: U17.11, U18.D7
5V-MP3-DCS3: U23.11, U24.D7
5V-MP3-RST: U2.D8, U7.14
5V-MP3-RST1: U11.14, U12.D8
5V-MP3-RST2: U17.14, U18.D8
5V-MP3-RST3: U23.14, U24.D8
5V-SCK: J1.3, U2.D13, U7.7
5V-SCK1: J2.3, U11.7, U12.D13
5V-SCK2: J3.3, U17.7, U18.D13
5V-SCK3: J4.3, U23.7, U24.D13
5V-SD-CS: U2.D9, U7.5
5V-SD-CS1: U11.5, U12.D9
5V-SD-CS2: U17.5, U18.D9
5V-SD-CS3: U23.5, U24.D9
ARST: S2.3, U2.RES
ARST1: S1.3, U12.RES
ARST2: S3.3, U18.RES
ARST3: S4.3, U24.RES
G1: R3.2, U3.9, U3.10, U3.11, U3.12
G2: R4.2, U3.25
G3: R20.2, U8.9, U8.10, U8.11, U8.12
G4: R29.2, U8.25
G5: R40.2, U14.9, U14.10, U14.11, U14.12
G6: R47.2, U14.25
G7: R58.2, U20.9, U20.10, U20.11, U20.12
G8: R65.2, U20.25
GBUF: R9.2, SJ5.3, U3.42
GBUF1: R26.2, SJ10.3, U8.42
GBUF2: R44.2, SJ15.3, U14.42
GBUF3: R62.2, SJ20.3, U20.42
GND: C1.C, C2.2, C3.1, C4.2, C5.2, C6.C, C7.2, C8.1, C9.1, C10.2, C11.2, C12.2, C13.2, C14.2, C15.2, C16.2, J1.6, LED1.C, R3.1, R4.1, R5.1, R10.1, R11.1, R12.1, R15.2, R16.2, S2.1, SJ5.1, U1.2, U2.GND@0, U2.GND@1, U2.GND@2, U3.4, U3.16, U3.20, U3.21, U3.22, U3.35, U3.37, U3.40, U3.41, U3.47, U4.2, U6.6, U6.CD1, U6.CD2, U6.GND1, U6.GND3, U7.8
GND1: C19.2, C20.C, C21.C, C22.2, C23.1, C24.1, C25.1, C26.2, C27.2, C28.2, C29.2, C30.2, C31.2, C32.2, C33.2, C34.2, J2.6, LED2.C, R20.1, R23.1, R27.1, R28.1, R29.1, R30.1, R33.2, R34.2, S1.1, SJ10.1, U5.2, U8.4, U8.16, U8.20, U8.21, U8.22, U8.35, U8.37, U8.40, U8.41, U8.47, U9.2, U10.6, U10.CD1, U10.CD2, U10.GND1, U10.GND3, U11.8, U12.GND@0, U12.GND@1, U12.GND@2
GND2: C37.2, C38.C, C39.C, C40.2, C41.1, C42.1, C43.1, C44.2, C45.2, C46.2, C47.2, C48.2, C49.2, C50.2, C51.2, C52.2, J3.6, LED3.C, R40.1, R41.1, R45.1, R46.1, R47.1, R48.1, R51.2, R52.2, S3.1, SJ15.1, U13.2, U14.4, U14.16, U14.20, U14.21, U14.22, U14.35, U14.37, U14.40, U14.41, U14.47, U15.2, U16.6, U16.CD1, U16.CD2, U16.GND1, U16.GND3, U17.8, U18.GND@0, U18.GND@1, U18.GND@2
GND3: C55.2, C56.C, C57.C, C58.2, C59.1, C60.1, C61.1, C62.2, C63.2, C64.2, C65.2, C66.2, C67.2, C68.2, C69.2, C70.2, J4.6, LED4.C, R58.1, R59.1, R63.1, R64.1, R65.1, R66.1, R69.2, R70.2, S4.1, SJ20.1, U19.2, U20.4, U20.16, U20.20, U20.21, U20.22, U20.35, U20.37, U20.40, U20.41, U20.47, U21.2, U22.6, U22.CD1, U22.CD2, U22.GND1, U22.GND3, U23.8, U24.GND@0, U24.GND@1, U24.GND@2
GPIO0: R11.2, U3.33
GPIO1: R10.2, R14.1, U3.34
GPIO2: R28.2, U8.33
GPIO3: R27.2, R32.1, U8.34
GPIO4: R12.2, U3.36
GPIO5: R30.2, U8.36
GPIO6: R46.2, U14.33
GPIO7: R45.2, R50.1, U14.34
GPIO8: R48.2, U14.36
GPIO9: R64.2, U20.33
GPIO10: R63.2, R68.1, U20.34
GPIO11: R66.2, U20.36
LEFT: R7.2, R21.2, SJ3.3, U3.46
LEFT1: R25.2, R35.2, SJ8.3, U8.46
LEFT2: R43.2, R53.2, SJ13.3, U14.46
LEFT3: R61.2, R71.2, SJ18.3, U20.46
MIDI-RX: R2.1, R13.2, U3.26
MIDI-RX1: R19.1, R31.2, U8.26
MIDI-RX2: R39.1, R49.2, U14.26
MIDI-RX3: R57.1, R67.2, U20.26
MISO: J1.1, U2.D12, U3.30, U6.7
MISO1: J2.1, U8.30, U10.7, U12.D12
MISO2: J3.1, U14.30, U16.7, U18.D12
MISO3: J4.1, U20.30, U22.7, U24.D12
MOSI: U3.29, U6.3, U7.2
MOSI1: U8.29, U10.3, U11.2
MOSI2: U14.29, U16.3, U17.2
MOSI3: U20.29, U22.3, U23.2
MP3-CS: U3.23, U7.10
MP3-CS1: U8.23, U11.10
MP3-CS2: U14.23, U17.10
MP3-CS3: U20.23, U23.10
MP3-DCS: U3.13, U7.12
MP3-DCS1: U8.13, U11.12
MP3-DCS2: U14.13, U17.12
MP3-DCS3: U20.13, U23.12
MP3-DREQ: U2.D2, U3.8
MP3-DREQ1: U8.8, U12.D2
MP3-DREQ2: U14.8, U18.D2
MP3-DREQ3: U20.8, U24.D2
MP3-RST: R5.2, U3.3, U7.15
MP3-RST1: R23.2, U8.3, U11.15
MP3-RST2: R41.2, U14.3, U17.15
MP3-RST3: R59.2, U20.3, U23.15
unnamed: LED2.A, R17.1
unnamed: C12.1, R9.1
unnamed: C10.1, R6.1
unnamed: R14.2, SJ1.1
unnamed: C11.1, R7.1
unnamed: LED1.A, R8.1
unnamed: C23.2, Q2.3, R18.2, U8.18
unnamed: R13.1, SJ2.2
unnamed: C3.2, Q1.3, R1.2, U3.18
unnamed: C8.2, Q1.1, R1.1, U3.17
unnamed: C24.2, Q2.1, R18.1, U8.17
unnamed: JP1.SLEEVE, JP3.1, SJ5.2
unnamed: JP1.RING, JP3.2, SJ4.2
unnamed: JP1.TIP, JP3.3, SJ3.2
unnamed: C28.1, R26.1
unnamed: C27.1, R25.1
unnamed: C18.A, R22.1
unnamed: C26.1, R24.1
unnamed: C17.A, R21.1
unnamed: C29.1, U5.4
unnamed: R31.1, SJ6.2
unnamed: R32.2, SJ7.1
unnamed: C36.A, R36.1
unnamed: C35.A, R35.1
unnamed: JP2.SLEEVE, JP4.1, SJ10.2
unnamed: JP2.RING, JP4.2, SJ9.2
unnamed: JP2.TIP, JP4.3, SJ8.2
unnamed: LED3.A, R37.1
unnamed: C41.2, Q3.3, R38.2, U14.18
unnamed: C42.2, Q3.1, R38.1, U14.17
unnamed: C46.1, R44.1
unnamed: C45.1, R43.1
unnamed: C44.1, R42.1
unnamed: C47.1, U13.4
unnamed: R49.1, SJ11.2
unnamed: R50.2, SJ12.1
unnamed: C54.A, R54.1
unnamed: C53.A, R53.1
unnamed: JP5.SLEEVE, JP6.1, SJ15.2
unnamed: JP5.RING, JP6.2, SJ14.2
unnamed: JP5.TIP, JP6.3, SJ13.2
unnamed: LED4.A, R55.1
unnamed: C59.2, Q4.3, R56.2, U20.18
unnamed: C60.2, Q4.1, R56.1, U20.17
unnamed: C64.1, R62.1
unnamed: C63.1, R61.1
unnamed: C62.1, R60.1
unnamed: C65.1, U19.4
unnamed: R67.1, SJ16.2
unnamed: R68.2, SJ17.1
unnamed: C72.A, R72.1
unnamed: C71.A, R71.1
unnamed: JP7.SLEEVE, JP8.1, SJ20.2
unnamed: JP7.RING, JP8.2, SJ19.2
unnamed: JP7.TIP, JP8.3, SJ18.2
unnamed: C4.1, U1.4
RCAP: C9.2, U3.44
RCAP1: C25.2, U8.44
RCAP2: C43.2, U14.44
RCAP3: C61.2, U20.44
RIGHT: R6.2, R22.2, SJ4.3, U3.39
RIGHT1: R24.2, R36.2, SJ9.3, U8.39
RIGHT2: R42.2, R54.2, SJ14.3, U14.39
RIGHT3: R60.2, R72.2, SJ19.3, U20.39
SCK: U3.28, U6.5, U7.6
SCK1: U8.28, U10.5, U11.6
SCK2: U14.28, U16.5, U17.6
SCK3: U20.28, U22.5, U23.6
SD-CS: U6.2, U7.4
SD-CS1: U10.2, U11.4
SD-CS2: U16.2, U17.4
SD-CS3: U22.2, U23.4
SPKR-L: C17.C, R15.1, SJ3.1
SPKR-L1: C35.C, R33.1, SJ8.1
SPKR-L2: C53.C, R51.1, SJ13.1
SPKR-L3: C71.C, R69.1, SJ18.1
SPKR-R: C18.C, R16.1, SJ4.1
SPKR-R1: C36.C, R34.1, SJ9.1
SPKR-R2: C54.C, R52.1, SJ14.1
SPKR-R3: C72.C, R70.1, SJ19.1
VCC: J1.2, U1.1, U1.3, U2.5V
VCC1: J2.2, U5.1, U5.3, U12.5V
VCC2: J3.2, U13.1, U13.3, U18.5V
VCC3: J4.2, U19.1, U19.3, U24.5V

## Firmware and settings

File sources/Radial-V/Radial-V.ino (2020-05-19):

/* ************************************************************************************************
 *  
 *   RADIAL-V
 *
 * Software pour la radio Radial-V.
 *
 * Pilotage par Arduino-Mega d'un player MP3 et d'un ecran LCD (+ tuner FM)
 *
 * Les musiques sont sur la carte SD du player MP3, et doivent etre préparées préalablement 
 * avec l'utilitaire mp3tag.exe (voir doc).
 *
 * Note:
 *   The F() macro tells the compiler to leave this particular array in PROGMEM (Flash). 
 *   (cela economise de la RAM programme)
 *   Then when it is time to access it, one byte of the data is copied to RAM at a time. 
 *   There’s a small performance overhead for this extra work. However, printing strings 
 *   over Serial or to a LCD is a really slow process, so a few extra clock cycles really won’t matter.
 *
 *************************************************************************************************** 
 * 0.7  01/11/2015  Mise en commentaire de la gestion de la carte MP3 dans MusicPlayer.cpp, suite à un pb hardware.(La carte SD ne peut lus être lue).
 *                  Version non opérationnelle: conflit à la compilation entre les librairies SD et SDfat, et pb de compil avec TFT.image
 * 0.8  01/11/2015  Rétablissement de la gestion de la carte MP3
 * 1.0  16/11/2015  Déport de la fonction d'affichage sur un autre Arduino, piloté en I2C
 * 1.1  23/11/2015  Implementation I2C complete. Augmentation du nombre de MP3 (env 200).
 * 1.2  28/11/2015  Le Catalogue regroupe Random et Genre.
 * 1.3  02/12/2015  Le Catalogue regroupe Year et Favorites. Installation des cartes d'extension.
 * 2.0  02/12/2019  Gestion des versions sous GitHub
 * 2.1  23/02/2020  Remapping des E/S : adaptation à la nouvelle carte "Bus Board v2"
 * 2.2  07/04/2020  Ajout FM radio shield
 * 2.3  18/04/2020  Abandon FM radio shield (Ne fonctionne pas sur un Arduino MEGA avec I2C partagé). Refonte ed la recherche.
 * 2.4  18/05/2020  VERSION DE PRODUCTION
 * 2.5  en cours    améliorations
 *************************************************************************************************** 
*/

#include <SPI.h>
#include <SdFat.h>
#include <SdFatUtil.h> 
#include <SFEMP3Shield.h>

#include "Radial-V.h"
#include "MusicPlayer.h"
#include "RadioPlayer.h"
#include "RotaryButton.h"
#include "CapButton.h"
#include "SelfReturnButton.h"
#include "Catalog.h"
#include "RemoteDisplay.h"

// Pour le debug: On peut mettre FALSE pour tester avec un seul Arduino. 
// Pour la prod : Mettre TRUE.
#define USE_TWO_ARDUINO true

// *******************************************************************************
// Mapping du cablage
// *******************************************************************************
// MP3 data request     // D2 DataRequest   (MP3 shield) avec hardware interrupt 0
#define AGAIN      3    // D3   Digital In avec hardware interrupt 1
// Midi-In              // D3   NOT USED    (MP3 shield) avec hardware interrupt 1
// GPIO                 // D4   GPIO        (MP3 shield)
// MP3-reset            // D8   MP3 reset   (MP3 shield)
#define MP3_CS     6    // D6   MP3 CS      (MP3 shield)
#define MP3_DCS    7    // D7   MP3 data CS (MP3 shield)
#define SD_CS      9    // D9   SD CS       (MP3 shield)

#define NEXT       18   // D18  Digital In     avec hardware interrupt 5
#define PROMOTE    19   // D19  Digital In     avec hardware interrupt 4

// ------------------ Pour RadioPlayer
#define FM_RESET   17 // D17 output : FM shield RST* Command (active LOW)
#define FM_SDIO    20 // D20 I2C Bus - Digital In/out avec hardware interrupt 3
#define FM_SCLK    21 // D21 I2C Bus - Digital In/out avec hardware interrupt 2
#define FM_GPIO2   23 // D23 input  : FM shield pulse received then Seek/Tune completed. (pin GPI02 du shield FM Si7403)

#define MODE_4     25   // D25  input   C-MODE-5    bouton Mode
#define MODE_3     27   // D27  input   C-MODE-4    bouton Mode
#define MODE_2     29   // D29  input   C-MODE-3    bouton Mode
#define MODE_1     31   // D31  input   C-MODE-2    bouton Mode
#define MP3_ON     33   // D33  input   C-MODE-1    selecteur FM/MP3 
#define FM_ON      35   // D35  input   C-FMMP-1    selecteur FM/MP3
#define SPARE1     37   // D37  Spare1 Connector
#define K1         39   // D39  Digital Out Commande du relais K1
#define K2         41   // D41  Digital Out Commande du relais K2
#define SPARE_LED  43   // D43  input   SPARE LED (connector JP5)
#define LED_1      45   // D45  output  LED
#define LED_2      47   // D47  output  LED
#define SPARE2     49   // D49  Spare2 Connector
// SPI_MISO             // D50  input  
// SPI_MOSI             // D51  output 
// SPI_SCLK             // D52  output 
// SPI_SS               // D53  input  (configuré en output car Master)


#define TUNE_OUT   A12    // Analog output for bouton Tune (charge pin): Créneaux de 5v.
#define TUNE_IN    A14    // Analog input for bouton Tune: Read value



// *******************************************************************************
// variables globales
// *******************************************************************************
MusicPlayer        MP3Player(SD_CS);
RadioPlayer        FMshield(FM_RESET, FM_SDIO, FM_SCLK, FM_GPIO2);
Catalog            Catalogue;
Rotary             ModeButton(MODE_1,MODE_2,MODE_3,MODE_4); 
Rotary             SourceButton(MP3_ON, FM_ON); 
CapButton          TuneButton(TUNE_OUT,TUNE_IN);
SelfReturnButton   PromoteButton(PROMOTE, &ISR_PromoteButton);   
SelfReturnButton   AgainButton(AGAIN,     &ISR_AgainButton);     
SelfReturnButton   NextButton(NEXT,       &ISR_NextButton);    
RemoteDisplay      RemoteTFT;

volatile int       Action = _IDLE;             // variable de type volatile, utilisable par les ISR
String             MusicFile;                  // ID du clip MP3 en cours
String             NextMusicFile;              // ID du prochain clip MP3 à jouer
char               SlaveArduinoStatus=0;       // Status de l'Arduino Slave I2C (1=ready)                

// *******************************************************************************
// The setup function runs once when you press reset or power the board
// *******************************************************************************
void setup() 
{
    // Dès le début, on met les SlaveSelect du bus SPI au niveau haut, pour qu'ils ne reçoivent pas de messages parasites.
    pinMode(53,      OUTPUT);    digitalWrite(53,      HIGH);
    pinMode(MP3_CS,  OUTPUT);    digitalWrite(MP3_CS,  HIGH);
    pinMode(MP3_DCS, OUTPUT);    digitalWrite(MP3_DCS, HIGH);
    pinMode(SD_CS,   OUTPUT);    digitalWrite(SD_CS,   HIGH);
  
    Serial.begin(115200);
    while (!Serial) { ; } // wait for serial port to connect. Needed for native USB port only
  
    Serial.println(F("================================="));
    Serial.println(F("==    RADIAL-V     v2.4        =="));
    Serial.println(F("================================="));
    Serial.print  (F("CPU Frequency: ")); Serial.print(F_CPU/1000000); Serial.println(F(" MHz"));
    Serial.print  (F("Free RAM: "));      Serial.print(FreeRam(),DEC); Serial.println(F(" bytes"));
    // FreeRam is provided by SdFatUtil.h

    pinMode(LED_1, OUTPUT); // Led SPI BUSY (Catalog accede à la carte SD)
    pinMode(LED_2, OUTPUT);
    pinMode(K1,    OUTPUT); // Commande relay K1
    pinMode(K2,    OUTPUT); // Commande relay K2
  
    /*
    // ------------------------------------------------------------
    // Initalise le Shield FM RADIO et le bus I2C
    // A faire en premier car cela initialise aussi le bus I2C
    // ------------------------------------------------------------
    FMshield.initialize();
    if (FMshield.isReady())
        FMshield.displayInfos();
    else
    {
        // On arrive ici si c'est impossible de communiquer avec le shield FM Si4703.
        FMshield.disable();
        Serial.println(F("  FM PLAYER DISABLED.")); 
    }
    */

    // ------------------------------------------------------------
    // Initalise le bus I2C
    // ------------------------------------------------------------
    // A commenter si on initialise le bus I2C via l'initialisation de la FM 
    RemoteTFT.initI2C();

    // ------------------------------------------------------------
    // Initalise le Shield Sparkfun MP3 player
    // ------------------------------------------------------------
    MP3Player.initialize();
    // Listing des fichiers de la carte SD 
    // MP3Player.dir();
    MP3Player.setDiffmode();    // Enleve un echo acoustique désagréable
    digitalWrite(LED_1,HIGH);   // Eteint la Led témoin SPI BUSY

    // ------------------------------------------------------------
    // Initalise les autres objets
    // ------------------------------------------------------------
    Catalogue.initialize();      
    TuneButton.begin();
    NextMusicFile = "NOISE" ;   // ID du prochain clip MP3 à jouer ("STARTER")
    Action = _IDLE;

    Serial.println(F("Waiting I2C Slave ready..."));
    // -----------------------------------------------------------------------------
    // On attend que l'Arduino SLAVE soit prêt sur le bus I2C (status 0x01 = READY)
    // -----------------------------------------------------------------------------
    while (SlaveArduinoStatus!=0)
    {
       SlaveArduinoStatus=RemoteTFT.requestStatus();
       delay(100);
    }
    Serial.println(F("================================="));
    RemoteTFT.setSlavePresent(USE_TWO_ARDUINO);
}


// *******************************************************************************
// The loop function runs over and over again forever
// *******************************************************************************
void loop() 
{
  
  // -----------------------------------------------------------------------------
  // En cas de changement de source 
  // -----------------------------------------------------------------------------
  SourceButton.readPosition();
  if (SourceButton.hasChanged())
  {
    switch (SourceButton.readPosition())
    {
      // on vient de passer sur la source MUTE
      case 0: 
              Serial.println(F(">>Source has changed: MUTE"));
              // On coupe le MP3
              MP3Player.stopTrack();
              TuneButton.dischargeCapacitor();
              Serial.println(F("  Picto Mute"));
              RemoteTFT.clearBackground();
              RemoteTFT.printPictoMute();
              RemoteTFT.setBacklight(false);
              break;

      // on vient de passer sur la source MP3
      case 1: 
              Serial.println(F(">>Source has changed: MP3")); 
              setRelay(HIGH);
              Serial.println(F("  Picto OFF"));
              RemoteTFT.clearBackground();
              RemoteTFT.setBacklight(true);
              break;
   
      // on vient de passer sur la source FM
      case 2: 
              Serial.println(F(">>Source has changed: FM")); 
              setRelay(LOW);
              // On coupe le MP3
              MP3Player.stopTrack();
              Serial.println(F("  Picto FM"));
              RemoteTFT.clearBackground();
              RemoteTFT.setBacklight(true);
              RemoteTFT.printPictoFM();
              RemoteTFT.printLog(F("   PAS DE RECEPTION"));
              Serial.println(F("FM is disabled. I did not succeed to communicate with Si4703 shield with I2C bus."));
              break;
    }
  }
    
  // --------------------------------------------------------------
  // Gestion du bouton SOURCE (MP3-MUTE-FM)
  // --------------------------------------------------------------
  switch (SourceButton.getValue())
  {
    // --------------- MUTE = NO SOURCE ---------------------------
    case 0: 
            break;
    // --------------- SOURCE = MP3 -------------------------------
    case 1: loop_mp3();
            break;
    // --------------- SOURCE = FM -------------------------------
    case 2:
            /* ------------------------------------------------------------ 
            // Cette partie a été mise en commentaire car la FM ne fonctionne pas.
            // Impossible de communiquer avec le shield FM Si4703.
            // Sur le bus I2C, il répond toujours NACK.
            FMshield.setVolume(5);
            int v = FMshield.getVolume();
            Serial.println  (v);
            FMshield.setChannel(935);
            delay(3000);
            // ------------------------------------------------------------ */
            break;
  }

  // --------------------------------------------------------------
  // Temporisation de la boucle
  // --------------------------------------------------------------
  delay(1000);
}
  
  
// **************************************************************************************************************************************************************
// Loop function for MP3 source
// **************************************************************************************************************************************************************
void loop_mp3() 
{
  // --------------------------------------------------------------
  // Gestion du bouton TUNING
  // --------------------------------------------------------------
 int tuning = TuneButton.readValue();
  
  if (TuneButton.hasChanged())  
  {
      // On a détecté un changement de tuning. delta significatif + not still moving
      Serial.print(F(">>Tuning has changed: ")); Serial.println(tuning); 
      // Si le bouton TUNE a bougé, on est peut-être sur une autre année, ou un autre genre, ou autre rating.
      // On redétermine donc l'année/genre/rating correspondant à ce réglage.
      Catalogue.setNewRequestedValues(tuning);
      // On relance la recherche du clip suivant
      initClipSearch();
  }

  // --------------------------------------------------------------
  // Gestion du bouton MODE (RATING/YEAR/GENRE/RANDOM)
  // --------------------------------------------------------------
  ModeButton.readPosition();
  if (ModeButton.hasChanged())  
  {
      // On a détecté un changement de Mode. On met à jour la valeur de l'année et du genre.
      Serial.print("Mode is now "); Serial.print(ModeButton.getValue()); Serial.println(F(" [1:fav 2:year 3:genre 4:random]"));
      Catalogue.setNewRequestedValues(tuning); 
      // On relance la recherche du clip suivant
      initClipSearch();
  }

   // On actualise la recherche du clip suivant
   searchNextClip();

  // --------------------------------------------------------------
  // Gestion du clip MP3
  // --------------------------------------------------------------
  if (!MP3Player.isPlaying())      // S'il n'y a pas de morceau en cours, on en joue un.
  {
      Serial.println(F("No clip playing. Taking the next one."));
      Catalogue.takeClip();             // On prend ce qu'on a pu trouver. Le Next devient le Courant.
      MusicFile = Catalogue.getSelectedClipID();
      MP3Player.playTrack(MusicFile);   // Et on le joue (eventuellement, cela peut être Noise).
  }

   // --------------------------------------------------------------
   // Etapes que l'on fait lorsque l'on commence à jouer un MP3:
   // --------------------------------------------------------------
   int Step = MP3Player.getStep();
   switch (Step)
   {
    case 2: // On affiche le mode en cours.
            Serial.println(F("  >Send Requested Mode to TFT (from Tuning)"));
            RemoteTFT.clearBackground();
            displayRequestedMode();
            break;
    case 3: // On affiche les infos du clip issues du fichier MP3
            Serial.println(F("  >Send Title to TFT (from tag)"));
            // RemoteTFT.printLog(MusicFile);
            if (MusicFile == "NOISE") 
            {
               String message = F("Rech.");
               switch (ModeButton.getValue())
               {
                 case 1: message += F(" parmi les favoris"); break;
                 case 2: message += F(" par année");         break;
                 case 3: message += F(" par genre");         break;
                 case 4: message += F(" aléatoire");         break;
               }
               RemoteTFT.printTitle(message);
            }
            else
            {
               RemoteTFT.printTitle(MP3Player.getTitle());
               RemoteTFT.printArtist(MP3Player.getArtist());
               RemoteTFT.printAlbum(MP3Player.getAlbum());
            }
            break;
    case 4: // On affiche la suite des infos du clip issues du fichier Catalog
            Serial.println(F("  >Send Year+Genre to TFT (from Catalog)"));
            if (MusicFile == "NOISE") 
            {
              RemoteTFT.printYear(" ");
              RemoteTFT.printGenre(" ");
            }
            else
            {
              RemoteTFT.printYear(Catalogue.getSelectedClipYear());
              RemoteTFT.printGenre(Catalogue.getSelectedClipGenre());
            }
            break;
    case 5: // On determine le nombre d'étoiles et on l'affiche.
            Serial.println(F("  >Send Rating to TFT (from Catalog)"));
            if (MusicFile == "NOISE") 
              RemoteTFT.printStars("-");
            else
              RemoteTFT.printStars(Catalogue.getSelectedClipRating());
            break;
    case 12: // on surveille la RAM consommée
            Serial.print(F("Free RAM (bytes)= ")); Serial.println(FreeRam(), DEC);
            // On baisse l'intensité de l'affichage
            RemoteTFT.setBacklight(false);
            break;
   }


  // --------------------------------------------------------------
  // Gestion du bouton AGAIN/NEXT/PROMOTE (evenements déclenchés par ISR)
  // --------------------------------------------------------------
  switch (Action)
  {
       case _IDLE: break;
       case _NEXT: // On enlève une étoile et on stoppe le clip.
                        Action=_IDLE; 
                        NextButton.wasPushed();   
                        Serial.println("NEXT !");    
                        MP3Player.stopTrack();    
                        Catalogue.removeStar(); // On édite le catalog pendant que le clip est stoppé.
                        RemoteTFT.printStars(Catalogue.getSelectedClipRating());
                        break; 
       case _AGAIN: // On ajoute une étoile, et on reprend le clip du début
                        Action=_IDLE; 
                        AgainButton.wasPushed();  
                        Serial.println("AGAIN !");   
                        digitalWrite(LED_1,LOW); // Allume la Led témoin SPI BUSY
                        MP3Player.pauseDataStream();
                        Catalogue.addStar();
                        MP3Player.resumeDataStream();
                        digitalWrite(LED_1,HIGH); // Eteint la Led témoin SPI BUSY
                        MP3Player.restartTrack();
                        RemoteTFT.printStars(Catalogue.getSelectedClipRating());
                        break;
       case _PROMOTE: // On ajoute une étoile
                        Action=_IDLE; 
                        PromoteButton.wasPushed();
                        Serial.println("PROMOTE !"); 
                        digitalWrite(LED_1,LOW); // Allume la Led témoin SPI BUSY
                        MP3Player.pauseDataStream();
                        Catalogue.addStar();    
                        MP3Player.resumeDataStream();
                        digitalWrite(LED_1,HIGH); // Eteint la Led témoin SPI BUSY
                        Serial.println(F(" display: Stars"));
                        RemoteTFT.printStars(Catalogue.getSelectedClipRating());
                        break; 
  }
}

// *******************************************************************************
// Reinitialisation d'une recherche de clip dans le catalogue
// Ceci comporte un accès au fichier catalogue
// *******************************************************************************
void initClipSearch()
{
      digitalWrite(LED_1,LOW); // Allume la Led témoin SPI BUSY
      MP3Player.pauseDataStream();
      if (ModeButton.getValue()==YEAR)   Catalogue.initSearchForRequestedYear();
      if (ModeButton.getValue()==GENRE)  Catalogue.initSearchForRequestedGenre();
      if (ModeButton.getValue()==RATING) Catalogue.initSearchForRequestedRating();
      MP3Player.resumeDataStream();
      digitalWrite(LED_1,HIGH); // Eteint la Led témoin SPI BUSY
}

// *******************************************************************************
// Renvoie le prochain clip a jouer (en fonction des boutons Mode et Tuning)
// *******************************************************************************
void searchNextClip()
{
    // On lit la position du bouton de reglage, pour le cas où il aurait changé au cours du clip précédent
    int tuning = TuneButton.readValue();
    // Serial.print(F("  searchNextClip for mode ")); Serial.println(ModeButton.getValue()); 

    digitalWrite(LED_1,LOW); // Allume la Led témoin SPI BUSY
    MP3Player.pauseDataStream();
    switch (ModeButton.getValue())
    {
        case YEAR  : Catalogue.searchClipForRequestedYear();         break;
        case GENRE : Catalogue.searchClipForRequestedGenre();        break;
        case RATING: Catalogue.searchClipForRequestedRating();       break;
        case RANDOM: Catalogue.selectRandomClip();                   break;
    }
    MP3Player.resumeDataStream();
    digitalWrite(LED_1,HIGH); // Eteint la Led témoin SPI BUSY
}
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

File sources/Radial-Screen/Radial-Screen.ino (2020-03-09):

/* ************************************************************************************************
 *
 *   RADIAL-SCREEN
 *
 * Software pour la radio Radial-V.
 *
 * Pilotage par Arduino-MEGA d'un ecran TFT
 *
 *************************************************************************************************** 
 * 03/11/2015    Creation
 * 16/11/2015    Ensemble des commandes I2C. Elements graphiques 
 * 02/01/2020    Modification de cablage. Ajout de la commande I2C "CTITLE2"
 *************************************************************************************************** */

#include <Wire.h>     // Librairie Arduino pour le bus I2C
#include "RadialScreen.h"
#include "ArrayQueue.h"
#include "Display.h"


bool              Ready = false;
Display           LCDdisplay;
ArrayQueue        Fifo;

// *******************************************************************************
// The setup function runs once when you press reset or power the board
// *******************************************************************************
void setup() 
{
  // On initialise les pinoches de sorties au niveau haut.
  pinMode(SS_SLAVE, OUTPUT);    digitalWrite(SS_SLAVE, HIGH);   
  pinMode(CS_SD,    OUTPUT);    digitalWrite(CS_SD,    HIGH);   
  pinMode(CS_LD,    OUTPUT);    digitalWrite(CS_LD,    HIGH);   

  // Initialisation de la RS de debug
  Serial.begin(115200);
  
  Serial.println(F("-----------------------------------"));
  Serial.println(F("--   RADIAL SCREEN               --"));
  Serial.println(F("-----------------------------------"));

  Serial.print  (F("CPU Frequency: ")); Serial.print(F_CPU/1000000);  Serial.println(F(" MHz"));
  Serial.print  (F("Free RAM: "));      Serial.print(FreeRam(), DEC); Serial.println(F(" bytes"));   // FreeRam is provided by SdFatUtil.h
  Serial.println(F("-----------------------------------"));

  // Initialisation de la connection au bus IIC
  Wire.begin(TFT_SLAVE);                // join i2c bus with address 0x02
  Wire.onReceive(receiveEvent);         // register an event called then receiving a transmission from master
  Wire.onRequest(requestEvent);         // register an event called then receiving a request from master
  Serial.println(F("I2C initialization........done"));
  
  // Initialisation de l'écran TFT
  LCDdisplay.initDisplay();
  LCDdisplay.setBackgroundColor(BG_R,BG_G,BG_B);
  Serial.println(F("LCD initialization........done"));

  LCDdisplay.setBackgroundImage("bg_RADV.bmp");
  LCDdisplay.setBacklight(0);                   // TFT Backlight OFF

  Ready = true;
  Serial.println(F("-----------------------------------"));

}


// *******************************************************************************
// The loop function runs over and over again forever
// *******************************************************************************
void loop() 
{
  int     Command;
  String  Data;
  
  delay(40);    // 40 ms = 1 frame = 25 par secondes

  // -----------------------------------------------------------------------
  // Si le bus I2C est Ready, on traite les messages reçus
  // -----------------------------------------------------------------------
  if (Ready) 
  {
  // A-t-on reçu une commande récemment? On consulte la FIFO...
  if (!Fifo.isEmpty())  
    {
    // Si oui, on lit la commande recue
    Command = Fifo.deQueue();
    // Serial.print ("deQueue Command: ");Serial.println (Command);
    // On recupère les Data associées à la commande
    Data = Fifo.getData(Command);
    // Serial.print (" deQueue Data: ");Serial.println (Data);
    // On traite la commande
    switch (Command)
      {
      // affichage des champs textuels
      case C_TITLE    : LCDdisplay.printScrollingTitle(Data);  break;
      case C_TITLE1   : LCDdisplay.printTitle(1,Data);      break;
      case C_TITLE2   : LCDdisplay.printTitle(2,Data);      break;
      case C_ARTIST   : LCDdisplay.printArtist(Data);       break;
      case C_ALBUM    : LCDdisplay.printAlbum(Data);        break;
      case C_YEAR     : LCDdisplay.printYear(Data);         break;
      case C_GENRE    : LCDdisplay.printGenre(Data);        break;
      case C_LOG      : LCDdisplay.printLog(Data);          break;
      case C_CLEARTEXT: LCDdisplay.clearAllTexts();         break;
      // Affichage des pictos
      case C_ICON0    : LCDdisplay.clearPicto();            break;
      case C_ICON1    : LCDdisplay.showPicto(Data, 40, 20); break;    // Image size: 80x80
      case C_ICON2    : LCDdisplay.showPicto("i_AUDIO",40, 20); break;
      case C_STARS : {
                      if      (Data[0]<'0') LCDdisplay.clearStars();
                      else if (Data[0]>'5') LCDdisplay.clearStars();
                      else                  LCDdisplay.printStars(Data[0]-'0');        
                      break;
                     }
      // Autres commandes
      case C_BACKGROUNDIMAGE : LCDdisplay.setBackgroundImage("bg_RADV.bmp"); break;
      case C_CLEAR           : LCDdisplay.setBackgroundColor(BG_R,BG_G,BG_B);break;
      case C_BLON            : LCDdisplay.setBacklight(255);                 break;  
      case C_BLOFF           : LCDdisplay.setBacklight(0);                   break;
      case C_ASCII           : LCDdisplay.printAllChars();                   break;  
      // Autres cas  
      default      : 
          LCDdisplay.showPicto("i_AUDIO",40, 20);
          LCDdisplay.printLog("Unknown I2C command");             
          break;
      }
    }
  }
  
  // -----------------------------------------------------------------------
  // Si nécessaire, on fait scroller le texte déroulant.
  // -----------------------------------------------------------------------
  if (LCDdisplay.isScrolling)
  {
    LCDdisplay.scrollTitle();
  }

  bool debug = true;
  // -----------------------------------------------------------------------
  // Si debug, on écoute le port série, pour recevoir des commandes .
  //   a-z-e : augmente les valeurs rgb
  //   q-s-d : augmente les valeurs rgb
  // -----------------------------------------------------------------------
  if (debug)
  {
    int commande = 0;
    commande = Serial.read();
    // if (commande >0) {Serial.print("Received: "); Serial.println(commande, DEC);}
    switch (commande)
    {
      case 'a':
        LCDdisplay.adjustBackgroundColor(1,0,0);
        break;
    case 'q':
        LCDdisplay.adjustBackgroundColor(-1,0,0);
        break;
    case 'z': 
        LCDdisplay.adjustBackgroundColor(0,1,0);
        break;
    case 's': 
        LCDdisplay.adjustBackgroundColor(0,-1,0);
        break;
    case 'e': 
        LCDdisplay.adjustBackgroundColor(0,0,1);
        break;
    case 'd': 
        LCDdisplay.adjustBackgroundColor(0,0,-1);
        break;
    case 10:  // envoi 
        LCDdisplay.setBackground();
        break;
    }
  } 
}
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

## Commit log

2019-12-28 3D view des cartes
2019-12-29 Add docs for Spackfun FM card
    [Arduino_MEGA_2560-Rev3.brd, Arduino_MEGA_2560-Rev3.sch, Si470x-breakout-v13.brd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]
2019-12-30 Wait for I2C Slave + Unicode converter
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2020-01-01 Recabling C-MODE connector
    [Arduino_MEGA_2560-Rev3.brd, Arduino_MEGA_2560-Rev3.sch, Si470x-breakout-v13.brd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]
2020-01-02 Changement de de cablage
2020-01-11 Adding STL files (3D printed objects)
    [Radial-V ALIM.BOARD Support.stl, Radial-V Angle (D).stl, Radial-V Angle (G).stl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]
2020-01-11 3D objects updated
    [ArduinoMega2560.f3d, RADIAL-V ALIM.BOARD.f3d, Radial-V Angle (barre ARD1).stl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]
2020-01-19 Implémentation de la library pour shield FM Si7403
2020-01-20 Bus board recreated with Kicad
    [Radial-V Bus.brd, Radial-V Bus.kicad_pcb, Radial-V Bus.sch]
2020-01-21 Update Bus Board
    [MP3 Shield-v13.brd, MP3 Shield-v13.sch, MP3-Shield-Panel-v15.brd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]
2020-01-21 Routage Bus Board
    [Radial-V Bus.kicad_pcb, Radial-V Bus.sch]
2020-01-22 Bus Board
    [Radial-V Bus.kicad_pcb, Radial-V Bus.sch]
2020-01-26 Ajout de Radio Board
    [Radial-V Audio board.kicad_pcb, Radial-V Audio board.sch, Radial-V Bus.kicad_pcb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]
2020-01-26 wire fix
    [Radial-V Audio board.kicad_pcb]
2020-01-26 Regroupement de A12 et A14 sur le même connecteur
    [Radial-V Bus.kicad_pcb, Radial-V Bus.sch]
2020-01-26 Header ARD-J4 mis sur la couche Bottom
    [Radial-V Bus.kicad_pcb, Radial-V Bus.sch]
2020-01-26 Mise à jour du mapping des I/O dans Extension Board
2020-01-26 Generation des fichiers Gerber
    [Radial-V Audio board.sch, Radial-V Bus.sch]
2020-01-26 Add a Readme for Bus Board
2020-01-26 Arduino LCD screen documentation
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2020-01-29 Mise à jour des Readme
    [MP3 Shield-v13.brd, MP3 Shield-v13.sch]
2020-01-30 Update pullup for I2C.txt
2020-01-30 mise à jour des images
    [Arduino_Mega_2560-Rev3.brd, Arduino_Mega_2560-Rev3.sch, Arduino_Mega_2560.f3d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]
2020-02-01 change case of directory
2020-02-01 Ajout de nouvelles images
2020-02-03 Create RADIAL-V ALIM.BOARD.f3d v1.step
    [RADIAL-V ALIM.BOARD.f3d v1.step]
2020-02-05 3D models added
    [RADIAL-V ALIM.BOARD.f3d, RADIAL-V ALIM.BOARD.f3d v1.step, Radial-V-Alim-Board.step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]
2020-02-06 Update Audio Board
    [Radial-V Audio board.kicad_pcb, Radial-V Audio board.sch, Radial_V_Audio_Board.step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]
2020-02-07 Add PreAmplifier Board
    [Radial_V_Audio_Board.step, Radial_V_Audio_Board.stl, Velleman PreAmplifier K2572.kicad_pcb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]
2020-02-07 Add Amplfier board
    [Radial-V Audio board.kicad_pcb, Velleman Amplifier VM114.kicad_pcb, Velleman Amplifier VM114.sch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]
2020-02-09 Velleman Amplifier Board
    [Support for Extension Board v17.stl, Support for LCD.stl, Velleman Amplifier VM114 v1.stl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]
2020-02-09 STL models added
    [ArduinoMega2560.step, Arduino_Mega_2560.f3d, RADIAL-V Alim Board.stl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]
2020-02-09 STL model added
    [Radial-V-Audio-Board.step, Radial-V-Audio-Board.stl, Radial-V-Bus-Board-v1.stl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]
2020-02-09 Adding preamplifier 3D model
    [Velleman PreAmplifier K2572.kicad_pcb, Velleman PreAmplifier K2572.sch, Velleman PreAmplifier K2572.step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]
2020-02-09 Update Velleman PreAmplifier K2572.sch
    [Velleman PreAmplifier K2572.sch]
2020-02-16 Audio support 3D model
    [Radial-V-ALIM.BOARD-Support.stl, Support Audio Board.stl]
2020-02-16 fichiers remis dans le bon repertoire...
    [Radial-V-ALIM.BOARD-Support.stl, Support Audio Board.stl]
2020-02-20 Updated models
    [Arduino_LCD_Board.stl, Grille v6.stl, Radial-V Extension Board.step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]
2020-02-23 Remmaping des E/S après installation BusBoard V2
2020-02-23 Essai de vérification si Arduino Slave present
    Peut être utile car la librarie WIRE se bloque s'il n'y a pas de Slave I2C.
2020-02-24 Aout de la possibilité de tester avec Arduino 2 deconnecté
2020-03-02 Calibrage de la Capa Variable (in progress)
2020-03-04 Mersure de la Capa
    par une meilleure méthode
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2020-04-10 There are I2C NACK errors
    [Radial-V.ino, RemoteDisplay.ino]
2020-04-13 Le code pour la FM est en place: masi ABANDON
    Abandon de la foncrtionnalité FM, car impossible de communiquer avec la carte Si4703.
    La librairie reste en place, ainsi de futures tentatives restent possibles...
2020-04-16 Tests unitaires de la carte FM.
    NACK si on met des adaptations de tension.
    OK si on ne met aucune adaptation...
    génial....
2020-04-20 Adding Amplifier Shunt board
    [Radial-V PreAmplifier Shunt.kicad_pcb, Radial-V PreAmplifier Shunt.sch, Radial-V PreAmplifier Shunt.step]
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2020-05-16 Ajout des mini-cartes "Audio Adapter" et "Capa Adapter" et "PreAmp Shunt"
    [Radial-V PreAmplifier Shunt.step, Velleman PreAmplifier K2572.kicad_pcb, Velleman PreAmplifier K2572.sch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]
2020-05-17 Cleanup 3D models
    [ArduinoMega2560.step, Arduino_LCD_Board.stl, Radial-V Alim.brd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]
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2020-05-25 Détails du fichier Catalog
    [Radial-V PreAmplifier Shunt.step]
2020-08-01 update des tools
    [Capacitors.xlsx, capacité variable.xlsx, metrologie.xlsx]
2020-10-15 Directory change
    [Capacitors.xlsx, capacité variable.xlsx, metrologie.xlsx]
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2024-02-11 Images et photos
    Détourage
    [Boitier Adapter Capa.stl, Boitier_Adaptateur_Audio.stl, Couvercle Adaptateur Audio.stl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]

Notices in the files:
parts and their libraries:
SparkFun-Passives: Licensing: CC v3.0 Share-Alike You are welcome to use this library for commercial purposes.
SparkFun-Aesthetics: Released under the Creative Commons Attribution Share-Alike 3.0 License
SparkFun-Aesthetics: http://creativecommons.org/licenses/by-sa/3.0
